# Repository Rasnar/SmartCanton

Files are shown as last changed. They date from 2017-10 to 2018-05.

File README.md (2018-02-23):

# Master Thesis - SmartCanton

This repository contain the Master Thesis relised by **Da Silva Andrade David** in collaboration with the DIRECTION GÉNÉRALE DES SYSTÈMES D'INFORMATION (**DGSI**).

The goal of this project is to devellop a device that can connect to a LoRaWAN and provide sensor data that can be trusted from a specific device.

A securised interface was also devellopped to delivers the APPKEY to the new device created. The principle of creation and storage is based on the Proof of Concept devellopped by the DGSI for the project SmartCanton.

## Hardware

A PCB has been devellopped for this project. 

- Bluetooth LE 4.2 : **MKW41Z512**
- LoRa : **CMWX1ZZABZ-078** (SX1276 + STM32L082)
- GPS : **NEO-M8Q** (only with external antenna)
- On board antennas for the LoRa and Bluetooth. Possibility to connect external antennas in both cases.
- 9 Axis inertial platform : **BNO055**
- Gas, temperature and humidity sensor : **BME680**
- 8 LEDs and 4 Buttons accessible both by the LoRa and Bluetooth microcontrollers
- 2 PMOD connectors (1 for each microcontroller)
- Possibility to connect a Li-Ion battery
- USB or Solar charging for the Li-Ion battery

The Altium layout of the board is avaiblable under the directory `SmartCanton\hardware\SmartCantonDevBox_V1_0`.

A case for the hardware has also been designed. You can find it under`SmartCanton\hardware\SmartCantonDevBoxCase`. It can be easily printed using a 3D printer.

## Software

### LoRaWAN

The software for the CMWX1ZZABZ-078 can be found under the directory `SmartCanton\dev\STM32CubeExpansion_LRWAN_V1.1.2`. It requires to be open with the STM32 Workbench IDE.

### Bluetooth

The software for the NXP KW41Z can be found under the directory `SmartCanton\dev\MKW41z`. It requires to be open with the MCUXpresso IDE.

### Android

An Application developed with Android Studio is available under the directory `SmartCanton\dev\SmartCantonManager`.

### Web Server

A web server developed using Python 3.6 and Pycharm has been developed. It run coupled with a SQLite to store all the information about the users and the DevBox (LoRaWAN et BLE configurations).

The project can be opened with Pycharm under the directory `SmartCanton\dev\SmartCanton_AppKeyServer`.

## Documentation

The final report of the project can be found in the root tree of the project under the name `[Da_Silva_Andrade_TM_2017-2018.pdf](https://github.com/Rasnar/SmartCanton/blob/master/Da_Silva_Andrade_TM_2017-2018.pdf)`. It's written in French, with appendices in English. The REST API documentation, an user guide for the Android application and all the BLE services developed can be found as appendices in the PDF file.

All the documentation can be found under the `SmartCanton\documentation` directory.

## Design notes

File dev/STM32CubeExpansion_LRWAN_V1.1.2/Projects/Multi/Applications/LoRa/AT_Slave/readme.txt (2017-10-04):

/**
  @page AT_Slave Readme file
 
  @verbatim
  ******************** (C) COPYRIGHT 2017 STMicroelectronics *******************
  * @file    AT_Slave/readme.txt 
  * @author  MCD Application Team
  * @version V1.1.2
  * @date    08-September-2017
  * @brief   This application is a simple demo application software of a LoRa
  *          modem controlled though AT command interface over UART by an
  *          external host
  ******************************************************************************
  * @attention
  *
  * <h2><center>&copy; Copyright (c) 2017 STMicroelectronics International N.V. 
  * All rights reserved.</center></h2>
  *
  * Redistribution and use in source and binary forms, with or without 
  * modification, are permitted, provided that the following conditions are met:
  *
  * 1. Redistribution of source code must retain the above copyright notice, 
  *    this list of conditions and the following disclaimer.
  * 2. Redistributions in binary form must reproduce the above copyright notice,
  *    this list of conditions and the following disclaimer in the documentation
  *    and/or other materials provided with the distribution.
  * 3. Neither the name of STMicroelectronics nor the names of other 
  *    contributors to this software may be used to endorse or promote products 
  *    derived from this software without specific written permission.
  * 4. This software, including modifications and/or derivative works of this 
  *    software, must execute solely and exclusively on microcontroller or
  *    microprocessor devices manufactured by or for STMicroelectronics.
  * 5. Redistribution and use of this software other than as permitted under 
  *    this license is void and will automatically terminate your rights under 
  *    this license. 
  *
  * THIS SOFTWARE IS PROVIDED BY STMICROELECTRONICS AND CONTRIBUTORS "AS IS" 
  * AND ANY EXPRESS, IMPLIED OR STATUTORY WARRANTIES, INCLUDING, BUT NOT 
  * LIMITED TO, THE IMPLIED WARRANTIES OF MERCHANTABILITY, FITNESS FOR A 
  * PARTICULAR PURPOSE AND NON-INFRINGEMENT OF THIRD PARTY INTELLECTUAL PROPERTY
  * RIGHTS ARE DISCLAIMED TO THE FULLEST EXTENT PERMITTED BY LAW. IN NO EVENT 
  * SHALL STMICROELECTRONICS OR CONTRIBUTORS BE LIABLE FOR ANY DIRECT, INDIRECT,
  * INCIDENTAL, SPECIAL, EXEMPLARY, OR CONSEQUENTIAL DAMAGES (INCLUDING, BUT NOT
  * LIMITED TO, PROCUREMENT OF SUBSTITUTE GOODS OR SERVICES; LOSS OF USE, DATA, 
  * OR PROFITS; OR BUSINESS INTERRUPTION) HOWEVER CAUSED AND ON ANY THEORY OF 
  * LIABILITY, WHETHER IN CONTRACT, STRICT LIABILITY, OR TORT (INCLUDING 
  * NEGLIGENCE OR OTHERWISE) ARISING IN ANY WAY OUT OF THE USE OF THIS SOFTWARE,
  * EVEN IF ADVISED OF THE POSSIBILITY OF SUCH DAMAGE.
  *
  ******************************************************************************
   @endverbatim

@par Description

This directory contains a set of source files that implements an example of a LoRa
modem that is controlled though AT command interface over UART by an external host,
like a computer executing a terminal.

This application is targeting the B-L072Z-LRWAN1 Discovery board embedding the
CMWX1ZZABZ-091 LoRa module.

This application uses the Cube Low Layer drivers APIs targeting the STM32L0
(embedded in the module) to optimize the code size.
  ******************************************************************************

@par Directory contents 

  - AT_Slave/Inc/at.h                     Header for at.c
  - AT_Slave/Inc/Comissioning.h           End device comissioning parameters
  - AT_Slave/Inc/command.h                Header for command.c
  - AT_Slave/Inc/debug.h                  Interface to debug functionally
  - AT_Slave/Inc/hw.h                     Group all hw interface
  - AT_Slave/Inc/hw_conf.h                File to manage Cube SW family used and debug switch
  - AT_Slave/Inc/hw_gpio.h                Header for hw_gpio.c
  - AT_Slave/Inc/hw_msp.h                 Header for driver hw msp module
  - AT_Slave/Inc/hw_rtc.h                 Header for hw_rtc.c
  - AT_Slave/Inc/hw_spi.h                 Header for hw_spi.c
  - AT_Slave/Inc/lora.h                   Header for lora.c
  - AT_Slave/Inc/mlm32l0xx_hw_conf.h      Definitions for mlm32l0xx HW configuration
  - AT_Slave/Inc/mlm32l0xx_it.h           Header for mlm32l0xx_it.c
  - AT_Slave/Inc/stm32l0xx_hal_conf.h     Library Configuration file
  - AT_Slave/Inc/tiny_sscanf.h            Header for tiny_sscanf.c
  - AT_Slave/Inc/tiny_vsnprintf.h         Header for tiny_vsnprintf.c
  - AT_Slave/Inc/vcom.h                   Interface to vcom.c
  - AT_Slave/Inc/version.h                Version file
  
  - AT_Slave/Src/at.c                     AT commands API
  - AT_Slave/Src/command.c                Definitions of AT commands
  - AT_Slave/Src/debug.c                  Debug driver
  - AT_Slave/Src/hw_gpio.c                Gpio driver
  - AT_Slave/Src/hw_rtc.c                 Rtc driver
  - AT_Slave/Src/hw_spi.c                 Spi driver
  - AT_Slave/Src/lora.c                   LoRa API to drive the LoRa state machine
  - AT_Slave/Src/main.c                   Main program file
  - AT_Slave/Src/mlm32l0xx_hw.c           MLM32l0xx specific hardware driver code
  - AT_Slave/Src/mlm32l0xx_it.c           MLM32l0xx Interrupt handlers
  - AT_Slave/Src/tiny_sscanf.c            Tiny implementation of sscanf() like function
  - AT_Slave/Src/tiny_vsnprintf.c         Tiny implementation of vsnprintf() like function
  - AT_Slave/Src/vcom.c                   Virtual com port interface on Terminal

@par Hardware and Software environment 

  - This example runs on the B-L072Z-LRWAN1 Discovery board embedding the
    CMWX1ZZABZ-091 LoRa module, and has been tested with STMicroelectronics
    B-L072Z-LRWAN1 RevC board.

  - B-L072Z-LRWAN1 Discovery board Set-up    
    - Connect the Nucleo board to your PC with a USB cable type A to micro-B 
      to ST-LINK connector (CN7).
    - Please ensure that the ST-LINK connector CN8 jumpers are fitted.
  -Set Up:

             --------------------------  V    V  --------------------------
             |      LoRa Object       |  |    |  |      LoRa Network      |
             |                        |  |    |  |                        |
   ComPort<--|                        |--|    |--|                        |-->Web Server
             |                        |          |                        |
             --------------------------          --------------------------

@par How to use it ? 
In order to make the program work, you must do the following :
  - Open your preferred toolchain 
  - Rebuild all files and load your image into target memory
  - Run the example
  - Open a Terminal, connected the LoRa Object
  - UART Config = 9600, 8b, 1 stopbit, no parity, no flow control ( in src/vcom.c)
  - Terminal Config: Select 'CR+LF' for Transmit New-Line and switch 'Local echo' on
  - Send your AT commands by typing them in the terminal
   
 * <h3><center>&copy; COPYRIGHT STMicroelectronics</center></h3>
 */

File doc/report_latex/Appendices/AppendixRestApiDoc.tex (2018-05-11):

% Appendix Template

\appendixpagenumbering % Restart numbering for each appendix

\chapter{AppKey Server: REST API Documentation} % Main appendix title
\label{AppendixRestApiDoc} 

This document contain all the routes available on the AppKeyServer. The \cref{figapdx-database_model} illustrate the database model used by the server.

\begin{figure}[ht!]
    \centering
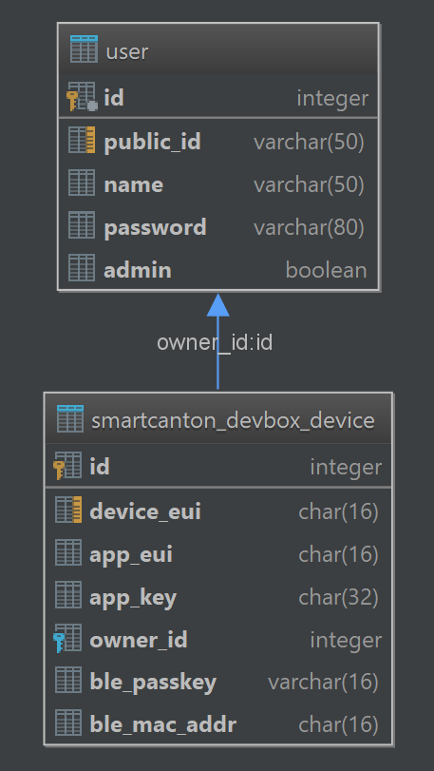
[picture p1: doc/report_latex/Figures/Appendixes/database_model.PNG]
    
    \caption{Database model}
    \label{figapdx-database_model}
\end{figure}

This documentation is also provided on the root path of the server : 

\begin{tcolorbox}[top=-3mm, bottom=-3mm, left=0mm, right=0mm, enhanced, breakable, colback=LightGray, colframe=DarkGray, colbacktitle=DarkGray]
\begin{minted}[bgcolor=LightGray,fontsize=\footnotesize,breaklines]{bash}
$ curl -X GET https://127.0.0.1:5000/
\end{minted}
\end{tcolorbox}

\clearpage
%%%%%%%%%%%%%%%%%%%%%%%%%%%%%%%%%%%%%%%%%%%%%%%%%%%%%%%%%%%
\section{Authentification}
%%%%%%%%%%%%%%%%%%%%%%%%%%%%%%%%%%%%%%%%%%%%%%%%%%%%%%%%%%%

\underline{Command rights} : Anyone can request a JWT token. The only requirement it that the user/password combinaison on the POST body is correct.\\

\textbf{Curl command for a JWT authentification :}

\begin{tcolorbox}[top=-3mm, bottom=-3mm, left=0mm, right=0mm, enhanced, breakable, colback=LightGray, colframe=DarkGray, colbacktitle=DarkGray]
\begin{minted}[bgcolor=LightGray,fontsize=\footnotesize,breaklines]{bash}
$ curl -X POST \
  http://127.0.0.1:5000/auth \
  -H 'cache-control: no-cache' \
  -H 'content-type: application/json' \
  -d '{
    "username": "<YOUR_USERNAME",
    "password": "<YOUR_PASSWORD>"
}'
\end{minted}
\end{tcolorbox}

\textbf{Example of a correct response (HTTP code 200) :}

\begin{tcolorbox}[top=-3mm, bottom=-3mm, left=0mm, right=0mm, enhanced, breakable, colback=LightGray, colframe=DarkGray, colbacktitle=DarkGray]
\begin{minted}[bgcolor=LightGray,fontsize=\footnotesize,breaklines]{bash}
{
    "access_token": "eyJ0eXAiOiJKV1QiLCJhbGciOiJIUzI1NiJ9.eyJleHAiOjE1MTg0ND
    g2MDcsImlhdCI6MTUxNTg1NjYwNywibmJmIjoxNTE1ODU2NjA3LCJqdGkiOiIyYmE5NDE2ZC
    1lOTVmLTQ3ZDktYmM0Ny0xOTY4MmY5NzlhMTMiLCJwdWJsaWNfaWQiOiJkZjQ1ZThlMi02ZT
    EwLTRlYmEtOGJjZC0yMjJjYWNlMjk3NGUiLCJmcmVzaCI6ZmFsc2UsInR5cGUiOiJhY2Nlc3
    MifQ.2XzkxKE-qDDtooZGfW2Gp5tYXISvnUH1QHibyGSAkAI"
}
\end{minted}
\end{tcolorbox}

\textbf{Token decrypted :} 

\begin{tcolorbox}[top=-3mm, bottom=-3mm, left=0mm, right=0mm, enhanced, breakable, colback=LightGray, colframe=DarkGray, colbacktitle=DarkGray]
\begin{minted}[bgcolor=LightGray,fontsize=\footnotesize,breaklines]{bash}
{
  "typ": "JWT",
  "alg": "HS256"
}
{
  "exp": 1518448607,
  "iat": 1515856607,
  "nbf": 1515856607,
  "jti": "2ba9416d-e95f-47d9-bc47-19682f979a13",
  "public_id": "df45e8e2-6e10-4eba-8bcd-222cace2974e",
  "fresh": false,
  "type": "access"
}
\end{minted}
\end{tcolorbox}

\clearpage
\section{User routes}

Those routes are only used to manage the user information. It does not interfer with the existing SmartCanton DevBox devices.

%%%%%%%%%%%%%%%%%%%%%%%%%%%%%%%%%%%%%%%%%%%%%%%%%%%%%%%%%%%
\subsection{Get all users}
%%%%%%%%%%%%%%%%%%%%%%%%%%%%%%%%%%%%%%%%%%%%%%%%%%%%%%%%%%%

\underline{Command rights} : \textbf{Admin only}\\

\textbf{Curl command :}

\begin{tcolorbox}[top=-3mm, bottom=-3mm, left=0mm, right=0mm, enhanced, breakable, colback=LightGray, colframe=DarkGray, colbacktitle=DarkGray]
\begin{minted}[bgcolor=LightGray,fontsize=\footnotesize,breaklines]{bash}
$ curl -X GET \
  https://127.0.0.1:5000/user/df45e8e2-6e10-4eba-8bcd-222cace2974e \
  -H 'authorization: JWT eyJ0eXAiOiJKV1QiLCJhbGciOiJIUzI1NiJ9.eyJl
  eHAiOjE1MTg0NDg2MDcsImlhdCI6MTUxNTg1NjYwNywibmJmIjoxNTE1ODU2NjA3
  LCJqdGkiOiIyYmE5NDE2ZC1lOTVmLTQ3ZDktYmM0Ny0xOTY4MmY5NzlhMTMiLCJw
  dWJsaWNfaWQiOiJkZjQ1ZThlMi02ZTEwLTRlYmEtOGJjZC0yMjJjYWNlMjk3NGUi
  LCJmcmVzaCI6ZmFsc2UsInR5cGUiOiJhY2Nlc3MifQ.2XzkxKE-qDDtooZGfW2Gp
  5tYXISvnUH1QHibyGSAkAI' \
  -H 'cache-control: no-cache'
\end{minted}
\end{tcolorbox}

\textbf{Example of a correct response (HTTP code 200) : }

\begin{tcolorbox}[top=-3mm, bottom=-3mm, left=0mm, right=0mm, enhanced, breakable, colback=LightGray, colframe=DarkGray, colbacktitle=DarkGray]
\begin{minted}[bgcolor=LightGray,fontsize=\footnotesize,breaklines]{bash}
{
    "users": [
        {
            "admin": true,
            "name": "Admin",
            "public_id": "df45e8e2-6e10-4eba-8bcd-222cace2974e"
        },
        {
            "admin": false,
            "name": "david",
            "public_id": "93cb11d2-bbdd-4d2a-8e66-e970e6d6bd25"
        },
        {
            "admin": true,
            "name": "david2",
            "public_id": "0b6a165d-5126-46da-bd0d-9d35bdda4bfd"
        }
    ]
}
\end{minted}
\end{tcolorbox}

%%%%%%%%%%%%%%%%%%%%%%%%%%%%%%%%%%%%%%%%%%%%%%%%%%%%%%%%%%%%%%%%%%%%%%%%%%%%%%%%%%%%%
\subsection{Get a specific user information from a public id}
%%%%%%%%%%%%%%%%%%%%%%%%%%%%%%%%%%%%%%%%%%%%%%%%%%%%%%%%%%%%%%%%%%%%%%%%%%%%%%%%%%%%%

\underline{Command rights} : Non admin users can only see their own profiles. Admin users can access all profiles.\\

\textbf{Curl command :}

\begin{tcolorbox}[top=-3mm, bottom=-3mm, left=0mm, right=0mm, enhanced, breakable, colback=LightGray, colframe=DarkGray, colbacktitle=DarkGray]
\begin{minted}[bgcolor=LightGray,fontsize=\footnotesize,breaklines]{bash}
$ curl -X GET \
  https://127.0.0.1:5000/user/df45e8e2-6e10-4eba-8bcd-222cace2974e \
  -H 'authorization: JWT eyJ0eXAiOiJKV1QiLCJhbGciOiJIUzI1NiJ9.eyJl
  eHAiOjE1MTg0NDg2MDcsImlhdCI6MTUxNTg1NjYwNywibmJmIjoxNTE1ODU2NjA3
  LCJqdGkiOiIyYmE5NDE2ZC1lOTVmLTQ3ZDktYmM0Ny0xOTY4MmY5NzlhMTMiLCJw
  dWJsaWNfaWQiOiJkZjQ1ZThlMi02ZTEwLTRlYmEtOGJjZC0yMjJjYWNlMjk3NGUi
  LCJmcmVzaCI6ZmFsc2UsInR5cGUiOiJhY2Nlc3MifQ.2XzkxKE-qDDtooZGfW2Gp
  5tYXISvnUH1QHibyGSAkAI' \
  -H 'cache-control: no-cache' 
\end{minted}
\end{tcolorbox}

\textbf{Example of a correct response (HTTP code 200) : }

\begin{tcolorbox}[top=-3mm, bottom=-3mm, left=0mm, right=0mm, enhanced, breakable, colback=LightGray, colframe=DarkGray, colbacktitle=DarkGray]
\begin{minted}[bgcolor=LightGray,fontsize=\footnotesize,breaklines]{bash}
{
    "admin": true,
    "public_id": "df45e8e2-6e10-4eba-8bcd-222cace2974e",
    "username": "Admin"
}
\end{minted}
\end{tcolorbox}

%%%%%%%%%%%%%%%%%%%%%%%%%%%%%%%%%%%%%%%%%%%%%%%%%%%%%%%%%%%%%%%%%%%%%%%%%%%%%%%%%%%%%
\subsection{Update information about a specific user}
%%%%%%%%%%%%%%%%%%%%%%%%%%%%%%%%%%%%%%%%%%%%%%%%%%%%%%%%%%%%%%%%%%%%%%%%%%%%%%%%%%%%%

\underline{Command rights} : Non admin users can only change their own profile and can't give themselves the Admin rights. They need to know their current password to be able to change it. Admin users can change all profiles and passwords, even if they don't know the old password.\\

\textbf{Curl command :}

\begin{tcolorbox}[top=-3mm, bottom=-3mm, left=0mm, right=0mm, enhanced, breakable, colback=LightGray, colframe=DarkGray, colbacktitle=DarkGray]
\begin{minted}[bgcolor=LightGray,fontsize=\footnotesize,breaklines]{bash}
$ curl -X PUT \
  https://127.0.0.1:5000/user/df45e8e2-6e10-4eba-8bcd-222cace2974e \
  -H 'authorization: JWT eyJ0eXAiOiJKV1QiLCJhbGciOiJIUzI1NiJ9.eyJl
  eHAiOjE1MTg0NDg2MDcsImlhdCI6MTUxNTg1NjYwNywibmJmIjoxNTE1ODU2NjA3
  LCJqdGkiOiIyYmE5NDE2ZC1lOTVmLTQ3ZDktYmM0Ny0xOTY4MmY5NzlhMTMiLCJw
  dWJsaWNfaWQiOiJkZjQ1ZThlMi02ZTEwLTRlYmEtOGJjZC0yMjJjYWNlMjk3NGUi
  LCJmcmVzaCI6ZmFsc2UsInR5cGUiOiJhY2Nlc3MifQ.2XzkxKE-qDDtooZGfW2Gp
  5tYXISvnUH1QHibyGSAkAI' \
  -H 'cache-control: no-cache' \
  -H 'content-type: application/json' \
  -d '{
	"password" : "test",
	"new_password" : "SmartCanton2017",
	"admin" : true
}'
\end{minted}
\end{tcolorbox}

\textbf{Example of a correct response (HTTP code 200) : }

\begin{tcolorbox}[top=-3mm, bottom=-3mm, left=0mm, right=0mm, enhanced, breakable, colback=LightGray, colframe=DarkGray, colbacktitle=DarkGray]
\begin{minted}[bgcolor=LightGray,fontsize=\footnotesize,breaklines]{bash}
{
    "message": "User information updated!"
}
\end{minted}
\end{tcolorbox}

%%%%%%%%%%%%%%%%%%%%%%%%%%%%%%%%%%%%%%%%%%%%%%%%%%%%%%%%%%%%%%%%%%%%%%%%%%%%%%%%%%%%%
\subsection{Create a new user}
%%%%%%%%%%%%%%%%%%%%%%%%%%%%%%%%%%%%%%%%%%%%%%%%%%%%%%%%%%%%%%%%%%%%%%%%%%%%%%%%%%%%%

\underline{Command rights} : \textbf{Admin only}\\

\textbf{Curl command :}

\begin{tcolorbox}[top=-3mm, bottom=-3mm, left=0mm, right=0mm, enhanced, breakable, colback=LightGray, colframe=DarkGray, colbacktitle=DarkGray]
\begin{minted}[bgcolor=LightGray,fontsize=\footnotesize,breaklines]{bash}
$ curl -X POST \
  http://127.0.0.1:5000/user \
  -H 'authorization: JWT eyJ0eXAiOiJKV1QiLCJhbGciOiJIUzI1NiJ9.eyJl
  eHAiOjE1MTg0NDg2MDcsImlhdCI6MTUxNTg1NjYwNywibmJmIjoxNTE1ODU2NjA3
  LCJqdGkiOiIyYmE5NDE2ZC1lOTVmLTQ3ZDktYmM0Ny0xOTY4MmY5NzlhMTMiLCJw
  dWJsaWNfaWQiOiJkZjQ1ZThlMi02ZTEwLTRlYmEtOGJjZC0yMjJjYWNlMjk3NGUi
  LCJmcmVzaCI6ZmFsc2UsInR5cGUiOiJhY2Nlc3MifQ.2XzkxKE-qDDtooZGfW2Gp
  5tYXISvnUH1QHibyGSAkAI' \
  -H 'cache-control: no-cache' \
  -H 'content-type: application/json' \
  -d '{"username": "david2", "password": "SmartCanton"}'
\end{minted}
\end{tcolorbox}

\newpage
\textbf{Example of a correct response (HTTP code 200) : }

\begin{tcolorbox}[top=-3mm, bottom=-3mm, left=0mm, right=0mm, enhanced, breakable, colback=LightGray, colframe=DarkGray, colbacktitle=DarkGray]
\begin{minted}[bgcolor=LightGray,fontsize=\footnotesize,breaklines]{bash}
{
    "message": "New user created!"
}
\end{minted}
\end{tcolorbox}

%%%%%%%%%%%%%%%%%%%%%%%%%%%%%%%%%%%%%%%%%%%%%%%%%%%%%%%%%%%%%%%%%%%%%%%%%%%%%%%%%%%%%
\subsection{Delete an existing user}
%%%%%%%%%%%%%%%%%%%%%%%%%%%%%%%%%%%%%%%%%%%%%%%%%%%%%%%%%%%%%%%%%%%%%%%%%%%%%%%%%%%%%
\underline{Command rights} : \textbf{Admin only}\\

\textbf{Curl command :}

\begin{tcolorbox}[top=-3mm, bottom=-3mm, left=0mm, right=0mm, enhanced, breakable, colback=LightGray, colframe=DarkGray, colbacktitle=DarkGray]
\begin{minted}[bgcolor=LightGray,fontsize=\footnotesize,breaklines]{bash}
$ curl -X DELETE \
  https://127.0.0.1:5000/user/88320280-42c6-4ad1-b747-cc4844580fa7 \
  -H 'authorization: JWT eyJ0eXAiOiJKV1QiLCJhbGciOiJIUzI1NiJ9.eyJl
  eHAiOjE1MTg0NDg2MDcsImlhdCI6MTUxNTg1NjYwNywibmJmIjoxNTE1ODU2NjA3
  LCJqdGkiOiIyYmE5NDE2ZC1lOTVmLTQ3ZDktYmM0Ny0xOTY4MmY5NzlhMTMiLCJw
  dWJsaWNfaWQiOiJkZjQ1ZThlMi02ZTEwLTRlYmEtOGJjZC0yMjJjYWNlMjk3NGUi
  LCJmcmVzaCI6ZmFsc2UsInR5cGUiOiJhY2Nlc3MifQ.2XzkxKE-qDDtooZGfW2Gp
  5tYXISvnUH1QHibyGSAkAI' \
  -H 'cache-control: no-cache' 
\end{minted}
\end{tcolorbox}

\textbf{Example of a correct response (HTTP code 200) : }

\begin{tcolorbox}[top=-3mm, bottom=-3mm, left=0mm, right=0mm, enhanced, breakable, colback=LightGray, colframe=DarkGray, colbacktitle=DarkGray]
\begin{minted}[bgcolor=LightGray,fontsize=\footnotesize,breaklines]{bash}
{
    "message": "The user has been deleted!"
}
\end{minted}
\end{tcolorbox}

%-----------------------------------------------------------------------------------%
\section{SmartCanton DevBox routes}
%-----------------------------------------------------------------------------------%
Those routes are only used to manage the DevBox devices. You will need to know the user informations to update or understand the \textit{owner\_public\_id} field. 
%%%%%%%%%%%%%%%%%%%%%%%%%%%%%%%%%%%%%%%%%%%%%%%%%%%%%%%%%%%%%%%%%%%%%%%%%%%%%%%%%%%%%
\subsection{Get all devices}
%%%%%%%%%%%%%%%%%%%%%%%%%%%%%%%%%%%%%%%%%%%%%%%%%%%%%%%%%%%%%%%%%%%%%%%%%%%%%%%%%%%%%
\underline{Command rights} : Non admin users can only see their own devices (those where their public id is used as the owner id). Admin users can see all devices.\\

\textbf{Curl command :}

\begin{tcolorbox}[top=-3mm, bottom=-3mm, left=0mm, right=0mm, enhanced, breakable, colback=LightGray, colframe=DarkGray, colbacktitle=DarkGray]
\begin{minted}[bgcolor=LightGray,fontsize=\footnotesize,breaklines]{bash}
$ curl -X GET \
  https://127.0.0.1:5000/device \
  -H 'authorization: JWT eyJ0eXAiOiJKV1QiLCJhbGciOiJIUzI1NiJ9.eyJl
  eHAiOjE1MTg0NDg2MDcsImlhdCI6MTUxNTg1NjYwNywibmJmIjoxNTE1ODU2NjA3
  LCJqdGkiOiIyYmE5NDE2ZC1lOTVmLTQ3ZDktYmM0Ny0xOTY4MmY5NzlhMTMiLCJw
  dWJsaWNfaWQiOiJkZjQ1ZThlMi02ZTEwLTRlYmEtOGJjZC0yMjJjYWNlMjk3NGUi
  LCJmcmVzaCI6ZmFsc2UsInR5cGUiOiJhY2Nlc3MifQ.2XzkxKE-qDDtooZGfW2Gp
  5tYXISvnUH1QHibyGSAkAI' \
  -H 'cache-control: no-cache' 
\end{minted}
\end{tcolorbox}

\newpage
\textbf{Example of a correct response (HTTP code 200) : }

\begin{tcolorbox}[top=-3mm, bottom=-3mm, left=0mm, right=0mm, enhanced, breakable, colback=LightGray, colframe=DarkGray, colbacktitle=DarkGray]
\begin{minted}[bgcolor=LightGray,fontsize=\footnotesize,breaklines]{bash}
{
    "devices": [
        {
            "ble_mac_addr": "006037000000",
            "dev_eui": "323831395C367815"
        },
        {
            "ble_mac_addr": "006037000001",
            "dev_eui": "323831395C367715"
        }
    ]
}
\end{minted}
\end{tcolorbox}

%%%%%%%%%%%%%%%%%%%%%%%%%%%%%%%%%%%%%%%%%%%%%%%%%%%%%%%%%%%%%%%%%%%%%%%%%%%%%%%%%%%%%
\subsection{Get information about a specific device}
%%%%%%%%%%%%%%%%%%%%%%%%%%%%%%%%%%%%%%%%%%%%%%%%%%%%%%%%%%%%%%%%%%%%%%%%%%%%%%%%%%%%%
\underline{Command rights} : Non admin users can only see their own devices (those where their public id is used as the owner id). Admin users can see all devices.\\

\textbf{Curl command :}

\begin{tcolorbox}[top=-3mm, bottom=-3mm, left=0mm, right=0mm, enhanced, breakable, colback=LightGray, colframe=DarkGray, colbacktitle=DarkGray]
\begin{minted}[bgcolor=LightGray,fontsize=\footnotesize,breaklines]{bash}
$ curl -X GET \
  https://127.0.0.1:5000/device/006037000001 \
  -H 'authorization: JWT eyJ0eXAiOiJKV1QiLCJhbGciOiJIUzI1NiJ9.eyJl
  eHAiOjE1MTg0NDg2MDcsImlhdCI6MTUxNTg1NjYwNywibmJmIjoxNTE1ODU2NjA3
  LCJqdGkiOiIyYmE5NDE2ZC1lOTVmLTQ3ZDktYmM0Ny0xOTY4MmY5NzlhMTMiLCJw
  dWJsaWNfaWQiOiJkZjQ1ZThlMi02ZTEwLTRlYmEtOGJjZC0yMjJjYWNlMjk3NGUi
  LCJmcmVzaCI6ZmFsc2UsInR5cGUiOiJhY2Nlc3MifQ.2XzkxKE-qDDtooZGfW2Gp
  5tYXISvnUH1QHibyGSAkAI' \
  -H 'cache-control: no-cache' 
\end{minted}
\end{tcolorbox}

\textbf{Example of a correct response (HTTP code 200) : }

\begin{tcolorbox}[top=-3mm, bottom=-3mm, left=0mm, right=0mm, enhanced, breakable, colback=LightGray, colframe=DarkGray, colbacktitle=DarkGray]
\begin{minted}[bgcolor=LightGray,fontsize=\footnotesize,breaklines]{bash}
{
    "app_eui": "<APP_EUI>",
    "app_key": "<APP_KEY>",
    "ble_mac_addr": "006037000001",
    "ble_passkey": "111100",
    "dev_eui": "323831395C367715",
    "owner_public_id": "df45e8e2-6e10-4eba-8bcd-222cace2974e"
}
\end{minted}
\end{tcolorbox}

%%%%%%%%%%%%%%%%%%%%%%%%%%%%%%%%%%%%%%%%%%%%%%%%%%%%%%%%%%%%%%%%%%%%%%%%%%%%%%%%%%%%%
\subsection{Create a new device}
%%%%%%%%%%%%%%%%%%%%%%%%%%%%%%%%%%%%%%%%%%%%%%%%%%%%%%%%%%%%%%%%%%%%%%%%%%%%%%%%%%%%%
\underline{Command rights} : Devices are automatically assigned to the authentified user for non admin users. An admin can change the \texttt{owner\_public\_id} field to transfer the ownership of a device.\\

\newpage
\textbf{Curl command :}

\begin{tcolorbox}[top=-3mm, bottom=-3mm, left=0mm, right=0mm, enhanced, breakable, colback=LightGray, colframe=DarkGray, colbacktitle=DarkGray]
\begin{minted}[bgcolor=LightGray,fontsize=\footnotesize,breaklines]{bash}
$ curl -X POST \
  http://127.0.0.1:5000/device \
  -H 'authorization: JWT eyJ0eXAiOiJKV1QiLCJhbGciOiJIUzI1NiJ9.eyJl
  eHAiOjE1MTg0NDg2MDcsImlhdCI6MTUxNTg1NjYwNywibmJmIjoxNTE1ODU2NjA3
  LCJqdGkiOiIyYmE5NDE2ZC1lOTVmLTQ3ZDktYmM0Ny0xOTY4MmY5NzlhMTMiLCJw
  dWJsaWNfaWQiOiJkZjQ1ZThlMi02ZTEwLTRlYmEtOGJjZC0yMjJjYWNlMjk3NGUi
  LCJmcmVzaCI6ZmFsc2UsInR5cGUiOiJhY2Nlc3MifQ.2XzkxKE-qDDtooZGfW2Gp
  5tYXISvnUH1QHibyGSAkAI' \
  -H 'cache-control: no-cache' \
  -H 'content-type: application/json' \
  -d '{
    "app_eui": "<APP_EUI>",
    "app_key": "<APP_KEY>",
    "dev_eui": "323831395C367801",
    "ble_mac_addr": "006037000005",
    "ble_passkey": "111111",
    "owner_public_id": "df45e8e2-6e10-4eba-8bcd-222cace2974e"
}'
\end{minted}
\end{tcolorbox}

\textbf{Example of a correct response (HTTP code 200) : }

\begin{tcolorbox}[top=-3mm, bottom=-3mm, left=0mm, right=0mm, enhanced, breakable, colback=LightGray, colframe=DarkGray, colbacktitle=DarkGray]
\begin{minted}[bgcolor=LightGray,fontsize=\footnotesize,breaklines]{bash}
{
    "message": "New device created!"
}
\end{minted}
\end{tcolorbox}

%%%%%%%%%%%%%%%%%%%%%%%%%%%%%%%%%%%%%%%%%%%%%%%%%%%%%%%%%%%%%%%%%%%%%%%%%%%%%%%%%%%%%
\subsection{Update an existing device}
%%%%%%%%%%%%%%%%%%%%%%%%%%%%%%%%%%%%%%%%%%%%%%%%%%%%%%%%%%%%%%%%%%%%%%%%%%%%%%%%%%%%%
\underline{Command rights} : Non admin users can only edit their own devices (those where their public id is used as the owner id). Admin users can edit all devices.\\

\textbf{Curl command to edit a specidic field (ble passkey in this case):}

\begin{tcolorbox}[top=-3mm, bottom=-3mm, left=0mm, right=0mm, enhanced, breakable, colback=LightGray, colframe=DarkGray, colbacktitle=DarkGray]
\begin{minted}[bgcolor=LightGray,fontsize=\footnotesize,breaklines]{bash}
$ curl -X PUT \
  http://127.0.0.1:5000/device \
  -H 'authorization: JWT eyJ0eXAiOiJKV1QiLCJhbGciOiJIUzI1NiJ9.eyJl
  eHAiOjE1MTg0NDg2MDcsImlhdCI6MTUxNTg1NjYwNywibmJmIjoxNTE1ODU2NjA3
  LCJqdGkiOiIyYmE5NDE2ZC1lOTVmLTQ3ZDktYmM0Ny0xOTY4MmY5NzlhMTMiLCJw
  dWJsaWNfaWQiOiJkZjQ1ZThlMi02ZTEwLTRlYmEtOGJjZC0yMjJjYWNlMjk3NGUi
  LCJmcmVzaCI6ZmFsc2UsInR5cGUiOiJhY2Nlc3MifQ.2XzkxKE-qDDtooZGfW2Gp
  5tYXISvnUH1QHibyGSAkAI' \
  -H 'cache-control: no-cache' \
  -H 'content-type: application/json' \
  -d '{
    "ble_passkey": "111122",
}'
\end{minted}
\end{tcolorbox}

\textbf{Example of a correct response (HTTP code 200) : }

\begin{tcolorbox}[top=-3mm, bottom=-3mm, left=0mm, right=0mm, enhanced, breakable, colback=LightGray, colframe=DarkGray, colbacktitle=DarkGray]
\begin{minted}[bgcolor=LightGray,fontsize=\footnotesize,breaklines]{bash}
{
    "message": "Device updated successfully!"
}
\end{minted}
\end{tcolorbox}

%%%%%%%%%%%%%%%%%%%%%%%%%%%%%%%%%%%%%%%%%%%%%%%%%%%%%%%%%%%%%%%%%%%%%%%%%%%%%%%%%%%%%
\subsection{Delete an existing device}
%%%%%%%%%%%%%%%%%%%%%%%%%%%%%%%%%%%%%%%%%%%%%%%%%%%%%%%%%%%%%%%%%%%%%%%%%%%%%%%%%%%%%
\underline{Command rights} : Non admin users can only edit their own devices (those where their public id is used as the owner id). Admin users can edit all devices.\\

\newpage
\textbf{Curl command :}

\begin{tcolorbox}[top=-3mm, bottom=-3mm, left=0mm, right=0mm, enhanced, breakable, colback=LightGray, colframe=DarkGray, colbacktitle=DarkGray]
\begin{minted}[bgcolor=LightGray,fontsize=\footnotesize,breaklines]{bash}
$ curl -X DELETE \
  http://127.0.0.1:5000/device/006037000005 \
  -H 'authorization: JWT eyJ0eXAiOiJKV1QiLCJhbGciOiJIUzI1NiJ9.eyJl
  eHAiOjE1MTg0NDg2MDcsImlhdCI6MTUxNTg1NjYwNywibmJmIjoxNTE1ODU2NjA3
  LCJqdGkiOiIyYmE5NDE2ZC1lOTVmLTQ3ZDktYmM0Ny0xOTY4MmY5NzlhMTMiLCJw
  dWJsaWNfaWQiOiJkZjQ1ZThlMi02ZTEwLTRlYmEtOGJjZC0yMjJjYWNlMjk3NGUi
  LCJmcmVzaCI6ZmFsc2UsInR5cGUiOiJhY2Nlc3MifQ.2XzkxKE-qDDtooZGfW2Gp
  5tYXISvnUH1QHibyGSAkAI' \
  -H 'cache-control: no-cache'
\end{minted}
\end{tcolorbox}

\textbf{Example of a correct response (HTTP code 200) : }

\begin{tcolorbox}[top=-3mm, bottom=-3mm, left=0mm, right=0mm, enhanced, breakable, colback=LightGray, colframe=DarkGray, colbacktitle=DarkGray]
\begin{minted}[bgcolor=LightGray,fontsize=\footnotesize,breaklines]{bash}
{
    "message": "SmartCanton Devbox item deleted!"
}
\end{minted}
\end{tcolorbox}

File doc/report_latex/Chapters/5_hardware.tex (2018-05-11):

\chapter{Conception matérielle}
\label{3_hardware}

Ce chapitre présente toute l'implémentation de la carte électronique qui a été réalisée dans le cadre de ce projet. La description des composants, de même que le choix de ceux-ci y sont évoqués.

\section{Introduction}

Le présent projet avait pour objectif premier la réalisation d'une carte électronique. Les différents composants à placer sur cette carte ont été choisis en fonction des besoins de certains \textit{use cases} exposés à la DGSI. Voici une liste contenant quelques exemples : 
\begin{itemize}
    \item Un traqueur GPS transmettant la position par LoRa;
    \item Un détecteur de vol avec détection de mouvement transmettant ensuite la position par LoRa une fois l'objet en mouvement;
    \item Un scanneur Bluetooth permettant de détecter un certain nombre de \textit{beacons} autour d'une borne;
    \item Une station météorologique avec la possibilité de mesurer la qualité de l'air ambiant.
\end{itemize}

Ces exemples ont ainsi permis la mise en place d'une liste de périphériques indispensables à la carte.\\

Un nouveau concept de partage de clé a également été imaginé, avec la possibilité de changer l’App Key LoRaWAN présente sur le périphérique via l'utilisation d'un simple smartphone. Il fallait dès lors choisir une méthode d'accès au périphérique. La quantité de données transférées étant faible (de l'ordre de quelques centaines de bytes par secondes, au grand maximum) et le dispositif devant être utilisable sur batterie, le Bluetooth Low Energy a été retenu. Le Bluetooth est une technologie qui avait déjà été retenue pour l'implémentation du scanneur de périphériques.\\

Tous les documents liés au circuit électronique (schémas, modèles 3D et footprints) sont disponibles dans l'\cref{AppendixDevBoxHardware}.

\section{Architecture}

Pour une plus grande flexibilité de la carte de développement, il est judicieux d'utiliser deux processeurs sur la carte électronique, ce qui implique deux implémentations possibles. Les \cref{fig-hardware_option1} et \cref{fig-hardware_option2} illustrent ces deux options. La première consiste à utilise un processeur LoRa comme processeur principal du système; soit un processeur sur lequel la communication LoRa est gérée en plus de la gestion des différents périphériques de la carte. Par exemple, un GPS, un accéléromètre, etc. Le processeur gérant le Bluetooth serait ainsi un simple périphérique pour le processeur LoRa. Une API doit être mise en place pour faciliter l'échange d'informations entre les deux. La deuxième possibilité est d'inverser les rôles des processeurs. Le processeur principal serait celui qui gère les protocoles en 2.4 GHz et communique périodiquement avec le processeur LoRa afin d'envoyer et recevoir des données provenant du réseau.

\begin{figure}[ht!]
    \centering
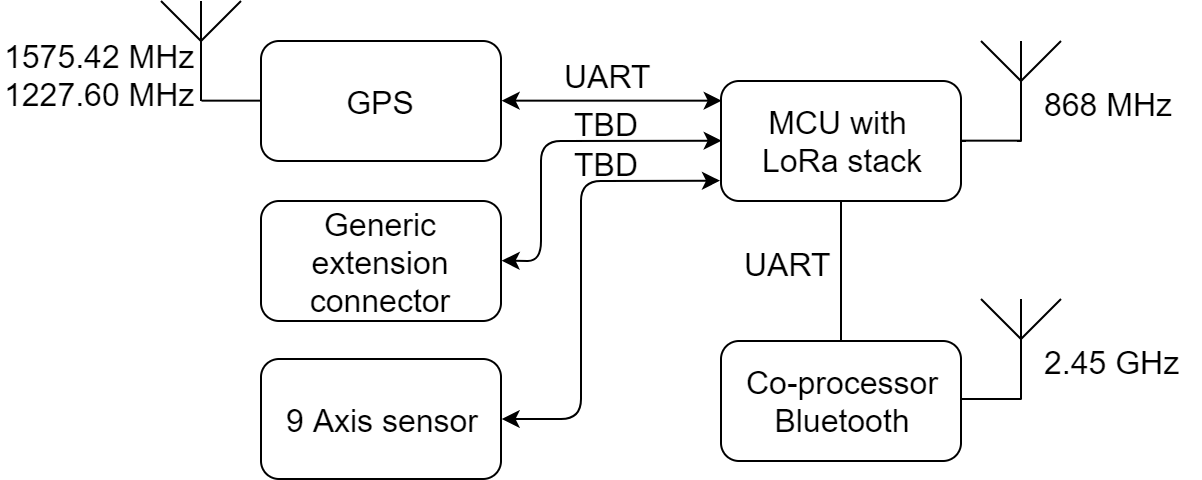
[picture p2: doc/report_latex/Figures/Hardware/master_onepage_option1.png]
    
    \caption{Architecture option numéro 1}
    \label{fig-hardware_option1}
\end{figure}

\begin{figure}[ht!]
    \centering
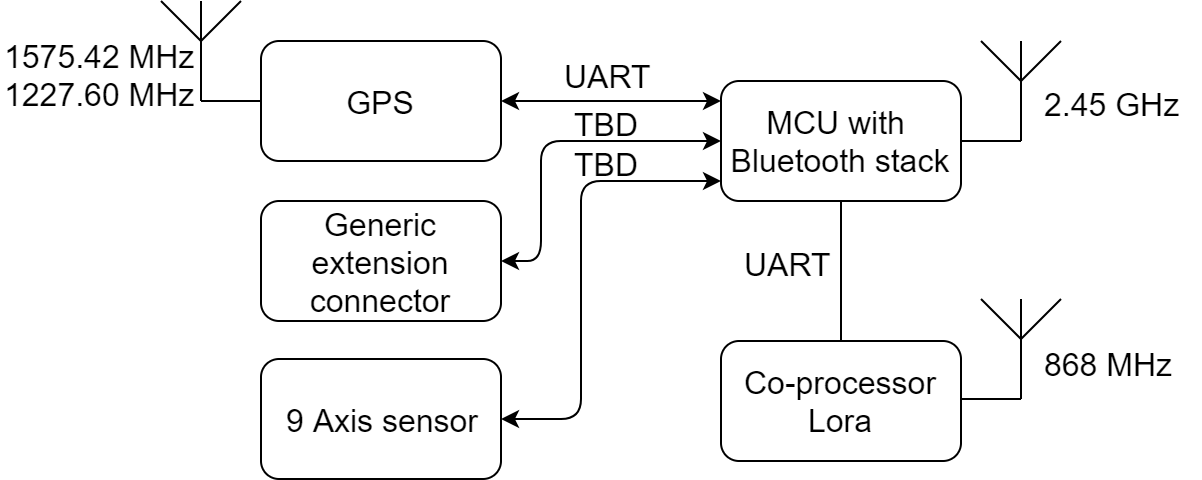
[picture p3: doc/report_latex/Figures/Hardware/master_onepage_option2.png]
    
    \caption{Architecture option numéro 2}
    \label{fig-hardware_option2}
\end{figure}

L'architecture choisie est l'option numéro 2. Nous avons donc tous les périphériques qui sont connectés au processeur s'occupant du Bluetooth. Le processeur avec l'interface LoRa, lui ne s'occupe, quant à lui, que de communiquer les évènements de réception de données et de transférer les messages provenant depuis le processeur Bluetooth. Il est également plus simple de faire une API pour le LoRa, le nombre de données et paramètres configurables étant moins important que dans le cas des communications Bluetooth. Si on souhaite faire une API entre les deux processeurs, il est ainsi nécessaire de tenir compte de la complexité de ceux-ci. Les accès LoRa sont également plus ponctuels. Le nombre de paquets envoyés par heures est très faible, en comparaison avec ce qui est réalisable en Bluetooth. On peut ainsi faire en sorte que le processeur soit en mode très basse consommation en attendant une commande de la part du processeur principal ou la réception d'un paquet LoRa sur son antenne.

\section{Choix des composants et leurs caractéristiques}

Cette section a pour but d'une part d'expliquer les différents choix effectués pour les composants présents sur la DevBox et, d'autre part, de présenter les caractéristiques principales des composants les plus importants.

\subsection{Microcontrôleur}
\label{subsect:microcontroleur}

Le microcontrôleur est le c\oe ur de ce projet; c'est dans celui-ci que la plus grande partie du développement va se produire. Il est dès lors important de sélectionner le composant idéal pour notre application, car une fois la sélection faite et les cartes électroniques réalisées, il est impossible de le changer sans générer des changements conséquents. Pour éviter cela, une étude des divers microcontrôleurs disponibles sur le marché a été réalisée.

\subsubsection{Critères de comparaison}
Le microcontrôleur a dû être choisi judicieusement en fonction du cahier des charges. Un comparatif, visible sur le \cref{tab-mcu_table}, a donc été effectué.  L'un des premiers points retenus est le type de protocoles qui sont supportés par le microcontrôleur. Le Bluetooth Low Energy étant un prérequis, il nous a été possible de procéder à un premier filtre, ce qui explique également que tous les microcontrôleurs affichés disposent de cette fonctionnalité. Néanmoins, le Bluetooth Low Energy s'accompagne de la norme 4.2, annoncée le 2 décembre 2014 \cite{Bluetoot59:online}, et de la norme 5.0, annoncée quant à elle le 16 juin 2016. Cette dernière n'était malheureusement pas encore parfaitement supportée par tous les fabricants de microcontrôleurs. Comme précédemment expliqué en \cref{sec_2_4_GHz}, une simple mise à jour logicielle permet de promouvoir un microcontrôleur en Bluetooth 5.0, du moins, en garantissant les fonctionnalités primordiales du protocole. Les microcontrôleurs affichés dans le tableau disposaient, en date du 1er octobre 2017, uniquement des fonctionnalités listées, ce qui ne signifie toutefois pas qu'elles ne peuvent pas s'agrandir avec le temps. \\

Après le Bluetooth, le deuxième type de protocole est le IEEE 802.15.4 \cite{IEEE802137:online}. Ce standard IEEE n'est pas un protocole en tant que tel, mais un modèle qui est respecté par plusieurs protocoles. Parmi les protocoles qui utilisent ce standard, on retrouve le ZigBee, WirelessHART, MiWi, SNAP, ou encore le Thread. Ce standard est de plus en plus utilisé pour la domotique. En effet, il permet de facilement créer des réseaux maillés permettant ainsi une grande couverture de l'habitation.\\

Enfin, un moyen de communication en dessous d'un gigahertz était également envisageable. Si le processeur supporte cela, ce peut être un avantage pour la réalisation de futurs \textit{use cases}. Néanmoins, la communication dans cette plage de fréquence a quelques désavantages, en commençant par la taille de l'antenne qu'il faut utiliser. La consommation du processeur est également affectée, pouvant atteindre jusqu'à 100 mA (cf. EFR32M datasheet). LoRa entre dans cette catégorie, mais seuls les processeurs fournis par Semtech peuvent implémenter la modulation. Ils ne sont, à l'heure actuelle, pas assez développés pour pouvoir être utilisés comme unique processeur gérant du 2.4 GHz avec en parallèle une interface LoRa (868 ou 433 MHz). \\

On a ensuite l'aspect consommation lors de l'émission qui entre en jeu. Afin d'être le plus proche possible en termes de comparaison entre les différents modèles, la consommation en émission a été retenue pour la fréquence de 2.4 GHz avec une puissance de 0 dBm en sortie. Plus cette consommation est faible, plus notre système aura la possibilité d'être autonome grâce à sa batterie. Finalement, les deux derniers points à retenir sont la taille des mémoires (RAM et Flash), qui selon leur taille nous permettent de faire un programme plus complexe, puis le coût à l'unité du microcontrôleur. Les prix ont été sélectionnés pour une seule unité sur le site d'achat Mouser\footnote{\url{http://www.mouser.ch/}} Suisse. \,

Davantage d'éléments auraient pu être pris en compte pour la comparaison, à l'instar des périphériques disponibles ou la possibilité d'avoir une matrice d'assignation des pins, utile lorsque l'on souhaite avoir des cartes modulables. Ce qui est primordial, c'est d'avoir au minimum une interface de communication série (SPI, I2C ou UART), étant précisé que tous ces microcontrôleurs en ont plusieurs de disponibles. Il convient également de prendre en considération la consommation du microcontrôleur, surtout dans les modes de sommeil. Celle-ci se trouve dans la même plage pour tous les microcontrôleurs listés, soit aux environs des 200\,\si{\micro}A avec une vitesse du microcontrôleur réduite au minimum, tous les périphériques désactivés et la persistance des données en RAM. Pour sortir de ces modes, le réveil émane habituellement d'une interruption matérielle, de sorte à pouvoir continuer à exécuter le code une fois sorti de veille. Vu que la carte de développement finale sera équipée d'un GPS, lequel sera le point principal de la consommation, cette donnée n'a pas été intégrée dans le tableau, bien qu'elle soit observée sur chaque microcontrôleur.\\

\begin{sidewaystable}[!ht]
\centering
\caption{Comparaison des microcontrôleurs envisagés pour le projet}
\begin{tabular}{|l|l|l|c|c|c|c|l|l|c|c|l|}
\hline
\multicolumn{1}{|c|}{\textbf{Manufacturer}} & \multicolumn{1}{c|}{\textbf{Model}} & \multicolumn{1}{c|}{\textbf{CPU}} & \textbf{\begin{tabular}[c]{@{}c@{}}BLE\\ 4.2\end{tabular}} & \textbf{\begin{tabular}[c]{@{}c@{}}BLE\\ 5.0\end{tabular}} & \textbf{\begin{tabular}[c]{@{}c@{}}IEEE\\     802.15.4\end{tabular}} & \textbf{\begin{tabular}[c]{@{}c@{}}Sub\\     1GHz\end{tabular}} & \multicolumn{1}{c|}{\textbf{\begin{tabular}[c]{@{}c@{}}Receive \\     Current\end{tabular}}} & \multicolumn{1}{c|}{\textbf{\begin{tabular}[c]{@{}c@{}}Transmit\\ Current \\ (@ 2.4Ghz, \\ @ 0dBm)\end{tabular}}} & \textbf{\begin{tabular}[c]{@{}c@{}}Flash/\\     SRAM\end{tabular}} & \textbf{\begin{tabular}[c]{@{}c@{}}Disponi-\\     bility\end{tabular}} & \multicolumn{1}{c|}{\textbf{Price}} \\ \hline
NXP & KW41Z & \begin{tabular}[c]{@{}l@{}}Cortex\\ M0+\\@ 48 MHz\end{tabular} & Yes & No & Yes & No & 6.8 mA & 6.1 mA & \begin{tabular}[c]{@{}c@{}}512 kB\\ / 128 kB\end{tabular} & Yes & 6.34 CHF \\ \hline
NXP & QN908x & \begin{tabular}[c]{@{}l@{}}Cortex\\ M4F\\@ 32 MHz\end{tabular} & Yes & Yes & No & No & 3.4 mA & 3.4 mA & \begin{tabular}[c]{@{}c@{}}512 kB\\ / 128 kB\end{tabular} & Yes & 5.87 CHF \\ \hline
\begin{tabular}[c]{@{}l@{}}Texas\\     Instrument\end{tabular} & CC2650 & \begin{tabular}[c]{@{}l@{}}Cortex\\ M3\\@ 48 MHz\\+ M0 for RF\end{tabular} & Yes & No & Yes & No & 6.2 mA & 6.8 mA & \begin{tabular}[c]{@{}c@{}}128 kB\\ / 20 kB\end{tabular} & Yes & 6.34 CHF \\ \hline
\begin{tabular}[c]{@{}l@{}}Texas\\     Instrument\end{tabular} & CC2640R2F & \begin{tabular}[c]{@{}l@{}}Cortex\\ M3\\@ 48 MHz\\+ M0 for RF\end{tabular} & Yes & Yes & No & No & 6.1 mA & 7.0 mA & \begin{tabular}[c]{@{}c@{}}128 kB\\ / 20 kB\end{tabular} & Yes & 6.34 CHF \\ \hline
\begin{tabular}[c]{@{}l@{}}Nordic \\     Semiconductor\end{tabular} & NRF52832 & \begin{tabular}[c]{@{}l@{}}Cortex\\ M4F\\@ 64 MHz\end{tabular} & Yes & Yes & No & No & 5.4 mA & 5.3 mA & \begin{tabular}[c]{@{}c@{}}512 kB\\ / 64 kB\end{tabular} & Yes & 5.51 CHF \\ \hline
\begin{tabular}[c]{@{}l@{}}Nordic \\     Semiconductor\end{tabular} & NRF52840 & \begin{tabular}[c]{@{}l@{}}Cortex\\ M4F\\@ 64 MHz\end{tabular} & Yes & Yes & Yes & No & N/A & N/A & \begin{tabular}[c]{@{}c@{}}1MB /\\     256 kB\end{tabular} & No & N/A \\ \hline
Silicon Labs & \begin{tabular}[c]{@{}l@{}}EFR32M\\ G12P433\\ F1024\end{tabular} & \begin{tabular}[c]{@{}l@{}}Cortex\\ M4F\\@ 38 MHz\end{tabular} & Yes & Yes & Yes & Yes & 9.3 mA & 9.5 mA & \begin{tabular}[c]{@{}c@{}}1MB /\\     256 kB\end{tabular} & Yes & 13.5 CHF \\ \hline
\end{tabular}
\label{tab-mcu_table}
\end{sidewaystable}

\subsubsection{Comparaisons et choix}
\label{sec-hardware_mcu_compare}

Pour une comparaison, il est nécessaire d'analyser les microcontrôleurs listés dans le \cref{tab-mcu_table}. Tout d'abord, le seul qui intègre tous les protocoles de communication est le Silicon Labs EFR32MG12P433F1024\footnote{\url{https://www.silabs.com/products/wireless/mesh-networking/efr32mg-mighty-gecko-zigbee-thread-soc/device.EFR32MG12P433F1024}}. En effet, celui-ci dispose de multiples interfaces et le support pour la dernière technologie Bluetooth. Il a tout pour son avantage excepté deux choses: son prix et sa consommation. Il est presque trois fois plus cher qu'un NRF52832, bien qu'au final ce prix soit compréhensif, puisque celui-ci supporte 2 protocoles supplémentaires. Vient ensuite la problématique de la consommation. Si l'on compare sa consommation à 2.4 GHz, elle est plus élevée que tous les microcontrôleurs présents sur le \cref{tab-mcu_table}. Si le projet nécessitait absolument l'utilisation de tous ces protocoles en parallèle, ce microcontrôleur serait alors le meilleur choix. Cela étant, c'est surtout le Bluetooth qui présente un intérêt pour le projet.\\

Le CC2650\footnote{\url{http://www.ti.com/product/CC2650}} du constructeur Texas Instruments est un microcontrôleur très utilisé dans le commerce, mais qui présente un défaut majeur, la taille de sa mémoire. En effet, ses 128 KB de flash et, surtout ses 20 kB de RAM, sont très limitatifs en termes de performances. Dans les besoins du projet, plusieurs tâches communiqueront en parallèle les unes avec les autres, avec des transferts de données qui engendreront des allocations mémoire diverses et conséquentes. Vient ensuite la création des données et l'utilisation de bibliothèques externes pour certains capteurs. Cela implique beaucoup de codes, en particulier si l'on se trouve dans une approche de prototypage où l'optimisation logicielle n'est pas forcément une priorité dès le départ. Le CC2650 et le CC2640R2F\footnote{\url{http://www.ti.com/product/CC2640R2F}} présentent tous deux cette problématique; ils sont équipés d'un dual processeur, d'un M3 pour l'application et d'un M0 pour la gestion des communications Bluetooth. L'avantage du CC2640R2F est qu'il supporte également le BLE 5.0 au détriment de l'IEEE 802.15.4. TI a d'ores et déjà annoncé qu'il ne prévoit pas de développement pour le BLE 5.0 sur le CC2650 \cite{CC2650Bl25:online}.\\

Il reste donc quatre microcontrôleurs qui semblent intéressants dans cette liste. Deux du fabricant NXP et deux du fabricant Nordic Semiconductor. Parmi ceux-ci, il y a le NRF52840, soit le microcontrôleur parfait pour notre application. Il est dans la même gamme de prix que ses concurrents et possède deux très grandes mémoires (flash et RAM). Il a comme avantage de supporter le Bluetooth et l'IEEE 802.15.4. Il est équipé d'un Cortex M4F à 64 MHz, ce qui fait de lui le processeur le plus performant parmi les sept du \cref{tab-mcu_table} (à égalité avec le NRF52832). Sa consommation n'étant pas encore connue au démarrage du projet, celle-ci n'a pas été spécifiée dans le tableau. Malheureusement, lorsque ce projet a commencé, le NRF52840 n'était disponible à la vente chez aucun fournisseur. La documentation du fabricant ne se résumait, à l'époque, qu'à une simple \textit{datasheet} minimaliste, sans aucun guide utilisateur complet. À l'heure de la rédaction de ce rapport (janvier 2018), une version BGA 125 pins est disponible, malheureusement avec quelques mois de retard pour notre application. Malgré le fait que ce microcontrôleur soit en BGA, il s'agit là certainement de l'un des meilleurs choix pour une application Bluetooth. La version NRF52832 a des caractéristiques identiques au NRF52840, excepté le fait qu'il ne supporte que du Bluetooth Low Energy.\\

NXP offre également plusieurs microcontrôleurs dans la gamme de fréquences 2.4GHz qui sont orientés basse consommation. Les deux plus intéressants sont le QN908x et le KW41Z. Le KW41Z est équipé d'un CPU Cortex-M0+ de ARM alors que le QN908x est quant à lui pourvu d'un M4F. Malgré un M0+, le KW41Z a comme atout le fait de pouvoir supporter la spécification IEEE 802.15.4 et, surtout, le protocole Thread précédemment présenté dans la \cref{sec-thread_protocol}. Ces deux protocoles peuvent être utilisés en parallèle, ouvrant ainsi la possibilité de créer des ponts entre ces deux mondes. \\

En somme, le choix s'articule autour du NRF52832 et du KW41Z. Finalement, le microcontrôleur retenu a été le KW41Z de NXP. Celui-ci a été initialement développé par l'entreprise Freescale, qui depuis le développement de ce produit a été rachetée par NXP. Un argument intéressant est le fait que le KW41Z puisse être connecté à la fois un réseau Bluetooth LE et à un réseau IEEE 802.15.4. Sa connectivité à un réseau Thread est également un avantage si l'on souhaite utiliser la carte dans un milieu plus \textit{SmartHome} que \textit{SmartCities}. Bien qu'il n'utilise qu'un Cortex-M0 de ARM, pour le type d'application que l'on souhaite réaliser, la puissance de calcul n'est pas le prérequis le plus important. C'est donc le KW41Z qui a été retenu pour ce projet. 

\FloatBarrier
\subsubsection{NXP Kinetis KW41Z}
\label{sec-hardware_kw41z}

La \cref{fig-KW41Z_block_diagram} illustre le contenu du KW41Z avec tous ses composants internes. On remarque des éléments intéressants dans la section \textit{security}, soit un support de chiffrement AES-128 et la possibilité de générer des nombres aléatoires avec un \textit{True Random Number Generator} (TRNG). Ces deux éléments ne visent pas un but précis dans le cadre des applications présentées dans ce projet, mais si l'utilisateur souhaite un grand niveau de sécurité, il a la possibilité d'accéder à ces deux éléments.\\

\begin{figure}[ht!]
    \centering
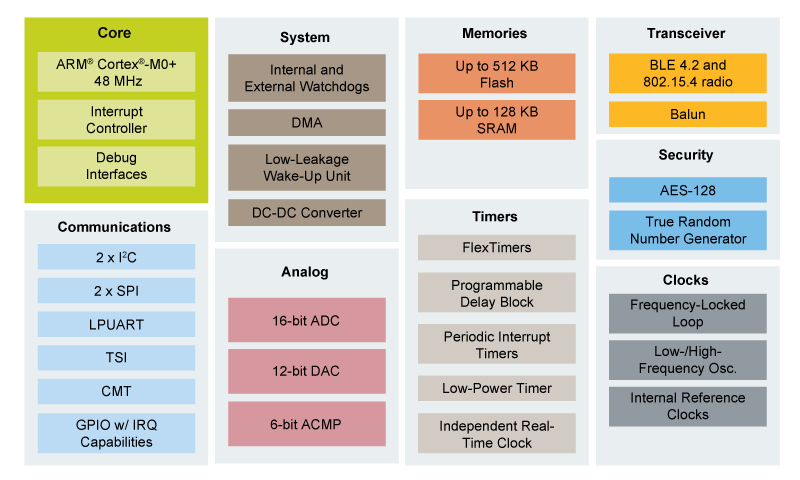
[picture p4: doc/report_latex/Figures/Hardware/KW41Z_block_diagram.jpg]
    
    \caption{Diagramme bloc interne du KW41Z}
    \label{fig-KW41Z_block_diagram}
\end{figure}

Une fois le microcontrôleur choisi, il était nécessaire de déterminer, les types d'interfaces allant être utilisées pour les différentes communications sur la DevBox. On peut voir sur \cref{fig-KW41Z_block_diagram} la présence de deux interfaces I2C, de deux SPI et d'une LPUART. Celle en UART a été réservée pour la communication entre le microcontrôleur Bluetooth et le coprocesseur LoRa. L'UART offre l'implémentation la plus versatile dans ce type de communication. Il peut y avoir des messages asynchrones provenant du coprocesseur selon le type de protocole de communication que l'utilisateur souhaite utiliser entre les deux éléments. Des interfaces SPI et I2C sont utilisées par les composants inclus sur la carte électronique. Cette même interface SPI est partagée avec un connecteur PMOD installé sur la DevBox. Une deuxième interface I2C est quant à elle réservée au port PMOD. Pour une vue d'ensemble des interfaces de communication et leurs connexions sur la carte DevBox, il est conseillé de visualiser le schéma Altium en \cref{AppendixDevBoxHardware}, sur le schéma nommé \texttt{Top View}.\\

\begin{figure}[ht!]
    \centering
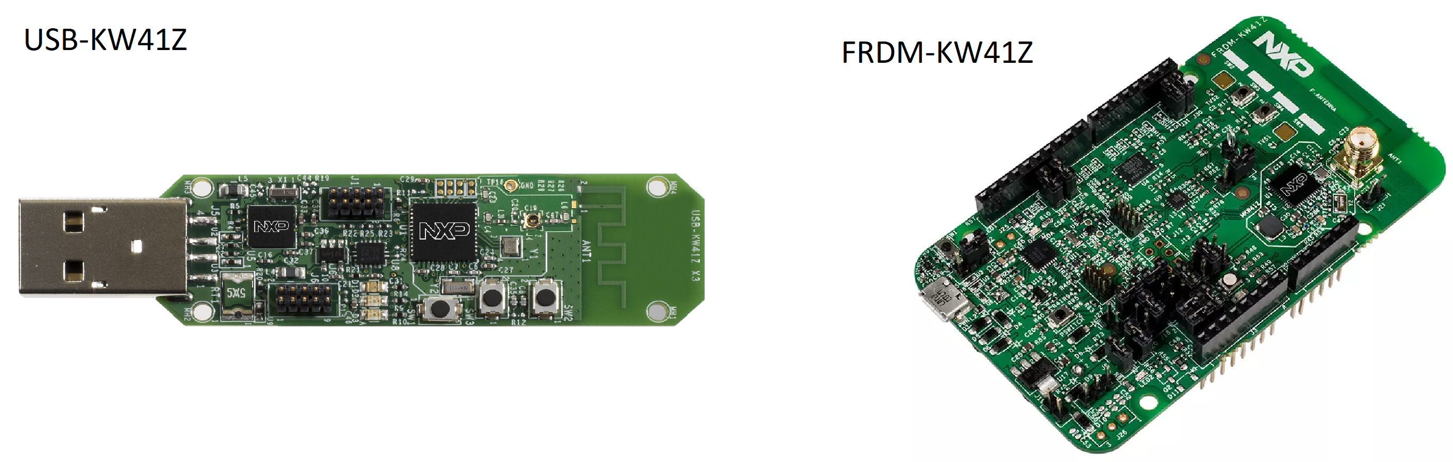
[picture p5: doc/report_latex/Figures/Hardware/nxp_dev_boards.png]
    
    \caption{Cartes de développement pour KW41Z}
    \label{fig-nxp_dev_boards}
\end{figure}

NXP propose deux cartes de développement avec le KW41Z visibles sur la \cref{fig-nxp_dev_boards}. La première est un simple dongle USB avec quelques boutons et une LED qui peut s'avérer utile pour faire des tests, par exemple, si on a besoin de scanner des paquets Bluetooth Low Energy. La FRDM-KW41Z est beaucoup plus complète. Elle propose en premier lieu des connecteurs compatibles avec les cartes d'extension Arduino. Elle contient en outre une meilleure antenne sur le PCB avec la possibilité de faciliter la connexion d'une antenne externe sur le connecteur prévu à cet effet. La carte est également équipée d'une vingtaine de \textit{jumpers} qui offrent la possibilité de tester les différents modes de consommation du circuit, ainsi que plusieurs confirmations des sorties. Elle possède également une mémoire flash externe qui peut être utilisée pour les mises à jour OTAA, ainsi qu'un accéléromètre/gyroscope via l'intégration d'un FXOS8700CQ. Cette deuxième carte a été utilisée dans le cadre de ce projet pour avoir une première approche avec les outils de programmation et ainsi pouvoir commencer à programmer parallèlement à la réalisation du PCB.

\FloatBarrier
\subsection{Gestion de la batterie}

Le système doit pouvoir être autonome. Afin de garantir cela, une batterie peut être connectée. La capacité de cette batterie reste au choix de l'utilisateur. 
L'utilisateur peut recharger celle-ci à l'aide d'un connecteur micro-USB présent sur la carte. L'aspect autonomie peut être encore plus poussé en connectant un panneau solaire directement sur la carte. Celui-ci a son propre connecteur dédié en entrée. Ce panneau permet ainsi de directement charger la batterie qui fournira à son tour la tension pour le système. 

Pour optimiser le rendement lors de l'utilisation d'un panneau solaire, un circuit intégré nommé BQ24210 \footnote{\url{http://www.ti.com/product/BQ24210}} a été utilisé. Ce dernier s'occupe directement de la recharge de la batterie supportant en entrée jusqu'à 20V de tension. Il est capable de fournir jusqu'à 800\,mA à la batterie, tout en protégeant celle-ci en cas de surtension. Il accepte également la possibilité de recharger avec une tension de 5V, permettant ainsi la recharge directement depuis une prise USB. \\

Une batterie est couplée au système. Celle-ci n'a pas de restriction de taille, elle doit simplement être de type Li-Ion en raison de la tension et de la courbe de charge fournie par le BQ24210. La batterie n'a pas besoin d'offrir un circuit de protection contre les surcharges ni les décharges profondes. Comme expliqué précédemment, le circuit BQ24210 interrompt la charge lorsque la batterie est pleine et protège la batterie des décharges profondes.  \\

L'ensemble de la carte est alimentée en 3.3V à l'aide d'un régulateur TPS62291. Celui-ci peut fournir un courant maximum de 1A. Ce haut courant est une précaution selon le type de cartes d'extensions que l'utilisateur souhaite ajouter à la DevBox. Il dispose d'un courant typique de fonctionnement très faible de 15 µA, pouvant ainsi consommer un minimum si l'on souhaite mettre toute la carte en basse consommation.

\FloatBarrier
\subsection{Coprocesseur LoRa}

La communication via LoRa est uniquement possible en utilisant les circuits proposés par l'entreprise Semtech, laquelle propose une gamme de circuits qui est visible à l'adresse suivante : 
\begin{center}
    \url{{http://www.semtech.com/wireless-rf/lora.html}}
\end{center}

Tous les circuits intégrés proposés sur le site de Semtech sont des périphériques qu'il faut ensuite relier avec un microcontrôleur via une communication SPI. Afin de pallier à cela, plusieurs fabricants ont développé des circuits intégrés composés d'un processeur couplé à un module de Semtech. Cela permet ainsi d'économiser du temps de conception. En effet, le plus difficile dans l'intégration de ces modules est la gestion de la partie radiofréquence. Celle-ci nécessite souvent des composants spécifiques qui supportent des fréquences plus élevées que des composants traditionnels. C'est le cas des condensateurs et inductances utilisées, ceux-ci devant être indiqués par le fabricant comme étant utilisables pour des fréquences supérieures à plusieurs gigahertz. Le plus souvent, les fabricants proposent des gammes complètes de ces composants pour ces cas d'utilisations, à l'instar des fabricants Murata\footnote{\url{https://www.murata.com/tool/netlist/mlcc}} ou Vishay\footnote{\url{https://www.vishay.com/capacitors/high-frequency/}}. \\

\begin{figure}[ht!]
    \centering
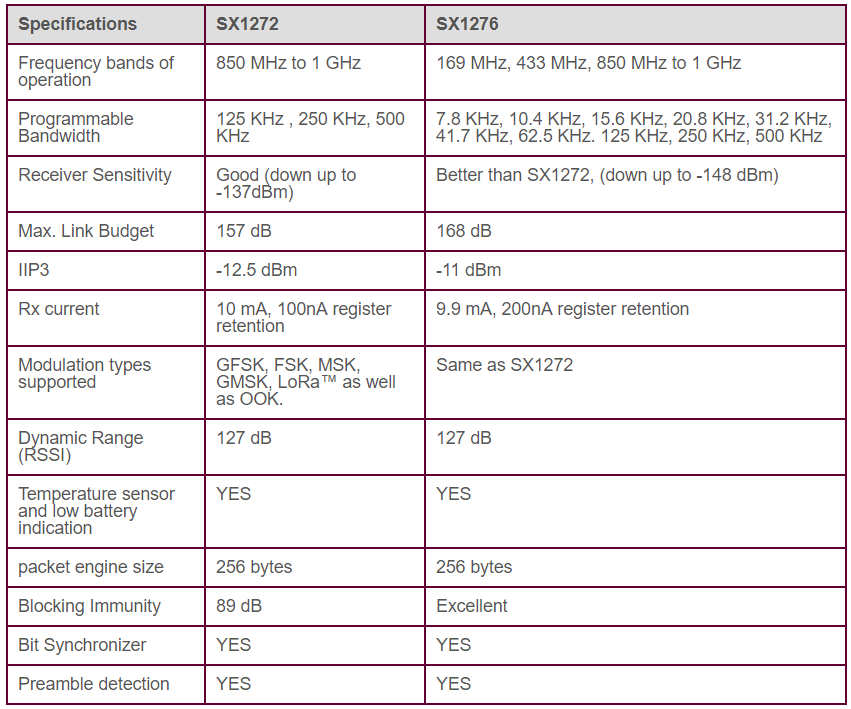
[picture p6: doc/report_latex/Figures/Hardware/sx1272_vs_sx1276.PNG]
    
    \caption{Comparatif SX1272 et SX1276}
    \label{fig-sx1272_vs_sx1276}
\end{figure}

Tous les modules sont équipés d'un processeur connecté via SPI avec un circuit de Semtech. Parmi ces circuits se trouvent le SX1272 et le SX1276. Un comparatif sur le site \texttt{rfwireless-world}\footnote{\url{http://www.rfwireless-world.com/Terminology/SX1272-vs-SX1276-Semtech-LoRa-RF-Transceivers.html}} offre une vue d'ensemble des différences entre ces deux circuits. La \cref{fig-sx1272_vs_sx1276} illustre cette comparaison. Ils sont similaires, mais le SX1276 offre de meilleures performances. En effet, on constate que le SX1276 propose davantage de bandes fréquence ainsi qu'un meilleur \textit{link budget} (correspondant à la puissance de réception\footnote{\url{https://en.wikipedia.org/wiki/Link_budget}}). Le SX1272 ne propose que la fréquence 868 et 915 MHz de la bande de fréquence LoRa, soit celle respectivement pour l'Europe et l'Amérique du Nord respectivement. L'Asie avec ses 433 MHz n'est donc pas supportée. Le SX1276 est actuellement l'une des meilleures options disponibles par Semtech pour connecter un n\oe ud à un réseau LoRaWAN. Néanmoins, pour notre application, le SX1272 est parfaitement suffisant.\\

En termes de consommation, les deux circuits sont similaires. Preuve en est la comparaison des données présentes dans leurs \textit{datasheets} respectives (cf. \cref{fig-sx1272_78_current_consumption}). Dans le cadre d'applications low power, les consommations en veille et au repos sont les plus importantes. Celles-ci sont de 0.1 ou 0.2\,\si{\micro}A pour le mode \textit{sleep} et de 1.5\,\si{\micro}A pour le mode \textit{idle}. Ils constituent des circuits parfaits pour des applications basse consommation. Qui plus est, si on émet à la puissance maximale de 20 dBm, la consommation peut monter à 128 mA dans le cas du SX1272, constat qui doit être pris en compte lors du dimensionnement de l'alimentation du système.

\begin{figure}[ht!]
    \centering
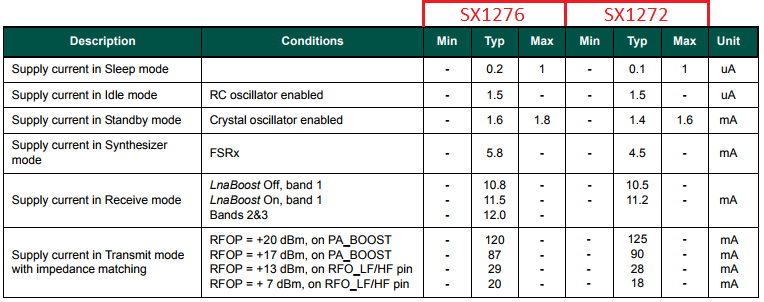
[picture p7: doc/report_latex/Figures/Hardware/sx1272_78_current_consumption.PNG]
    
    \caption{Comparaison de la consommation de courant entre le sx1272 et sx1278}
    \label{fig-sx1272_78_current_consumption}
\end{figure}

\FloatBarrier
\subsubsection{Murata CMWX1ZZABZ-078}
\label{sec-hardware_lora_module}
\begin{figure}[ht!]
    \centering
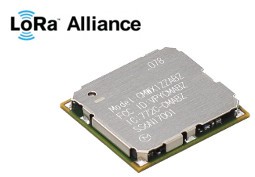
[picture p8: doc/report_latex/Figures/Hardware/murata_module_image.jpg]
    
    \caption{Module LoRa CMWX1ZZABZ-078}
    \label{fig-murata_module_image}
\end{figure}

Le célèbre fabricant de semiconducteurs Murata\footnote{\url{https://www.murata.com/}} a commercialisé, en juillet 2016,  un module LoRa intégrant un SX1276, ainsi qu'un processeur de STMicroelectronics \cite{Muratala5:online}. Le module est visible sur la \cref{fig-murata_module_image}. Murata est renommé pour ses composants passifs de très haute précision, comme ses résistances, condensateurs ou inductances. Comme expliqué dans la section précédente, c'est toujours un challenge d'optimiser des circuits lorsque l'on utilise de hautes fréquences. Murata a développé ce circuit en y ajoutant ses composants afin d'offrir les meilleures performances en radio fréquence tout en minimisant l'espace occupé sur un PCB par le module.\\

\begin{figure}[ht!]
    \centering
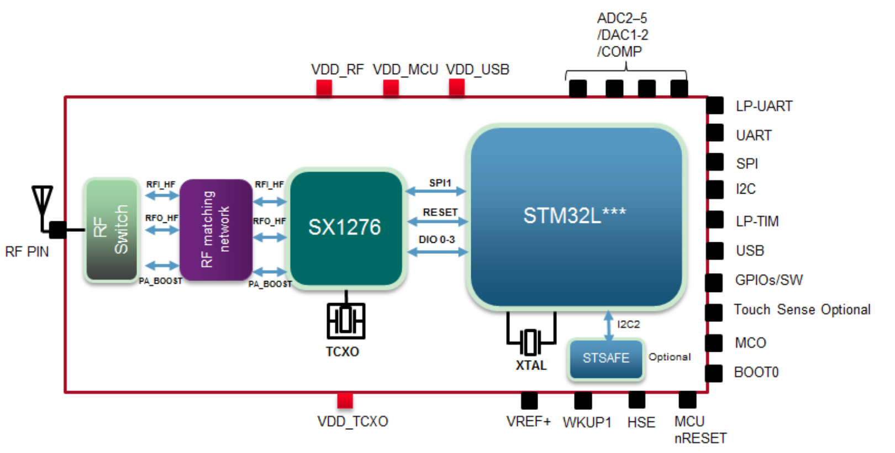
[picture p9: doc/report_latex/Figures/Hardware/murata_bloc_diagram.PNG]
    
    \caption{Contenu du module LoRa CMWX1ZZABZ-078}
    \label{fig-murata_bloc_diagram}
\end{figure}

La \cref{fig-murata_bloc_diagram} illustre le contenu interne du module. On peut y voir un processeur ainsi que le SX1276. Le point fort de ce module est toutefois l'électronique placée entre le SX1276 et l'antenne. En effet, c'est la partie la plus difficile à réaliser lorsque l'on fait du routage haute fréquence, puisqu'il faut adapter les impédances et le dimensionnement des composants. Il existe en réalité deux modèles du CMWX1ZZABZ, la version 078 et la 091. La différence entre les deux est le processeur ST qui est placé en interne. Le 078 contient un STM32L082 alors que le 091 est équipé du STM32L072. C'est de là d'où proviennent les astérisques sur la \cref{fig-murata_bloc_diagram} avec le bloc bleu représentant le processeur. Cependant, à l'heure actuelle, le CMWX1ZZABZ-078 est le seul disponible sur le marché, aucun revendeur ne propose l'autre alternative. La \cref{fig-murata_bloc_diagram} nous indique également la présence d'un composant nommé \cref{sec-mcu_stsafe}. Son nom complet est \textit{State-of-the-art security for peripherals and IoT devices}. Celui-ci est développé par STMicroelectronics et propose plusieurs mécaniques d'authentification, afin de garantir que le périphérique fournissant des données à un client n'a pas été usurpé par une entité tierce. Ce périphérique est exploré plus en détail dans la \cref{sec-mcu_stsafe}.\\

Ses dimensions sont de 12.5\,mm x 11.6\,mm x 1.76\,mm; il est le plus petit des modules présentés ici. Ceci vient surtout du fait que Murata a utilisé sur son circuit des composants passifs avec des boitiers 0201 et 01005, ce qui lui a permis de créer le module le plus compact possible. C'est le seul des modules listé dans ce document qui propose un SX1276, contrairement à ses concurrents qui utilisent un SX1272. \\

La \textit{datasheet} du module ne spécifie pas toutes les consommations en courant. La \cref{fig-murata_current_consumption} contient le peux d'informations qui sont disponibles sur ses consommations. On y retrouve la consommation maximale du composant lors de l'émission à 20dBm. La \textit{datasheet} indique l'ajout de 3 mA en comparaison avec à la consommation seule du SX1276 (cf. \cref{fig-sx1272_78_current_consumption} pour les diverses consommations). Concernant la consommation en \textit{sleep}, on peut observer celle du STM32L082 pour avoir une idée, puisqu'aucune estimation n'est fournie par Murata. La \cref{fig-stm32L0_current_consumption} montre la consommation d'un STM32L082 en mode \textit{low power} avec tous les périphériques éteints. Ce mode serait envisageable avec la DevBox, car le microcontrôleur Bluetooth est capable d'activer ce mode à l'aide, par exemple, d'un GPIO. On observe des consommations très faibles en fonction des horloges choisies. Dans l'ensemble, la consommation du processeur varie de 4.7\,\si{\micro}A à 73\,\si{\micro}A selon la fréquence désirée et de la température d'opération. Il faut ensuite ajouter les consommations du SX1276 dans un mode similaire. Les consommations du SX1276 ont été précédemment présentées dans la \cref{fig-sx1272_78_current_consumption}, laquelle indiquait une consommation en mode \textit{sleep} de 0.2\,\si{\micro}A. Ce sont des courants tout à fait adaptés à des applications basse consommation. \\

\begin{figure}[ht!]
    \centering
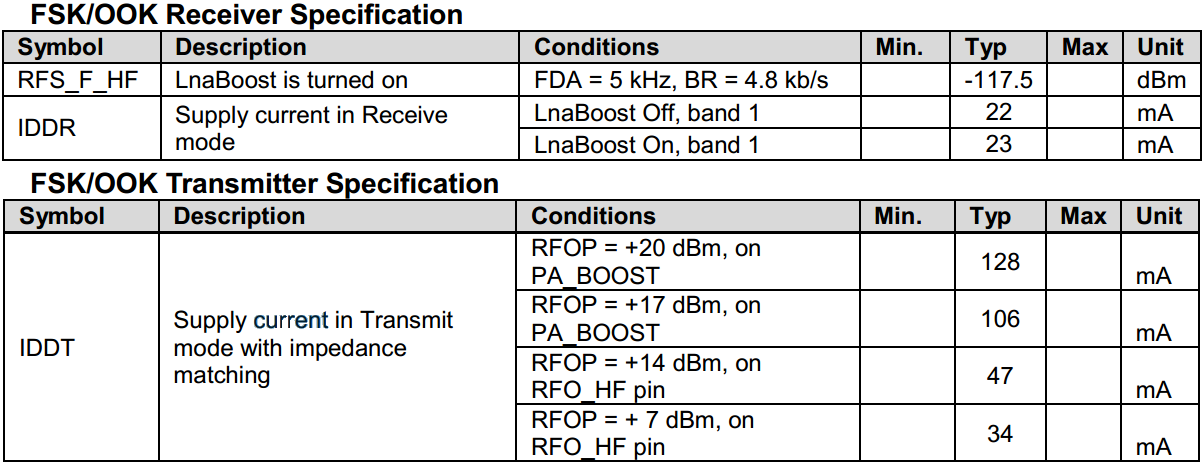
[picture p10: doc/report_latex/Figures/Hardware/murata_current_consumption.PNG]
    
    \caption{Consommation en courant du module CMWX1ZZABZ-078}
    \label{fig-murata_current_consumption}
\end{figure}

\begin{figure}[ht!]
    \centering
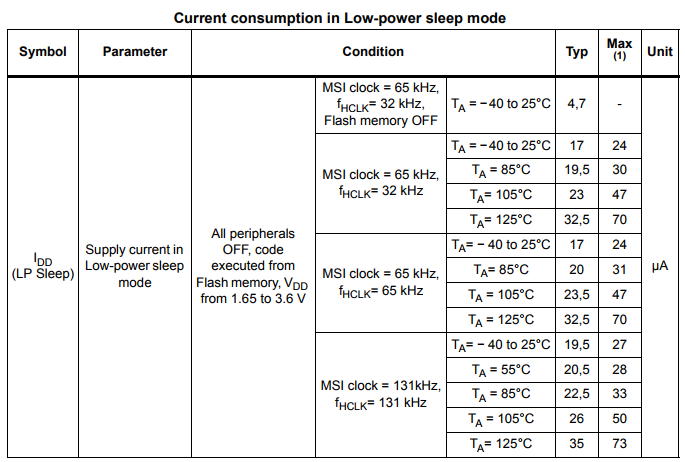
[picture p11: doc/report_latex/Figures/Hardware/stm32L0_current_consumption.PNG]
    
    \caption{Consommation en courant du microcontrôleur STM32L082}
    \label{fig-stm32L0_current_consumption}
\end{figure}

\FloatBarrier
\subsubsection{IMST iM880B}

\begin{figure}[ht!]
    \centering
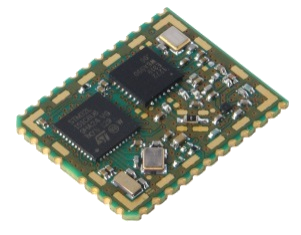
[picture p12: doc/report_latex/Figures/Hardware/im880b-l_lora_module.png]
    
    \caption{Module LoRa iM880B du fabricant IMST}
    \label{fig-im880b-l_lora_module}
\end{figure}

Le module iM880B, visible sur la \cref{fig-im880b-l_lora_module}, est un produit de l'entreprise IMST. Celle-ci est renommée pour ses concentrateurs LoRa nommés iC880A\footnote{\url{https://wireless-solutions.de/products/radiomodules/ic880a.html}} qui, dotés d'un prix très accessible, facilitant la mise en place d'une gateway LoRaWAN. \\

Sa dimension étant de 25 x 20\,mm, il presque quatre fois plus grand que le module de Murata. Il dispose toutefois d'un processeur plus puissant que le Murata. En effet, il s'agit là de la gamme STM32L1, contrairement au STM32L0 du CMWX1ZZABZ. Le STM32L1 est basé sur un Cortex M3 cadencé à 16 MHz. Un processeur puissant n'a pas vraiment de sens dans ce projet, car le processeur LoRa restera le plus clair de son temps en veille en attendant des commandes du processeur principal.\\

\begin{figure}[ht!]
    \centering
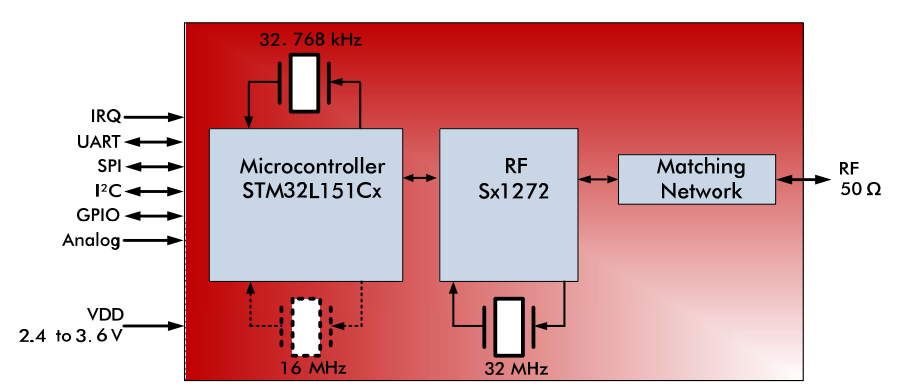
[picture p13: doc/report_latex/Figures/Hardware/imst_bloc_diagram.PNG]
    
    \caption{Contenu du module LoRa iM880B}
    \label{fig-imst_bloc_diagram}
\end{figure}

La \textit{datasheet} de ce module nous fournit plus d'informations sur sa consommation. Les consommations sur les multiples modes sont visibles sur la \cref{fig-imst_current_consumption}. On a la même consommation en émission maximale que le Murata à 128 mA à +20 dBm. Cette \textit{datasheet}, présente cette fois la consommation lorsque le périphérique est en mode \textit{low power}. Celle-ci s'élève à 1.85\,\si{\micro}A avec un RTC activé, ou 800 nA sans celui-ci. La consommation du STM32L082 est donc similaire à celle du Murata. Malgré l'utilisation d'un processeur plus puissant (STM32L1), la consommation est donc inférieure à celle du CMWX1ZZABZ (4.9\,\si{\micro}A). Il faudrait examiner quel mode du microcontrôleur est activé dans cette configuration pour pouvoir faire une comparaison exacte entre les deux configurations. Dans le cas du Murata, il s'agissait du mode \textit{sleep} du processeur, mais cette information n'est pas disponible pour le module IMST.\\

\begin{figure}[ht!]
    \centering
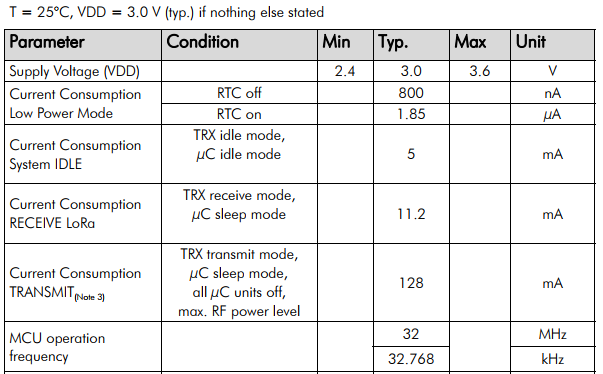
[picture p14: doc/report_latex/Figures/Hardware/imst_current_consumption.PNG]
    
    \caption{Consommation en courant du module iM880B}
    \label{fig-imst_current_consumption}
\end{figure}

\FloatBarrier
\subsubsection{USI WM-SG-SM-42}

Le fabricant chinois USI a annoncé la production, en décembre 2016, d'un module similaire à celui de Murata. Celui-ci est nommé WM-SG-SM-42 et est visible sur la \cref{fig-usi_en.i-nucleo-lrwan1}. Celui-ci a été adopté par STMicroelectronics pour la création d'un \textit{shield} pouvant être placé sur des plateformes Arduino ou, directement, sur certaines de leur cartes de développement. Le contenu du module est illustré sur la \cref{fig-usi_bloc_diagram}.\\

\begin{figure}[ht!]
    \centering
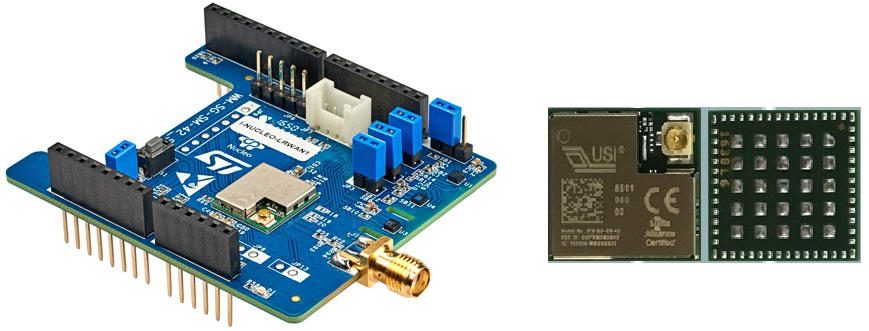
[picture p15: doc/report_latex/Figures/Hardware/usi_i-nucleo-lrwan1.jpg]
    
    \caption{\textit{Shield} I-NUCLEO-LRWAN1 de ST et module USI WM-SG-SM-42}
    \label{fig-usi_en.i-nucleo-lrwan1}
\end{figure}

\begin{figure}[ht!]
    \centering
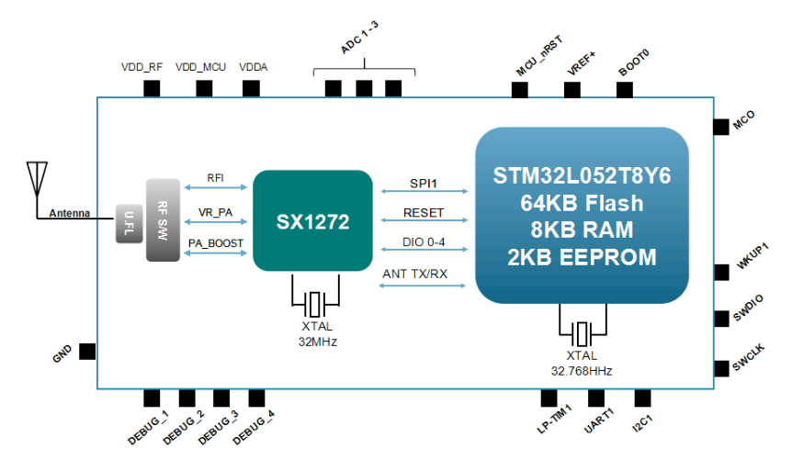
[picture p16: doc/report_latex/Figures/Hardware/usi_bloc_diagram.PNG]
    
    \caption{Contenu du module WM-SG-SM-42}
    \label{fig-usi_bloc_diagram}
\end{figure}

Néanmoins, lorsque ce projet a commencé (septembre 2017), très peu d'informations étaient disponibles sur ce module, la seule référence postée sur le site du fabricant étant le communiqué de presse suivant : 
\begin{center}
    \url{http://www.usish.com/english/pressroom_more.php?n_sn=23}
\end{center}
Il n'y avait pas de description du produit ni de \textit{datasheet}, et le site n'était pas encore entièrement traduit en anglais. Il semble que tout cela se soit amélioré à la date de la rédaction de ce rapport (janvier 2018). Une page du produit est maintenant disponible\footnote{\url{http://www.usish.com/english/products_WM_SG_SM_42.php}}, de même qu’un PDF contenant une \textit{datasheet} du module\footnote{\url{http://www.usish.com/pdf/WM-SG-SM-42_Product\,\%20SPEC.pdf}}. Cependant, un problème majeur est toujours présent: ce module ne semble être disponible chez aucun revendeur; même sur des sites de vente en ligne comme Alibaba ou Aliexpress. Contrairement au module de Murata, qui est très facilement accessible. En revanche, le \textit{shield} produit par STMicroelectronics, équipé du module USI, est bien commercialisé en Europe et disponible chez plusieurs fournisseurs\footnote{\url{https://www.findchips.com/search/I-NUCLEO-LRWAN1}}.\\

Le module a une dimension de 12\,mm x 13\,mm, similaire au module de Murata. Il possède en outre un connecteur U.FL placé sur le module. Ceci est un avantage, puisqu'il permet d'économiser de la place sur le circuit si le but final est d'utiliser une antenne externe au PCB. Dans le cadre de ce projet, les deux options ont été retenues. L'utilisation de ce module aurait présenté un avantage en termes de gain de place. \\

\begin{figure}[ht!]
    \centering
    
    \caption{Consommation en courant du module WM-SG-SM-42}
    \label{fig-usi_current_consumption}
\end{figure}

En ce qui concerne la consommation, la \textit{datasheet} reste très vague sur les informations. On peut voir uniquement les deux valeurs affichées sur la \cref{fig-usi_current_consumption} sur une configuration LoRa à 3.3V, 25°C et BW 125kHz. La consommation en mode \textit{standby} est trop élevée pour qu'elle soit celle de la consommation définitive du circuit. Il est possible de le mettre en mode \textit{low power}, mais la consommation de ce mode n'est pas documentée dans la \textit{datasheet}. Les consommations en émissions sont listées dans la \textit{datasheet} en fonction de la puissance d'émission. Elles varient de 47 mA à 126 mA à 868 MHz, avec des puissances d'émission allant de 5.6 à 19 dBm. Il faut être conscient que ces consommations ne sont présentes que lorsque l'utilisateur émet des paquets sur le réseau, sont durant quelques centaines de millisecondes au maximum. Pour la consommation en veille, on peut estimer que celle-ci est identique au Murata, puisque toute la gamme STM32L0 a des consommations similaires.\\

Comme pour les deux autres modules, la partie RF est intégrée dans le module, ce qui simplifie le développement matériel final. Il suffit de raccorder une antenne avec une impédance correcte de 50\,Ohms.

\subsubsection{Module choisi}

Le module de Murata est celui qui a été retenu pour ce projet. Il a l'avantage d'être extrêmement compact et simple à intégrer. Il est également disponible chez tous les revendeurs en Europe, contrairement à son rival, celui du fabricant USI. Au niveau logiciel, plusieurs codes exemples sont directement fournis par ST sur leur site Internet, ce qui offre un support en cas de problèmes au fil du développement.\\

\begin{figure}[ht!]
    \centering
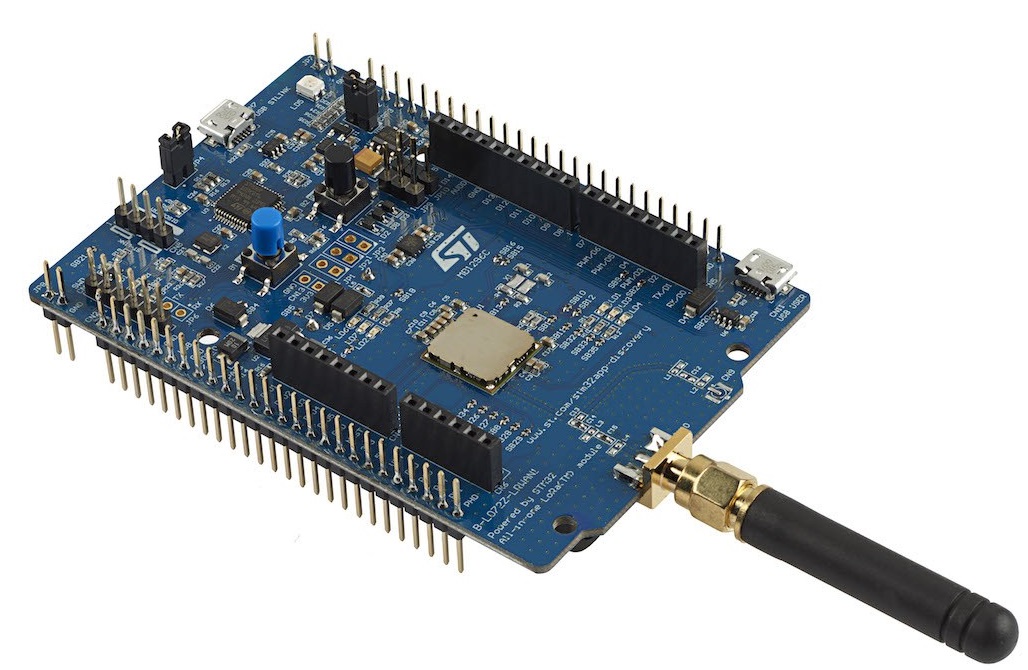
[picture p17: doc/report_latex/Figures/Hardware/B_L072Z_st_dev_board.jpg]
    
    \caption{Carte de développement ST B-L072Z-LRWAN1}
    \label{fig-B_L072Z_st_dev_board}
\end{figure}

La carte de développement B-L072Z-LRWAN1 de ST Microelectronics, visible sur la \cref{fig-B_L072Z_st_dev_board}, offre la possibilité directement commencer à travailler sur le matériel sans que la carte électronique ne soit finalisée. Une partie du code de cette carte peut ensuite être facilement adapté sur la DevBox.

\subsection{Périphériques}

La carte DevBox est équipée de certains périphériques capteurs de données. Cette sous-section a pour but de les énumérer et de présenter leurs principales caractéristiques. Le schéma contenant ces périphériques est disponible dans l'\cref{AppendixDevBoxHardware} de ce document. Ils sont principalement présentés dans les schémas nommés \texttt{Embedded Sensors}, \texttt{GPS} et \texttt{PMOD}.

\subsubsection{LED}

Chaque microcontrôleur a à sa disposition quatre LED. Une bleu, une verte, une rouge ainsi qu'une jaune. Ces LED sont contrôlables via des GPIOs avec un état bas pour les allumer. Elles sont programmables selon la volonté de l'utilisateur.

\subsubsection{Buttons}

Chaque microcontrôleur a à sa disposition 2 boutons poussoirs. Ceux-ci produisent un état bas sur les GPIOs lorsque le bouton est pressé. Ces boutons sont programmables selon la volonté de l'utilisateur.

\subsubsection{Plateforme inertielle 9 axes}

\begin{figure}[ht!]
    \centering
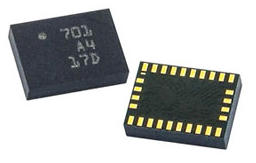
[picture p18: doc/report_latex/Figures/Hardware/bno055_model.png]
    
    \caption{Plateforme 9 axes BNO055}
    \label{fig-bno055_model}
\end{figure}

La DevBox dispose d'une plateforme inertielle 9 axes (14-bit accéléromètre, 16-bit gyroscope et 16-bit magnétomètre) intégrés dans un même circuit électronique. Il s'agit du BNO055 fabriqué par Bosch Sensortec, visible sur la \cref{fig-bno055_model}, dont la communication s'effectue via un bus I2C relié au processeur principal (KW41Z). L'adresse I2C est configurable en fonction de l'état de la pin COM3 du module. Deux résistances (R11 et R13, une seule doit être placée) permettent de choisir le dernier bit de l'adresse. Si la résistance R11 est placée, le périphérique comporte alors l'adresse 0x29. Si c'est la résistance R13, cette adresse est 0x28. \\

À l'intérieur de ce composant, on trouve un ARM Cortex-M0+ avec un \textit{firmware} développé par Bosch, afin de pouvoir délocaliser le calcul de certaines données capturées. Cela permet, par exemple, de demander au composant de retourner la valeur de la gravité en $m/s^2$ ou de calculer de quaternions, réduisant ainsi le nombre d'opérations de lecture et surtout, économisant le temps de calcul du processeur principal sur un circuit embarqué. Le BNO055 a été créé avec la problématique de la consommation en tête. Dans son mode le plus bas, nommé \textit{Suspend Mode}, il ne consomme que 40 uA. \\

Bosch Sensortec propose un pilote pour la plupart de ses composants et celui-ci ne fait pas exception. Cela permet d'accélérer le développement, ce qui est parfait dans le cadre de ce projet, puisque l'utilisation de l'accéléromètre n'est pas l'objectif principal. \\

\subsubsection{Capteur environnemental et qualité de l'air ambiant}
\label{sec-hardware_bme680}

\begin{figure}[ht!]
    \centering
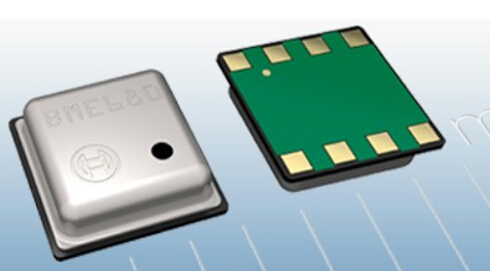
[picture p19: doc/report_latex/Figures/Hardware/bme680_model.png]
    
    \caption{Capteur environnemental et qualité de l'air BME680}
    \label{fig-bme680_model}
\end{figure}

Un capteur de qualité de l'air a également été intégré sur la DevBox. Il s'agit du BME680 de Bosch Sensortec visible sur la \cref{fig-bme680_model}. Celui-ci ne mesure pas seulement la qualité de l'air, il mesure également la pression ambiante, la température, l'humidité et le gaz. Pour la mesure du gaz, il s'agit des \textit{Volatile Organic Compounds}\footnote{\url{https://en.wikipedia.org/wiki/Volatile_organic_compound}} (VOC), avec lesquels ont évalue la qualité globale de l'air ambiant. La liste des VOC utilisés pour l'index de la qualité de l'air ainsi que leur taux de précision est disponible sur la \cref{fig-bme680_voc_compounds}. Le capteur contient en interne une zone chauffante, laquelle s'active un bref instant pour pouvoir ensuite extraire la résistance de l'air. Cette résistance est la seule valeur fournie par ce capteur. Il faut ensuite faire des corrélations afin d'extraire les informations. La température, l'humidité et la pression sont elles directement retournées dans leurs unités respectives (°C, \,\% et Pa). 

\begin{figure}[ht!]
    \centering
    
    \caption{VOC mesurés par le BME680}
    \label{fig-bme680_voc_compounds}
\end{figure}

Comme pour le BNO055, Bosch Sensortec met a disposition un driver en C\footnote{\url{https://github.com/BoschSensortec/BME680_driver}}. Le driver est beaucoup plus sommaire que celui du BNO055, car Bosch propose également une bibliothèque nommée BSEC pour \textit{Bosch Sensortec Environmental Cluster}\footnote{\url{https://www.bosch-sensortec.com/bst/products/all_products/bsec}}. Cette dernière n'est pas open source, il faut se contenter d'un binaire précompilé pour l'architecture utilisée. 

\subsubsection{GPS}
\label{sec-hardware_gps}

La DevBox peut également être équipée d'un GPS au besoin. Celui-ci étant assez couteux, il ne sera pas forcément monté sur toutes les cartes. Le GPS peut être utilisé si l'on souhaite traquer un objet en déplacement avec une très grande précision ($\pm$ 8m, 95\,\% du temps \cite{GPSgovGP89:online}). Il peut également être utilisé pour corréler la localisation obtenue via LoRa avec une position réelle. Cette géolocalisation par LoRa est expliquée dans l'introduction au LoRa de sous la \cref{sec_stateOfTheArtLoRa}.

\begin{figure}[ht!]
    \centering
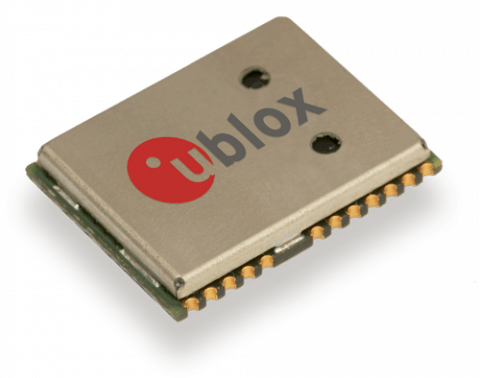
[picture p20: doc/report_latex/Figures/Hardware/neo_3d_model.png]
    
    \caption{GPS U-blox NEO-M8}
    \label{fig-neo_3d_model}
\end{figure}

Le choix du GPS, a été opéré parmi ceux du fabricant suisse U-blox, spécialisé dans les semiconducteurs avec communication sans fil. Ils ont un large choix en termes de périphériques GPS. Ils proposent des GPS assortis d'antennes externes ou d'antennes céramiques placées directement sur un module. Ces GPS ont également la possibilité d'incorporer un \textit{low-noise amplifier} (LNA\footnote{\url{https://en.wikipedia.org/wiki/Low-noise_amplifier}}) pour l'amplification du signal. On peut également y trouver un filtre de type \textit{surface acoustic wave} (SAW\footnote{\url{https://www.vectron.com/products/saw/gps.htm}}) pour améliorer le signal et ainsi améliorer la réception. Lorsque ces deux éléments sont directement intégrés dans le module, cela facilite considérablement la complexité de routage d'un circuit équipé d'un GPS. En effet, s'il est nécessaire de créer ces deux éléments à l'extérieur du GPS, il faut faire particulièrement attention au type de composants utilisés, car le GPS communique à l'aide de deux hautes fréquences de 1575.42\,MHz et 1227.60\,MHz \cite{GPSsigna51:online}. Il y a également l'adaptation d'impédance sur la connexion avec l'antenne qui doit être correctement calculée en considérant l'épaisseur du circuit imprimé. \\

Le GPS recherché devait également être capable d'accepter la lecture par une interface de type I2C ou SPI, puisque ce sont les seules interfaces encore disponibles sur le KW41Z, puisque l'UART a été utilisé pour la communication entre le KW41Z et le module LoRa. Malheureusement, l'UART est l'interface la plus utilisée en GPS, donc certains GPS ne proposent que ce type de protocole de communication.

\begin{figure}[ht!]
    \centering
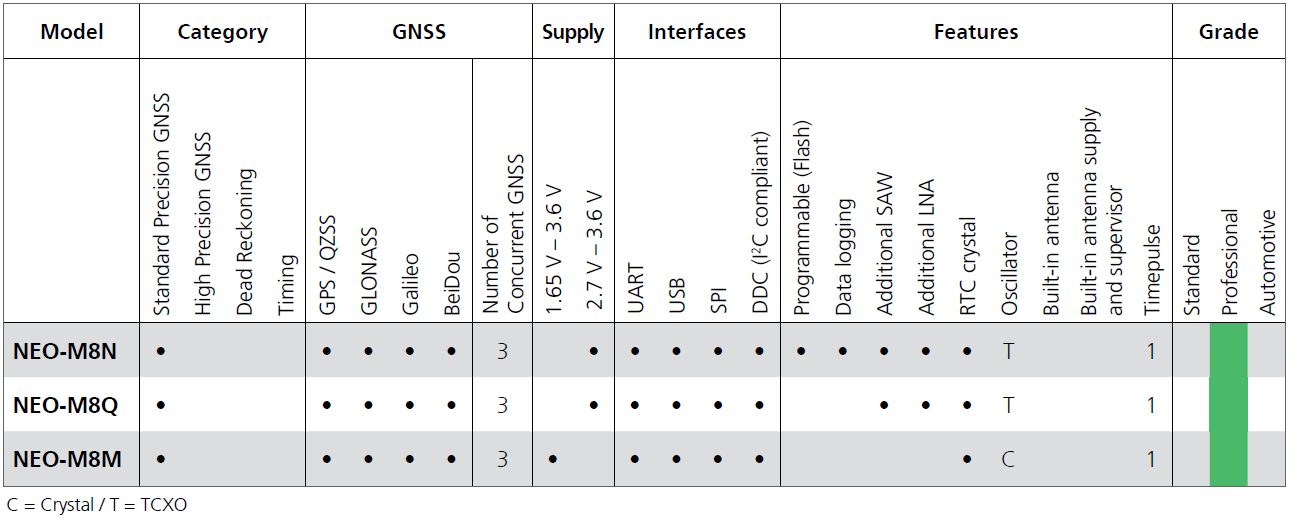
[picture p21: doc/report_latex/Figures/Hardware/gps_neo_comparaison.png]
    
    \caption{Comparaison de la gamme de GPS U-blox NEO-M8}
    \label{fig-gps_neo_comparaison}
\end{figure}

Le GPS retenu a été le NEO-M8 dont la gamme complète est visible sur la \cref{fig-gps_neo_comparaison}. Celui-ci offre tout ce dont on a besoin, à savoir la possibilité d'une connexion avec une interface I2C ou SPI, ainsi que l'intégration d'un filtre SAW et d'un LNA. L'interface retenue pour le GPS a été le SPI, laquelle doit être partagée avec les composants qui sont connectés sur le connecteur PMOD (cf. \cref{sec-pmod_connector}). Sa taille est importante par rapport à celle des deux processeurs utilisés sur la carte (12.2 x 16 x 2.4\,mm pour le NEO-M8 contre 12 x 13\,mm pour le module LoRa). Il est entouré d'un boitier métallique, visible sur la \cref{fig-neo_3d_model}, afin d'atténuer les perturbations externes. Cependant, il ne nécessite aucun périphérique externe, à l'exception d'un connecteur U.FL pour la connexion d'une antenne externe.

\begin{figure}[ht!]
    \centering
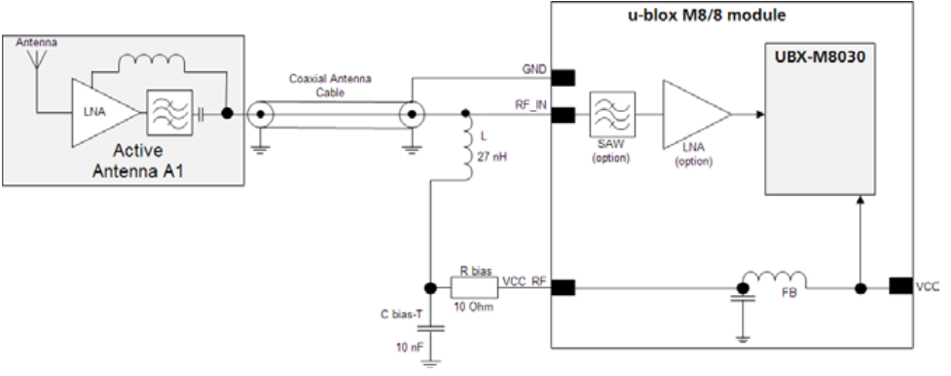
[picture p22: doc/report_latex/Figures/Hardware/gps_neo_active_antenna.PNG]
    
    \caption{Schéma de connexion d'un NEO-M8 avec une antenne active}
    \label{fig-gps_neo_active_antenna}
\end{figure}

Le GPS a été routé sur la DevBox pour pouvoir utiliser des antennes non actives. Si l'utilisateur souhaite utiliser des antennes actives, il est possible de connecter l'alimentation directement le signal RF en entrée de l'antenne. Ceci n'est pas la connexion recommandée, mais elle est fonctionnelle. Selon la \textit{datasheet} du constructeur, si l'on souhaite convertir le signal RF actif, il faut normalement filtrer le signal d'alimentation afin d'éviter l'injection de bruit dans la radio. La \cref{fig-gps_neo_active_antenna} illustre la connexion recommandée par U-blox. Le NEO-M8 propose également une sortie nommée \textit{Timepulse} qui génère une pulse à chaque seconde (l'intervalle est configurable). Cette pulsation peut être utilisée pour synchroniser une horloge sur le microcontrôleur, de même que pour savoir si le GPS est prêt à fournir un nouveau paquet.\\

Ce module GPS entre directement dans la gamme professionnelle. La gamme supérieure est l'\textit{automotive} pour l'industrie des véhicules, mais il n'a pas été jugé nécessaire de prendre des composants de ce type pour le projet réalisé.
Le prix du GPS s'élève à 9.24 euros à partir de 250 pièces achetées (prix visible en janvier 2018).

\begin{figure}[ht!]
    \centering
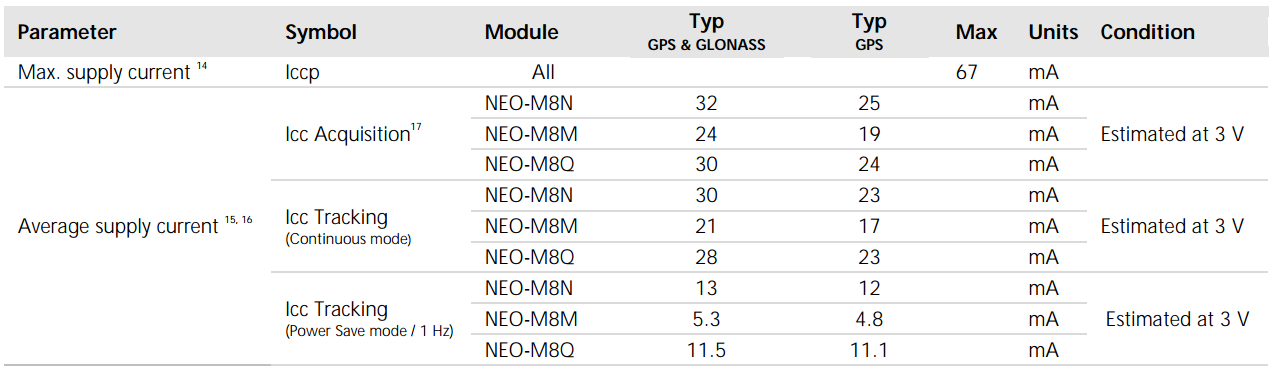
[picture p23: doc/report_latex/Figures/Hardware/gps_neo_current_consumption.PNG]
    
    \caption{Consommation du GPS NEO-M8}
    \label{fig-gps_neo_current_consumption}
\end{figure}

En termes de consommation, tous les GPS sont de gourmands en énergie, car ils doivent continuer à écouter les signaux GPS. La \cref{fig-gps_neo_current_consumption} illustre combien le circuit consomme en acquisition. Cela dépend du mode choisi, le mode normal étant nommé \textit{ICC Acquisition}. Pour le NEO-M8Q, la consommation est en moyenne de 30mA avec GLONASS et GPS utilisés. À cette consommation, il faut encore ajouter celle d'une antenne active, dans la mesure où ce type d'antenne est raccordée. Les antennes actives consomment entre 3mA et 25mA selon les modèles utilisés. La consommation finale oscille ainsi autour de 50 mA, ce qui est problématique pour beaucoup de systèmes embarqués autonomes. Heureusement, le NEO-M8 peut être placé en mode \textit{low-power} via l'utilisation de commandes UBX; il est toutefois impossible de trouver la valeur exacte de la consommation de ce mode parmi les documents de U-blox. La seule référence à la consommation indique ce qui suit : 

\begin{quote}
\begin{center}
    \textit{During operation, the current drawn by the module can vary by some orders of magnitude, especially if enabling low-power operation modes.}
\end{center}
\end{quote}

Aucune valeur n'est fournie pour la consommation dans ce mode. Il est également possible de placer le GPS en mode \textit{backup}. C'est un mode où le GPS est désactivé, mais l'éphéméride des satellites est sauvegardée dans une mémoire volatile pour accélérer la synchronisation lorsque le mode normal est resélectionné. Pour sauver l'état de cette mémoire, une tension doit être appliquée au circuit sur une pin spécifique. Cette sauvegarde consomme 15\si{\micro{}}A si la tension de l'alimentation est de 1.8V. Ce type de mémoires peuvent être alimentées par des piles boutons, puisque le seuil minimum de tension est de 1.4V. Dans le cadre de ce projet, cette pin a été directement connectée à la tension VCC du circuit, celui-ci étant régulé par une batterie.

\subsubsection{Connecteur PMOD}
\label{sec-pmod_connector}

La carte DevBox est également compatible avec les connecteurs PMOD. Ces connecteurs sont basés sur un standard d'interface\footnote{\url{https://en.wikipedia.org/wiki/Pmod_Interface}} du même nom développé par l'entreprise Digilent\footnote{\url{http://store.digilentinc.com/}}. Le pinout des différents types d'interfaces est disponible sur la \cref{fig-pmod_type_pinout}. Dans le cas de la DevBox, les standards n'ont malheureusement pas pu être intégralement respectés, en raison de l'absence de GPIO disponibles sur le module Bluetooth. Les connecteurs sont compatibles avec les PMOD de type I2C, à l'exception des deux IO et des signaux. L'interface SPI est supportée à l'exception de INT et RST. Le pinout final de la DevBox est visible sur le schéma \texttt{PMOD} de l'\cref{AppendixDevBoxHardware}.\\

\begin{figure}[ht!]
    \centering
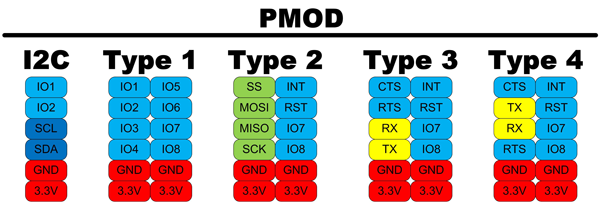
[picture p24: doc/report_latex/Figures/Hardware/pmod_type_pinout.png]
    
    \caption{Pinout du standard PMOD en fonction des types choisis}
    \label{fig-pmod_type_pinout}
\end{figure}

Digilent commercialise des modules compatibles avec ces interfaces, ce qui facilite l'ajout d'un type de capteur qui n'aurait pas , par défaut, été rajouté sur la carte de développement. Le problème lié aux processeurs utilisés est le nombre de connexions disponibles vers l'extérieur. Nos deux microcontrôleurs ne sont équipés que de 48 pins au total, dont la moitié sont utilisés pour les alimentations et divers contrôles internes.

\FloatBarrier

\section{Schéma bloc général final}

La \cref{fig-hardware_bloc_diagram} illustre le schéma bloc final sur Altium de la carte DevBox. Il représente toutes les interfaces de communications entre les différents blocs. Cette image est également disponible sur l'\cref{AppendixDevBoxHardware}, tout comme les autres schémas électroniques du projet.\\

\begin{figure}[ht!]
    \centering
    
    \caption{Schéma bloc général de la DevBox}
    \label{fig-hardware_bloc_diagram}
\end{figure}

\FloatBarrier
\section{Réalisation et production du circuit électronique}

Le PCB réalisé a été routé selon les contraintes du fabricant de PCB\footnote{\url{https://www.pcbway.com/}} choisi, soit PcbWay. L'épaisseur choisie est de 1.6mm et les largeurs de piste minimales de 4mil. Les plus petits trous autorisés sont de 0.2mm. Afin de facilité la soudure, une finition à l'or a été demandée. Le temps de production est d'environ une semaine et demie à partir du moment où la transaction est validée. \\

Les composants électroniques ont principalement été commandés auprès de trois fournisseurs: Mouser, Farnell et Digikey. Mouser a été privilégié pour les composants, les deux autres n'ayant été utilisés qu'en cas de rupture de stock chez Mouser. La liste complète des composants avec leurs numéros de commande sont indiqués dans le projet Altium présent sur GitHub.\\

Un masque de dépose de pâte a dû être commandé à l'entreprise DB Products\footnote{\url{https://www.dbproducts.fr/}}. Une fois celui-ci reçu la production a pu être effectuée avec une machine de dépose de composants manuelle.

\section{Erreurs de conception et corrections possibles}
\label{sec_hardware_errors}

Une fois le PCB réalisé, plusieurs tests ont été effectués pour vérifier son fonctionnement. Quelques erreurs critiques ont du être corrigées : 

\begin{itemize}
    \item \textbf{Module LoRa} : VDD\_USB doit être connecté au 3.3V et non au 5V;
    \item \textbf{Module LoRa/Bluetooth} : RX et TX sont inversés sur la ligne UART;
    \item \textbf{Module LoRa} : VDD\_TCXO doit être connecté à la pin PA12 afin de pouvoir placer le SX1276 en mode \textit{sleep}.\\
\end{itemize}

Quelques améliorations peuvent également être envisagées pour la prochaine version, celles-ci n'étant toutefois pas un obstacle au fonctionnement de la version actuelle de la DevBox : 

\begin{itemize}
    \item \textbf{Module LoRa} : Connecter la mesure de la batterie (diviseur de tension) sur une pin ADC du module LoRa. Pour ce faire, il faut également relier la pin VREF à une référence externe ou au VCC. A l'heure actuelle, uniquement le KW41Z a accès à cette mesure.
    \item \textbf{GPS} : Ajouter le support d'une antenne active sur le PCB avec l'ajout de la tension d'alimentation filtrée sur le signal RF. Il est également possible d'ajouter un autre LNA à la sortie du signal RF (cf. \texttt{Hardware Integration} PDF aux pages 15 et 16). 
    \item \textbf{GPS} : Si l'on souhaite mettre en veille le GPS, il est possible de configurer une pin afin que celle-ci le place en mode \textit{sleep} lorsqu'elle est placée à un état 0. Il s'agit là de la pin EXTINT, mais celle-ci doit préalablement être programmée au moyen du protocole UBX.
    \item \textbf{GPS} : Connecter la pin GPS\_nCS sur une pin contrôlable par le DSPI en tant que \textit{chip select}. Actuellement, cette pin est contrôlée par un GPIO.
    \item \textbf{PCB layout} : Déplacer le bouton reset du KW41Z afin d'éviter les \textit{resets} non souhaités lors de la connexion sur câble JTAG. 
    \item \textbf{PCB layout} : Placer les boutons du KW41Z en face des LED du même microcontrôleur.
    \item \textbf{PCB layout} : Les LED de la charge de la batterie peuvent être placées sur le haut de la carte.
    \item \textbf{BME680} : Le BME680 pourrait être placé dans un coin plus proche du bord de la carte. On peut également découper un sillage autour du capteur afin de limiter la chauffe du PCB.
\end{itemize}

\section{Boitier en plastique}

\begin{figure}[ht!]
    \centering
    
    \caption{Boitier imprimé en 3D pour y loger le circuit électronique}
    \label{fig-3d_case_devbox}
\end{figure}

Un petit boitier en plastique, visible sur la \cref{fig-3d_case_devbox}, a été créé afin d'y loger la carte. Ce boitier a été réalisé à l'aide du logiciel freecad\footnote{\url{https://www.freecadweb.org/}} et est cité dans les sources du projet sur GitHub. Son impression a été réalisée à l'aide d'une imprimante 3D.

\FloatBarrier

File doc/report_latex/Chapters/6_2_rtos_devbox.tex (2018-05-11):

\FloatBarrier
\newpage
\section{DevBox : module LoRaWAN}
\label{sec-soft_devbox}

Le module LoRaWAN est interconnecté avec le microcontrôleur Bluetooth via une interface UART. Le débit final de cette interface a été fixé à 115200 bits 
par seconde.

\subsection{Architecture logicielle}

STMicroelectronics propose une suite de bibliothèques pour ses divers microcontrôleurs afin de pouvoir communiquer avec des modules LoRa. Cette suite de bibliothèques est basée sur la très connue suite de développement STM32Cube\footnote{\url{http://www.st.com/en/embedded-software/stm32cube-mcu-packages.html}} et nommé \texttt{STM32 LoRa software expansion} \cite{STM32LoR36:online}. La \cref{fig-murata_lorawan_architecture} illustre l'architecture logicielle de cette suite de bibliothèques. Elle est composée d'un Hardware Abstraction Layer avec tous \textit{drivers} des périphériques du microcontrôleur STM32. Pour le \textit{middleware}, les blocs en vert sont repris de Semtech avec leur projet LoRaMac-node\footnote{\url{https://github.com/Lora-net/LoRaMac-node}}, alors que les blocs en bleu sont les \textit{drivers} fournis par ST. Il s'agit là de \textit{drivers} qui sont uniquement utilisés sur les différents capteurs présents sur les cartes de développement, telles que la B-L072Z-LRWAN1 et donc non utilisée dans ce projet. Il a un bloc nommé \textit{utilities}, créé par Semtech, mais modifié par ST. Cette modification permet d'utiliser au mieux les ressources matérielles du STM32L0, telles que les \textit{timers}, le mode \textit{Low-Power}, ainsi que le \textit{True Random Number Generator} (TRNG). L'architecture complète de cette suite de bibliothèques, ainsi que la description des diverses fonctions sont décrites dans le manuel d'utilisateur numéro \textbf{UM2073} de ST \cite{STM32LoR36:online}. 

\begin{figure}[ht!]
    \centering
    
    \caption{Architecture logicielle du CMWX1ZZABZ}
    \label{fig-murata_lorawan_architecture}
\end{figure}

\subsection{Exemples et modifications}
STMicroelectronics propose trois exemples de codes pour le CMWX1ZZABZ adaptés pour la carte de développement B-L072Z-LRWAN. Voici la description de ces projets : 
\begin{enumerate}
    \item \texttt{End Node} : projet ayant pour but de créer un n\oe ud LoRaWAN autonome avec la possibilité d'envoyer des données à des intervalles réguliers ou lors de la pression d'un bouton. 
    
    \item \texttt{AT Master} : offre la possibilité de communiquer avec un nouveau coprocesseur LoRa, implémentant un AT Slave interface. Cet exemple est très complet et est très utile pour comprendre comment la communication avec un AT Slave fonctionne. La \cref{fig-at_slave_master_connection} illustre la connexion entre un microcontrôleur utilisant l'interface \textit{Master} et un \textit{Slave}. Néanmoins, ce projet repose sur beaucoup de bibliothèques de ST, il est donc difficile de l'utiliser directement sur un microcontrôleur d'un autre fabricant.
    
    \item \texttt{AT Slave} : est utilisé pour offrir une interface de programmation du module à un utilisateur. Cet utilisateur peut utiliser un simple terminal série afin d'envoyer des commandes AT ou directement connecter un microcontrôleur (cf. \cref{fig-at_slave_master_connection}). La liste de toutes les commandes AT est disponible dans la note d'application nommée AN4967\footnote{\url{www.st.com/resource/en/application_note/dm00346311.pdf}}, avec les paramètres, ainsi que les réponses.
\end{enumerate}

\begin{figure}[ht!]
    \centering
    
    \caption{Connexion entre un AT \textit{Slave} et un AT \textit{Master} utilisant la suite de bibliothèque STM32Cube LoRa}
    \label{fig-at_slave_master_connection}
\end{figure}

Une interface entre le KW41Z et le CMWX1ZZABZ doit être implémentée, il a donc été décidé de reprendre le projet AT Slave pour le CMWX1ZZABZ et de l'adapter au besoin de la carte. Cet exemple implémente déjà toutes les opérations nécessaires pour rejoindre un réseau LoRa et envoyer des données. Le seul inconvénient de cette interface est l'utilisation d'un protocole basé sur des strings qui demande plus de stockage en mémoire et de temps pour transformer les requêtes. Mais le KW41Z a 128 kB de RAM, qui sont amplement suffisants pour cela. Toutefois, le code a dû être modifié avant d'enlever quelques périphériques qui ne sont pas présents sur la DevBox. Il faut également changer l'interface de communication afin d'utiliser l'UART0 de la carte qui n'est pas sur les mêmes pins que le LPUART initialement connecté.

\section{DevBox : NXP Kinetis KW41Z}

Le développement logiciel du microcontrôleur NXP Kinetis KW41Z est l'élément central de ce projet. Il implique l'interfaçage de divers périphériques avec plusieurs interfaces distinctes et tout cela sur un système temps réel.  

% ---------------------------------------------------------------------------------------------%
\subsection{\textit{OS Abstraction Layer} et \textit{Connectivity Framework}}
% ---------------------------------------------------------------------------------------------%

Les exemples de codes fournis par NXP pour ses microcontrôleurs implémentent tous FreeRTOS. Comme présenté en \cref{sec-RTOS_freertos}, il s'agit actuellement du RTOS le plus populaire et le plus actif en termes de communauté, ce qui apporte beaucoup d'avantages lors du développement. Lors de la présentation des différents RTOS, il a été fait référence aux couches d'abstraction de RTOS, en prenant l'exemple de l’OS Abstraction Layer (cf. \cref{sec-rtos_abstract_layer}). Celui-ci est visible sur la \cref{fig-freescale_osa_framework}. Il offre ainsi la possibilité de changer facilement de RTOS en fonction des besoins du projet pour les utilisateurs. NXP propose un framework nommé \textit{Connectivity Framework} qui s'occupe principalement des connexions avec le monde extérieur (Bluetooth, Wifi, etc.), mais également qui incluent différents autres blocs qui sont tous affichés sur la \cref{fig-freescale_osa_framework}. 

\begin{figure}[ht!]
    \centering
    
    \caption{\textit{Connectivity Framework} de Freescale (NXP)}
    \label{fig-freescale_osa_framework}
\end{figure}

Tout d'abord, en commençant par les différents blocs en bas de la \cref{fig-freescale_osa_framework} , la présence de plusieurs \textit{drivers} pour les périphériques peut être constatée. Ceux-ci couvrent toutes les interfaces de communications présentes sur les microcontrôleurs et sont tous très complets. On a ensuite la présence d'un RTOS qui est composé des différents composants standards d'un RTOS tel que des \textit{queues}, sémaphores et mutexes. Cette couche de RTOS repose directement sur l'interface matérielle, car il est parfois nécessaire d'adapter les drivers pour qu'ils soient \textit{thread safe} en fonction des différents ordonnancements utilisés par les RTOS et ainsi garantir l'intégrité des données. Vient ensuite l'interface OS Abstraction Layer pour uniformiser les différents RTOS. Un certain nombre de services sont disponibles, comme par exemple, le \textit{Serial Manager} qui a été utilisé dans ce projet pour gérer les connexions UART avec le coprocesseur LoRa. Celui-ci peut gérer des flux asynchrones provenant de plusieurs types d'interfaces (UART, USB, I2C et SPI). Pour les interfaces I2C ou SPI, celles-ci doivent être configurées avec une interruption sur un GPIO pour informer le \textit{Serial Manager }qu'une nouvelle donnée est disponible. La plupart de ces frameworks sont des tâches RTOS propre et utilisent des interfaces de communications \textit{thread-safe} afin d'être programmés.  \\

Ensuite, on peut voir l'élément qui simplifie l'intégration des communications externes (Bluetooth, WiFi, etc.) qui se nomme \textit{Components API}. Ce bloc a pour but de faciliter la programmation des diverses \textit{stacks} présentes sur les microcontrôleurs en fonctions des différentes gammes. On retrouve ainsi le Bluetooth, mais également des stacks pour le TCP/IP ou Thread. C'est souvent ce dernier bloc qui n'est pas open source. \\

\textit{Freescale Serial Communication Interface} (FSCI) est à la fois un module, mais également un protocole de communication utilisé entre les interfaces de communications externes (\textit{Components API}) et les services. On peut voir sur la \cref{fig-freescale_osa_framework} qu'il n'est pas forcément nécessaire de passer par le FSCI pour accéder aux composants depuis les composants applicatifs. Le FSCI ainsi que les \textit{frameworks} Services sont documentés dans un manuel de référence de NXP nommé \texttt{CONNFWKRM}. Toutefois, la documentation est légère, il est souvent plus facile de regarder le code source ou simplement les fichiers d'entêtes de fonctions pour les parties non open sources.

Le bloc, le plus haut niveau du framework, nommé \textit{upper layers}, est là où l'utilisateur doit normalement implémenter la plus grande partie de son code. Il a ensuite accès à ses trois interfaces pour utiliser toutes les ressources à sa disposition sur le microcontrôleur.

% ---------------------------------------------------------------------------------------------%
\FloatBarrier
\subsection{Interfaces de programmation}
% ---------------------------------------------------------------------------------------------%

\begin{figure}[ht!]
    \centering
    
    \caption{Bibliothèques et \textit{drivers} utilisés sur la DevBox}
    \label{fig-board_paths}
\end{figure}

Lors du développement de ce projet, plusieurs éléments ont été utilisés afin de simplifier la programmation de la DevBox. Un répertoire nommé \path{smartcanton_devbox_board} présent dans le dépôt GitHub au chemin d'accès, \path{dev/MKW41Z} contient des interfaces qui ont pour but d'être utilisées sur tous les projets qui utiliseront la DevBox à l'avenir. Ce répertoire est ensuite ajouté à l'aide d'un lien symbolique dans le projet MCUXpresso, comme illustré à l'aide de la \cref{fig-board_paths}. Certains de ces éléments sont des bibliothèques ou \textit{drivers} qui ont été développés par la communauté ou directement par les fabricants des composants électroniques utilisés.

\subsubsection{Bibliothèques et \textit{drivers} repris}

En plus du SDK fourni par NXP avec les différents \textit{drivers} pour le KW41Z, un certain nombre de bibliothèques ont été reprises et utilisées afin d'accélérer le développement du projet.

\subsubsubsection{AT Commander}
\label{sec-software_libs_atcommander}
La communication avec le module LoRaWAN s'effectue avec des commandes AT. Pour cela, une bibliothèque nommée AT Commander a été utilisée : 
\begin{center}
    \url{https://github.com/openxc/AT-commander}
\end{center}

Elle a toutefois du être modifiée à cause du format des requêtes qui sont transmissent par le module LoRaWAN. Cette bibliothèque est par défaut utilisable avec des modules AT de type RN42 ou XBEE, dont le format de trames diffère de celles du projet STM32 LoRa. Pour utiliser cette bibliothèque, l'utilisateur doit simplement spécifier deux fonctions pour lire et écrire sur un port UART souhaité. 

\subsubsubsection{minmea}
\label{sec-software_libs_minmea}

Le \textit{parsing} des trames GPS est fastidieux et peut être complexe en fonction des différents GPS et du type de données contenues dans une trame GPS. Il existe beaucoup de bibliothèques pour les GPS, mais souvent celles-ci ne sont pas adaptées aux systèmes embarqués. Cela s'explique par les fonctions de traitement de \textit{strings} qui demandent trop de ressources au processeur. Heureusement, il existe une bibliothèque nommée \texttt{minmea} qui implémente un parseur pour la spécification NMEA 0183 \cite{NMEA018318:online}. Celle-ci est pensée pour les environnements avec des capacités restreintes, comme les microcontrôleurs. Elle est disponible à l'adresse suivante :

\begin{center}
    \url{https://github.com/kosma/minmea}
\end{center}

\texttt{Minmea} est composée de deux fichiers et très simple d'utilisation. La trame récupérée depuis le GPS lui est directement fournie et celle-ci s'occupe d'extraire toutes les informations souhaitées. Elle supporte les données de type RMC, GGA, GSA, GLL, GST, GSV, VTG et ZDA \cite{NMEAdata3:online}. Toutes les données sont ensuite accessibles via des structures selon le type de données.

\subsubsubsection{BNO055 \textit{driver}}
\label{sec-softwaire_driver_bno}

Bosch Sensortec fournit différents drivers pour la plupart de ses composants. Un \textit{driver} est disponible pour le BNO055, avec lesquels, il est possible de communiquer en I2C ou SPI. Selon le mode choisi, des fonctions pour la lecture et écriture doivent être fournies à la bibliothèque. L'utilisateur peut ensuite accéder aux différents registres du capteur.
Le code source de la bibliothèque contient plus de 17000 lignes de codes, car le BNO055 est un capteur à la fois complet, mais également complexe à programmer. Ce \textit{driver} est disponible à l'adresse suivante : 
\begin{center}
    \url{https://github.com/BoschSensortec/BNO055_driver}
\end{center}

\subsubsubsection{BME680 \textit{driver}}
\label{sec-softwaire_driver_bme680}

Le BME680 dispose également d'un driver pour récupérer les différentes informations du capteur comme pour le BNO055. Cependant, une grande partie de la correction des mesures s'effectue en logiciel, ce qui a pour conséquence de créer un \textit{driver} minimal. Il est capable de fournir uniquement la valeur brute de la température, de l'humidité et de la pression. Pour la mesure de la qualité de l'air, celle-ci est uniquement possible à l'aide d'un traitement logiciel. La seule information sur le gaz est la valeur ohmique, mais cela n'indique en rien la qualité de l'air. La bibliothèque est disponible sur le dépôt GitHub suivant : 
\begin{center}
    \url{https://github.com/BoschSensortec/BME680_driver}
\end{center}

\subsubsubsection{Bosch Sensortec Environmental Cluster}
\label{sec-software_bme680_bsec}

Comme expliqué dans la section précédente, ainsi qu'en \cref{sec-hardware_bme680}, la grande partie du traitement des données s'effectue en software. Le fabricant propose une bibliothèque nommée Bosch Sensortec Environmental Cluster (BSEC). BSEC n'est pas open source, elle est fournie précompilée pour diverses architectures, limitant le débogage du système, mais permettant ainsi de garder secret l'algorithme utilisé. La bibliothèque à l'adresse suivante :

\begin{center}
    \url{https://www.bosch-sensortec.com/bst/products/all_products/bsec}
\end{center}

\begin{figure}[ht!]
    \centering
    
    \caption{Niveaux de l'indice IAQ}
    \label{fig-bme680_iaq_indexes}
\end{figure}

\begin{figure}[ht!]
    \centering
    
    \caption{Niveaux de l'indice IAQ Accuracy}
    \label{fig-iaq_accuracy}
\end{figure}

Pour utiliser cette bibliothèque, le \textit{driver} BME680 doit être également utilisé et lié au projet. La qualité de l'air est mise à disposition à l'aide de l'indicateur \textit{Indoor Air Quality} (IAQ). Celle-ci est accompagnée d'un niveau de fiabilité nommé IAQ \textit{Accuracy}. L'IAQ est calculé à l'aide d'un algorithme propriétaire dont la valeur finale se situe entre 0 et 500. Les différents paliers de cet indice sont visibles sur la \cref{fig-bme680_iaq_indexes}. Selon le guide d'intégration de la bibliothèque BSEC \cite{BSEClib:online}, le périphérique nécessite 4 à 28 jours de calibration. Sur cette période, le composant doit être exposé 30min au milieu le moins pollué possible et 30min dans un milieu très pollué, afin de permettre une calibration plus correcte. La température et l'humidité sont également corrigées en fonction de l'environnement et la bibliothèque offre même la possibilité de placer un offset sur les valeurs pour prendre en compte l'échauffement des composants électroniques à proximité.

\subsubsection{Bibliothèques et \textit{drivers} développés}

Tous les fichiers présents sur la \cref{fig-board_paths} illustrant le répertoire \texttt{board} qui ne sont pas dans un sous répertoire ont été développés pour ce projet. Les sous-sections qui suivent ont pour but d'expliquer l'utilité des fichiers les plus importants. 

\subsubsubsection{\texttt{pin\_mux}}

\begin{figure}[ht!]
    \centering
    
    \caption{Utilitaire de configuration du multiplexeur de pins des microcontrôleurs NXP}
    \label{fig-mcuxpresso_pin_tools}
\end{figure}

Le KW41Z est équipé d'un multiplexeur de pins, cela signifie que chaque pin peut avoir plusieurs rôles qui peuvent se modifier en cours d'exécutions. Pour aider les programmeurs, NXP propose dans le cadre de son SDK, un utilitaire nommé MCUXpresso Config Tools \footnote{\url{https://mcuxpresso.nxp.com/en/pins}}. Cet utilitaire est visible sur la \cref{fig-mcuxpresso_pin_tools}. Une fois les pins connectés sur l'utilitaire, il est possible d'exporter la configuration sous forme de fichier source afin d'être intégré au projet.

\subsubsubsection{\texttt{board}}

Une partie de ces deux fichiers est une reprise des divers exemples prodigués par NXP. Leur rôle est de fournir des accès génériques sans tenir compte du pinout appliqué au microcontrôleur. Par exemple, on peut y trouver une fonction nommée \path{BOARD_EnterLowPowerCb} offrant ainsi la possibilité de mettre le processeur en mode basse consommation. 

\subsubsubsection{\texttt{bme680 et bno055 support}}

Les drivers et bibliothèques du BME680 et BNO055 sont très bien fournis (cf. \cref{sec-softwaire_driver_bno} et \cref{sec-softwaire_driver_bme680}), mais il faut leur spécifier les interfaces matérielles qui communiquent avec le périphérique. Dans les deux cas, il s'agit d'un BUS I2C. Pour éviter tout problème de concurrence entre les tâches qui utilisent la même interface, le driver \path{fsl_i2c_freertos} a été utilisé dans ces deux bibliothèques. \\
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

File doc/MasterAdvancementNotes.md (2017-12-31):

# Master Thesis : Note taking

Da Silva Andrade

# 13.07.2017

Les gens rencontrés : 

Hopkins Gavin (DSE) <gavin.hopkins@etat.ge.ch> (Ingénieur réseau)

- Si besoin d'accès spécifiques au réseau

Benammour Abdenbi (DSE) <abdenbi.benammour@etat.ge.ch>

- Questions liées à l'application finale

Feroul Maxime (DSE) <maxime.feroul@etat.ge.ch> (Dévelloppeur Kyos et état)

- Questions liées à LoRa et réseau. Si besoin de créer des objets virtuelles sur la plateforme FiWare

Notes prises durant l'entretient : 

- Penser au niveau de batterie
- Penser aux "Quality of data" du côté application finale
- L'échange de clés n'est pas encore fixé
- Taille des clés échangées de type AES-128
- Lorsque qu'un device effectue un join, deux clées sont déjà échangées

# 18.09.2017

### Keil license 

http://www2.keil.com/stmicroelectronics-stm32/mdk
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

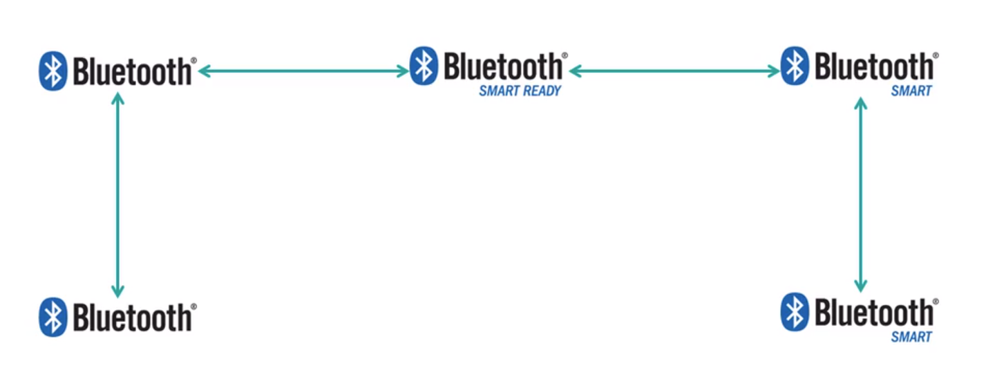
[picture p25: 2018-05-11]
doc/report_latex/Figures/protocols/Bluetooth/bluetooth_interoperabilty.PNG

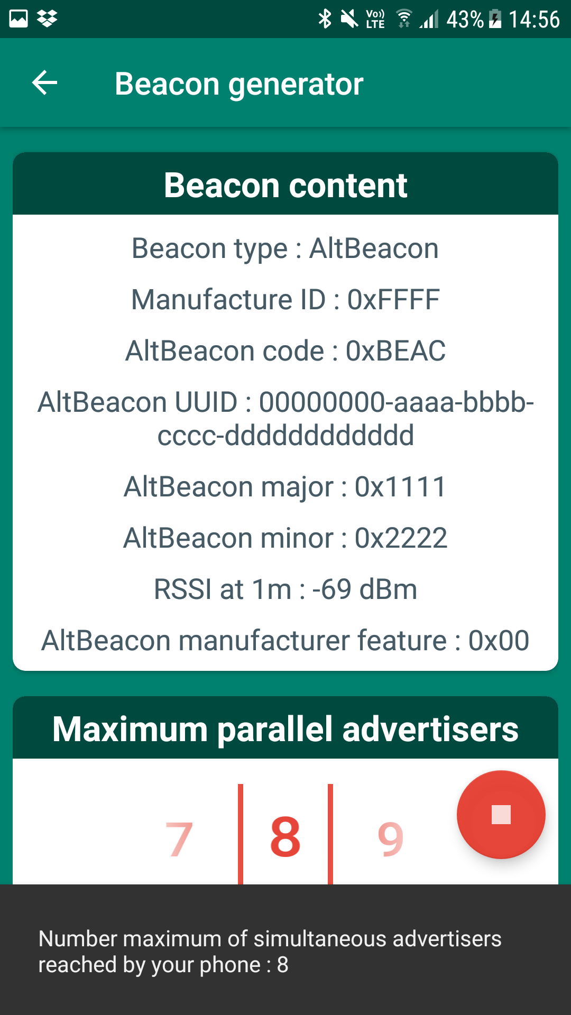
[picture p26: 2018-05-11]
doc/report_latex/Figures/Appendixes/Android/edit/beacon_gen_adv_started.png

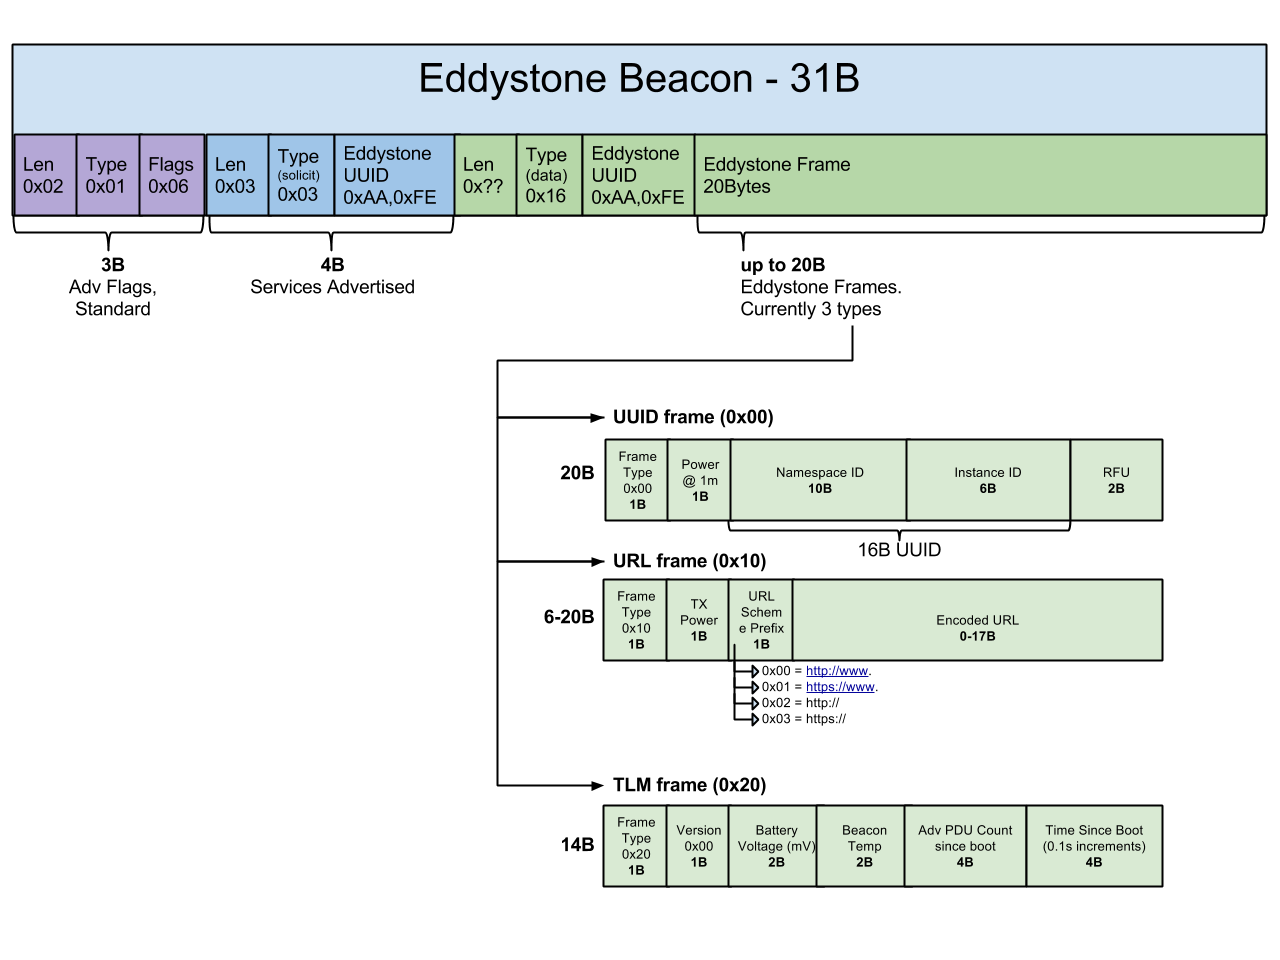
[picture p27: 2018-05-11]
doc/report_latex/Figures/protocols/Bluetooth/eddystone-spec-exploded-view.png

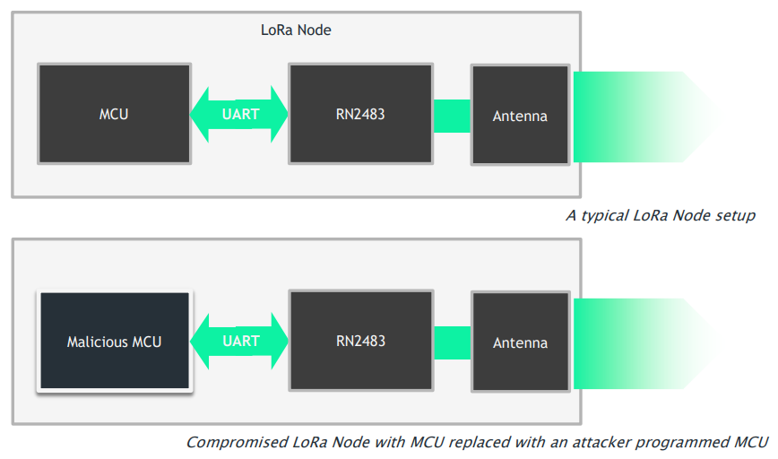
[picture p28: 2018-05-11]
doc/report_latex/Figures/Security/LoRaWAN/hardware_attack.png

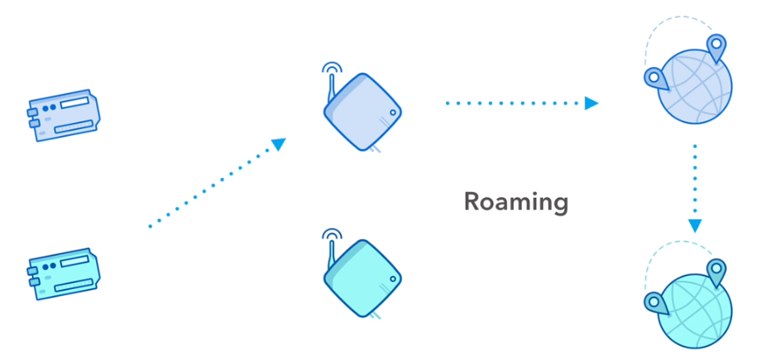
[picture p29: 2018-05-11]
doc/report_latex/Figures/protocols/LoRaWAN/lorawan_roaming.png

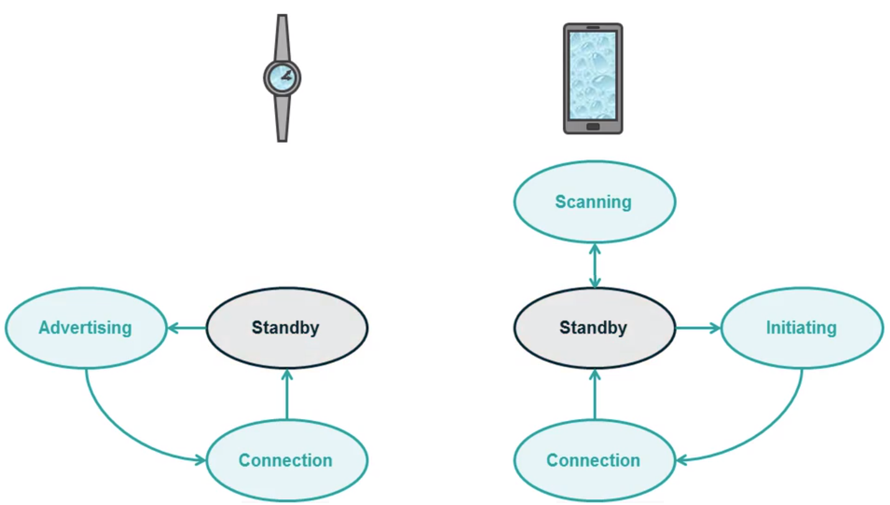
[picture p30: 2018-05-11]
doc/report_latex/Figures/protocols/Bluetooth/states_while_connecting.PNG

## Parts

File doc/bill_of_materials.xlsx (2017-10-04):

Comment | Description | Designator | Footprint | LibRef | Quantity | Supplier 1 | Supplier Part Number 1 | Quantity
653-B3U-1000P |  | B1, B2, B3, B4, B5, B6 | B3U-1000P | PUSH_BUTTON | 6 | Mouser | 653-B3U-1000P (https://octopart-clicks.com/click/altium?sku=653-B3U-1000P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) | 30
USBLC6-2SC6 | Very low capacitance ESD protection, 3.5 pF, -40 to 125 degC, 6-Pin SOT23, RoHS, Tape and Reel | D1 | STM-SOT23-6L_V | CMP-2000-05378-1 | 1 | Mouser | 511-USBLC6-2SC6 (https://octopart-clicks.com/click/altium?sku=511-USBLC6-2SC6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) | 5
S1A | General-Purpose Rectifier, Vrrm = 50V | D2, D3 | DO-214AC | CMP-001-0034-A.1 | 2 | Mouser | 750-CDBA340L-HF | 10
LTST-C190KRKT | LED Uni-Color Red, 62.5 mW, 5 V, -30 to 85 degC, 2-Pin SMD, RoHS, Tape and Reel | DS1, DS5 | LTST-C191KRKT_V | CMP-00027-A.1 | 2 | Mouser | 859-LTST-C190KRKT (https://octopart-clicks.com/click/altium?sku=859-LTST-C190KRKT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) | 20
LTST-C190KGKT | LED Uni-Color Green, 75 mW, 5 V, -30 to 85 degC, 2-Pin SMD, RoHS, Tape and Reel | DS2, DS6, DS9, DS10 | LITE-ON-LTST-C190GKT-2_V | CMP-00026-A.1 | 4 | Mouser | 859-LTST-C190KGKT (https://octopart-clicks.com/click/altium?sku=859-LTST-C190KGKT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) | 40
LTST-C190TBKT | Single Color Chip LED, 2.8 to 3.8 V, 28 to 180 mcd, -20 to 80 degC, 2-Pin SMD, RoHS, Tape and Reel | DS3, DS7 | LTST-C190TBKT-2_V | CMP-00021-A.1 | 2 | Mouser | 859-LTST-C190TBKT (https://octopart-clicks.com/click/altium?sku=859-LTST-C190TBKT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) | 20
LTST-C190KSKT | LED Uni-Color Yellow, 75 mW, 30 mA, -30 to 85 degC, 2-Pin SMD, RoHS, Tape and Reel | DS4, DS8 | LTST-C190KSKT_V | CMP-00025-A.1 | 2 | Mouser | 859-LTST-C190KSKT (https://octopart-clicks.com/click/altium?sku=859-LTST-C190KSKT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) | 20
ANT-868-CHP-T | 1/4-wave Monopole Ultra-Compact Chip Antenna, CHP Series, 868MHz, Tape and Reel | E1 | ANT-868-916-CHP | CMP-00015-A.1 | 1 | FARNELL | 712-ANT-868-CHP-T (https://octopart-clicks.com/click/altium?sku=712-ANT-868-CHP-T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) | 5
2450AT45A100E | Antennas 2.45GHz ANTENNA HIGH GAIN (VERT) | E2 | Antenne 2.4ghz Ceramique | CMP-001-0103-A.2 | 1 | Mouser | 609-2450AT45A100E | 5
U.FL-R-SMT-1 | Hirose U.FL SMT connector | J1, J2, J3 | U.FL-R-SMT-1 | CMP-001-0013-A.3 | 3 | Mouser | 798-U.FL-R-SMT-110 (https://octopart-clicks.com/click/altium?sku=798-U.FL-R-SMT-110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) | 15
10118194 |  | J4 | 10118194-0001LF | CMP-001-0075-A.1 | 1 | Mouser | 649-10118194-0001LF (https://octopart-clicks.com/click/altium?sku=649-10118194-0001LF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) | 5
0 | Ferrite Beads 1608 | L1 | INDC1608X08 | CMP-001-0101-A.4 | 1 | Mouser | 81-LQW18AN9N1C80D (https://octopart-clicks.com/click/altium?sku=81-LQW18AN9N1C80D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) | 5
5.1n | Ferrite Beads 1608 | L4 | INDC1608X08 | CMP-001-0101-A.4 | 1 | Mouser | 994-0603HP-5N1XGLU (https://octopart-clicks.com/click/altium?sku=994-0603HP-5N1XGLU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) | 5
2.2 u | Multilayer Inductor, 2.2 uH, ±20%, 300 mOhm, 50MHz, 0805(2012) | L7 | TDK-IND0805-125_V | CMP-0266-00001-1 | 1 | Mouser | 810-MLZ2012N2R2LT000 (https://octopart-clicks.com/click/altium?sku=810-MLZ2012N2R2LT000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) | 5
20021121-00010C4LF | Minitek127® : 1.27x1.27MM BTB, HEADER UNSHROUDED, SMT, 10 POSITIONS | P2 | PCBComponent | CMP-001-0019-A.2 | 1 | Mouser | 649-202112100010C4LF (https://octopart-clicks.com/click/altium?manufacturer=Amphenol%20FCI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) | 5
BNO055 | Intelligent 9-Axis Absolute Orientation Sensor, 1.7 V to 3.6 V, -40 to 85 degC, 28-Pin LGA, RoHS, Tape and Reel | U2 | BOSC-LGA-28_N | CMP-00007-A.1 | 1 | Mouser | 262-BNO055 (https://octopart-clicks.com/click/altium?sku=262-BNO055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) | 5
CX2520DB32000D0GEJZ1 | Crystal, 32 MHz, 8 pF, -10 to 70 degC, Surface Mount 2.5 x 2.0 mm | X1 | AVX-CX2520DB32000D0GEJZ1-4_V | CMP-0449-00001-2 | 1 | Mouser | 581-CX2520DB32DGEJZ1 (https://octopart-clicks.com/click/altium?sku=581-CX2520DB32DGEJZ1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) | 5
MKW41Z | 2.4 GHz Bluetooth Low Energy ver. 4.2 compliant, Up to 48 MHz ARM® Cortex-M0+ core, On-chip 512/256 KB Flash memory, On-chip 128/64 KB SRAM | U5 | QFN50P700X700X80_HS-49M | CMP-001-0100-A.1 | 1 | Mouser | 841-MKW41Z512VHT4 (https://octopart-clicks.com/click/altium?sku=841-MKW41Z512VHT4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) | 5
BQ29700 |  | U6 | SON50P150X75-6M | CMP-001-0114-A.2 | 1 | Mouser | 595-BQ29700DSET (https://octopart-clicks.com/click/altium?sku=595-BQ29700DSET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) | 5
bq24210 | 800-mA, Single-Input, Single-Cell Li-Ion Battery Solar Charger | U7 | WSON50P200X300X80-11N | CMP-001-0111-A.1 | 1 | Mouser | 595-BQ24210DQCT (https://octopart-clicks.com/click/altium?sku=595-BQ24210DQCT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) | 5
TPS62291DRVT | Buck Step Down Regulator with 2.3 to 6 V Input and 3.3 V Output, -40 to 85 degC, 6-Pin SON (DRV), Green (RoHS & no Sb/Br) | U8 | DRV0006A_V | CMP-00017-A.1 | 1 | Mouser | 595-TPS62291DRVT (https://octopart-clicks.com/click/altium?sku=595-TPS62291DRVT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) | 5
ABS07-32.768KHz-T | Crystal, 32.768 kHz, 12.5 pF, -40 to 85 degC, SMD Low Profile 3.2 x 1.5 x 0.9 mm, Tape and Reel | X2 | ABRA-ABS07-2_V | CMP-0447-00001-2 | 1 | Mouser | 815-ABS07-32.768KHZT (https://octopart-clicks.com/click/altium?sku=815-ABS07-32.768KHZT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) | 5
Header 2H | Header, 2-Pin, Right Angle | P5, P6 | HDR1X2H | Header 2H | 2 | Mouser | 538-22-05-3021 | 10
5015 | Circuit Board Hardware - PCB MINI SMT TEST POINT | TP1, TP2, TP3, TP4, TP5, TP6, TP7, TP8, TP9, TP10, TP11, TP12, TP13, TP14, TP15, TP16, TP17, TP18, TP19, TP20, TP21, TP22 | 5015 | CMP-001-0108-A.3 | 22 | Mouser | 534-5015 | 110
BME680 | Combined himidity, pressure, temp and gas sensor | U1 | LGA-8-30x30x09 | CMP-001-0107-A.4 | 1 | Mouser | 262-BME680 | 5
0.7p | MLCC Capacitor 1608 | C35 | CAPC1608X08 | CMP-001-0010-A.3 | 1 | Mouser | 77-VJ0603D0R7VXPAJ (https://octopart-clicks.com/click/altium?sku=77-VJ0603D0R7VXPAJ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) | 10
10p | MLCC Capacitor 1608 | C46 | CAPC1608X08 | CMP-001-0010-A.3 | 1 | Mouser | 77-VJ0603D100FXPAJ (https://octopart-clicks.com/click/altium?sku=77-VJ0603D100FXPAJ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) | 10
1u | MLCC Capacitor 1608 | C1, C40, C41, C42, C43 | CAPC1608X08 | CMP-001-0010-A.3 | 5 | Mouser | 710-885012106010 | 100
120n | MLCC Capacitor 1608 | C8 | CAPC1608X08 | CMP-001-0010-A.3 | 1 | Mouser | 81-GRM188R71A124JA1J | 20
10u | MLCC Capacitor 2012 | C44, C45 | CAPC2012X14 | CMP-001-0011-A.3 | 2 | Mouser | 81-GRM219C80G106KE9D | 25
6.8n | MLCC Capacitor 1608 | C9 | CAPC1608X08 | CMP-001-0010-A.3 | 1 | Mouser | 710-885012206064 | 10
1u | MLCC Capacitor 1608 | C11, C18, C26 | CAPC1608X08N | CMP-001-0010-A.1 | 3 | Mouser | 710-885012106010 | 200
10u | MLCC Capacitor 1608 | C13, C16, C17, C25, C29 | CAPC1608X08N | CMP-001-0010-A.1 | 5 | Mouser | 81-GRM188C80G106KE7J | 100
8p | MLCC Capacitor 1608 | C24, C30, C31 | CAPC1608X08 | CMP-001-0010-A.3 | 3 | Mouser | 810-CGA3E2C0G1H080D | 30
12.5p | MLCC Capacitor 1608 | C33, C34 | CAPC1608X08 | CMP-001-0010-A.3 | 2 | Mouser | 581-0603YA120KAT2A | 20
150 | 1608 resistor | R1, R3, R6, R7, R8, R10 | RESC1608X06 | CMP-001-0005-A.4 | 6 | Mouser | ERA-3AEB151V | 200
15 | 1608 resistor | R4, R9 | RESC1608X06 | CMP-001-0005-A.4 | 2 | Mouser | 594-MCT06030C1509FP5 | 50
100k | 1608 resistor | R21, R28 | RESC1608X06 | CMP-001-0005-A.4 | 2 | Mouser | 754-RR0816P-104D | 200
330 | 1608 resistor | R29 | RESC1608X06 | CMP-001-0005-A.4 | 1 | Mouser | 594-MCT06030C3300FP5 | 200
2k | 1608 resistor | R30, R33, R34 | RESC1608X06 | CMP-001-0005-A.4 | 3 | Mouser | 279-CPF0603F2K0C1 | 30
10M | 1608 resistor | R31, R32 | RESC1608X06 | CMP-001-0005-A.4 | 2 | Mouser | 594-MCT06030C1005FP5 | 20
780 | 1608 resistor | R35, R36, R37, R38 | RESC1608X06 | CMP-001-0005-A.4 | 4 | Mouser | 660-RN731JTTD7770D25 | 20
PMOD 6x2 | Header, 6-Pin, Dual row | P3, P4 | PMOD SMD Header 6x2 | CMP-001-0115-A.1 | 2 |  |  | 10
CMWX1ZZABZ-078 | RF Modules Type ABZ LoRa Module MCU - STM32L082 | U4 | CMWX1ZZABZ-078 | CMP-001-0102-A.1 | 1 | Mouser | 81-CMWX1ZZABZ-078 (https://octopart-clicks.com/click/altium?sku=81-CMWX1ZZABZ-078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) | 5

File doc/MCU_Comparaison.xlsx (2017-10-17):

Fabricant | Model | CPU | BLE 4.2 | BLE 5.0 | IEEE 802.15.4 | Sub 1GHz | Receive Current | Transmit Current (@ 2.4Ghz, @ 0dBm) | Flash/ SRAM | Disponibility | Price
NXP | KW41Z | Cortex-M0+ | Yes | No | Yes | No | 6.8 mA | 6.1 mA | 512 kB / 128 kB | Yes | 6.34 CHF
NXP | QN908x | Cortex-M4F | Yes | Yes | No | No | 3.4 mA | 3.4 mA | 512 kB / 128 kB | Yes | 5.87 CHF
Texas Instrument | CC2650 | Cortex-M3 | Yes | No | Yes | No | 6.2 mA | 6.8 mA | 128 kB / 128 kB | Yes | 6.34 CHF
Texas Instrument | CC2640R2F | Cortex-M3 | Yes | Yes | No | No | 6.1 mA | 7.0 mA | 128 kB / 20 kB | Yes | 6.34 CHF
Nordic Semiconductors | NRF52832 | Cortex-M4F | Yes | Yes | No | No | 5.4 mA | 5.3 mA | 512 kB / 64 kB | Yes | 5.51 CHF
Nordic Semiconductors | NRF52840 | Cortex-M4F | Yes | Yes | Yes | No | N/A | N/A | 1 MB / 256 kB | No | N/A
Silicon Labs | EFR32MG12P433F1024GL125 | Cortex-M4F | Yes | Yes | Yes | Yes | 9.3 mA | 9.5 mA | 1 MB / 256 kB | Yes | 13.51 CHF

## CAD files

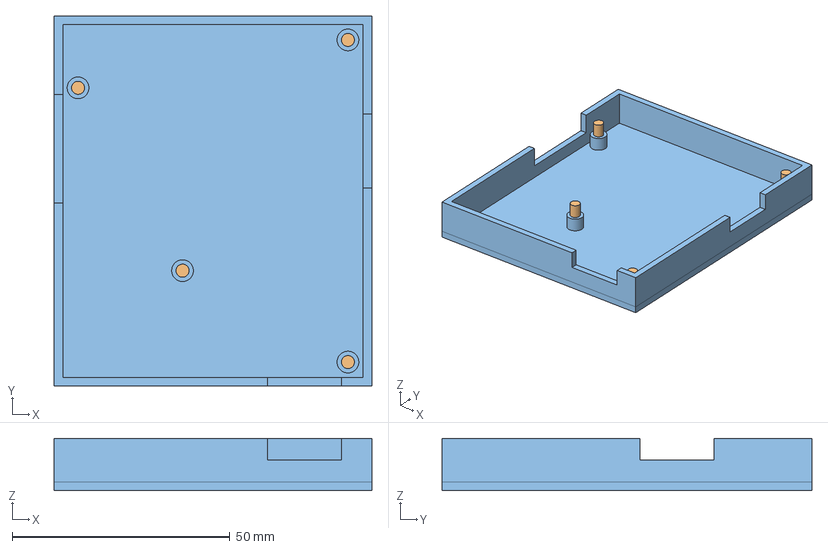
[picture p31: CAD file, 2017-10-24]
hardware/SmartCantonDevBoxCase/SmartCantonDevBoxCase2.FCStd
73.0 x 85.0 x 12.0 mm

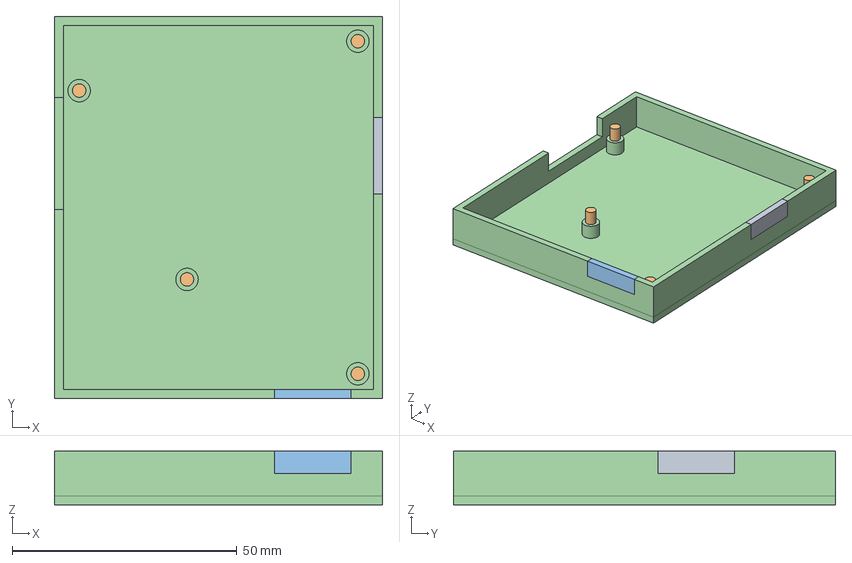
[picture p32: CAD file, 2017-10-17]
hardware/SmartCantonDevBoxCase/SmartCantonDevBoxCase.FCStd
73.0 x 85.0 x 12.0 mm

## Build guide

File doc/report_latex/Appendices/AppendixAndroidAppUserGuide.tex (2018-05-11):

% Appendix Template

\appendixpagenumbering % Restart numbering for each appendix

\chapter{Android SmartCanton Manager: User's Guide} % Main appendix title
\label{AppendixAndroidAppUserGuide} 

% ---------------------------------------------------------------------- %
\section{Login Activity}
% ---------------------------------------------------------------------- %
\begin{figure}[ht!]
    \centering
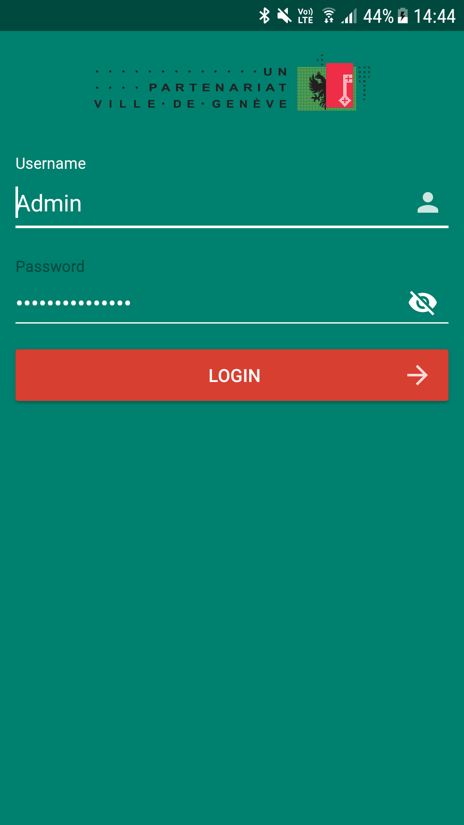
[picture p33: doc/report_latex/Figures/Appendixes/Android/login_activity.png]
    
    \caption{SmartCanton Manager login activity}
    \label{fig_apdx-login_activity}
\end{figure}

When the application is launched, the user is required to log in using his credentials from the AppKey Server, as shown by the \cref{fig_apdx-login_activity}. 

% ---------------------------------------------------------------------- %
\FloatBarrier
\section{Bluetooth Activity : Scanner BLE Fragment}
% ---------------------------------------------------------------------- %
\begin{figure}[ht!]
    \centering
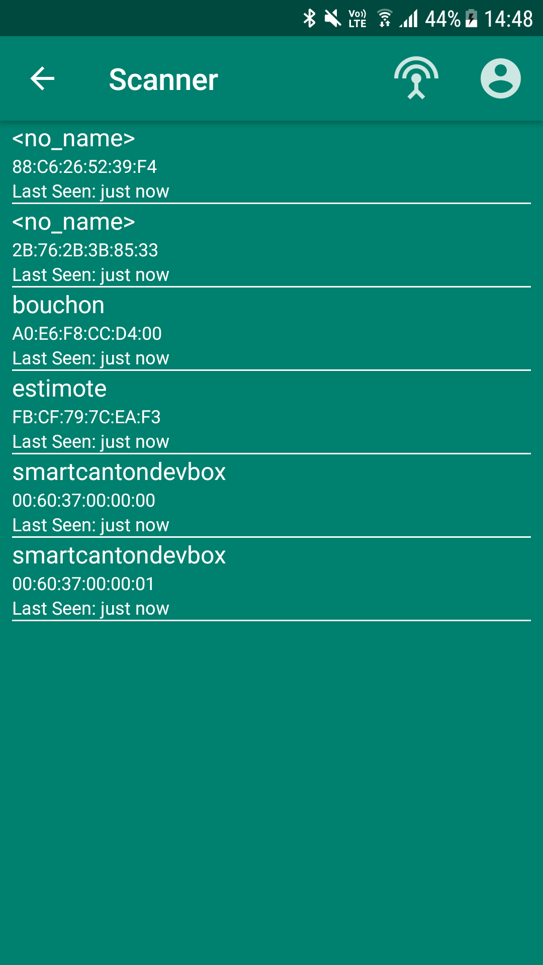
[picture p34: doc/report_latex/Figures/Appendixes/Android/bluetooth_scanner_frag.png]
    
    \caption{SmartCanton Manager scanner fragment}
    \label{fig_apdx-bluetooth_scanner_frag}
\end{figure}

Once the user logged, all devices broadcasting ble packets nearby will be displayed in a list, as shown by the \cref{fig_apdx-bluetooth_scanner_frag}. The list can take a bit to be updated, just wait a moment. If the list still not display itself, just activate the \textit{airplane mode} on the phone and restart the SmartCanton Manager app.

% ---------------------------------------------------------------------- %
\FloatBarrier
\section{Bluetooth Activity : Device Management Fragment}
% ---------------------------------------------------------------------- %
\begin{figure}[ht!]
    \centering
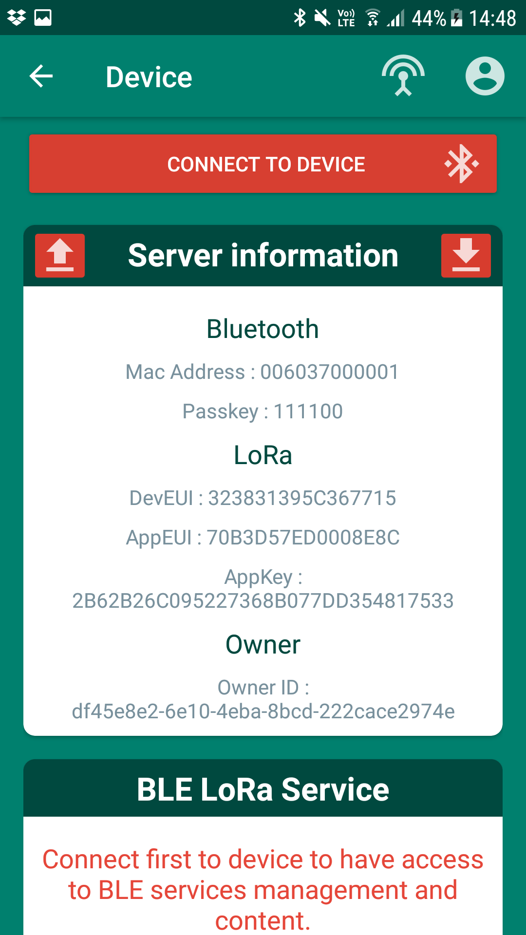
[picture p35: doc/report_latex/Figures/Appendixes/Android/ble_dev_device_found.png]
    
    \caption{SmartCanton Manager device found on the server}
    \label{fig_apdx-ble_dev_device_found}
\end{figure}

When a Bluetooth device is selected on the BLE Scanner list, the fragment illustrated by the \cref{fig_apdx-ble_dev_device_found} is shown. If the device is found on the server, his information are displayed inside the \texttt{Server information} card. Those data can be updated by pressing the arrow on the right of the card.

\begin{figure}[ht!]
    \centering
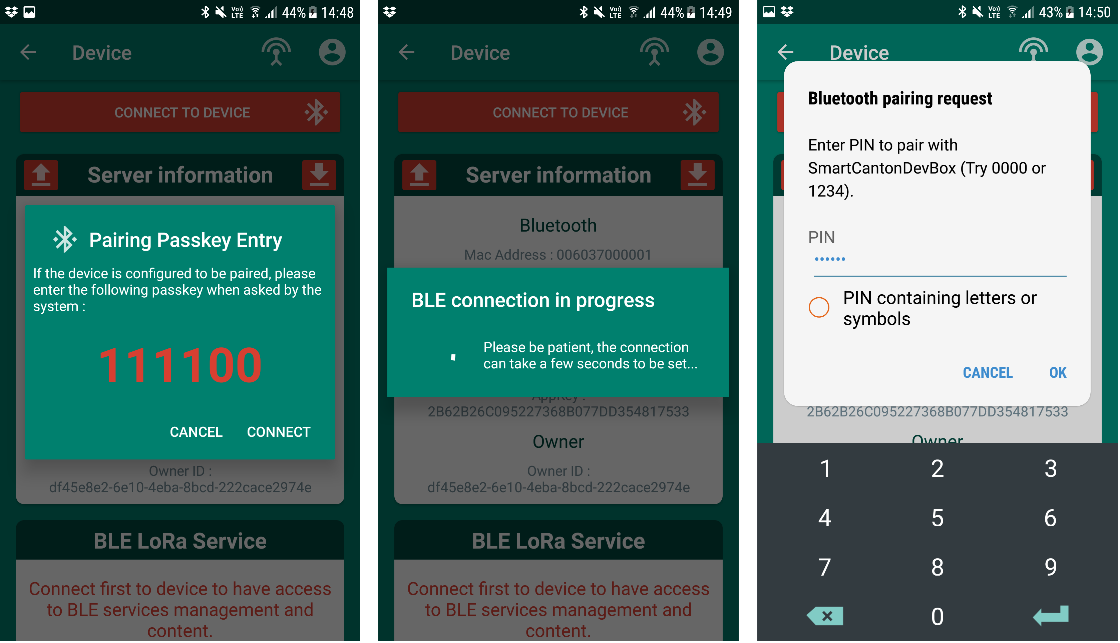
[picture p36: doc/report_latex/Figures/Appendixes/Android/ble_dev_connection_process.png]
    
    \caption{SmartCanton Manager connection progress}
    \label{fig_apdx-ble_dev_connection_process}
\end{figure}

To connect to the device using Bluetooth Low Energy, the red button named \texttt{CONNECT TO DEVICE} on the top of the fragment needs to be pressed. The \cref{fig_apdx-ble_dev_connected_startup} shows the sequence of the connection. First a dialog inform the user that a BLE Passkey is present in the device and that the user need to remember it. Then the application will try to connect to the device. Finally, Android will ask the user to pair and bond with the device using the BLE Passkey previously displayed.

\begin{figure}[ht!]
    \centering
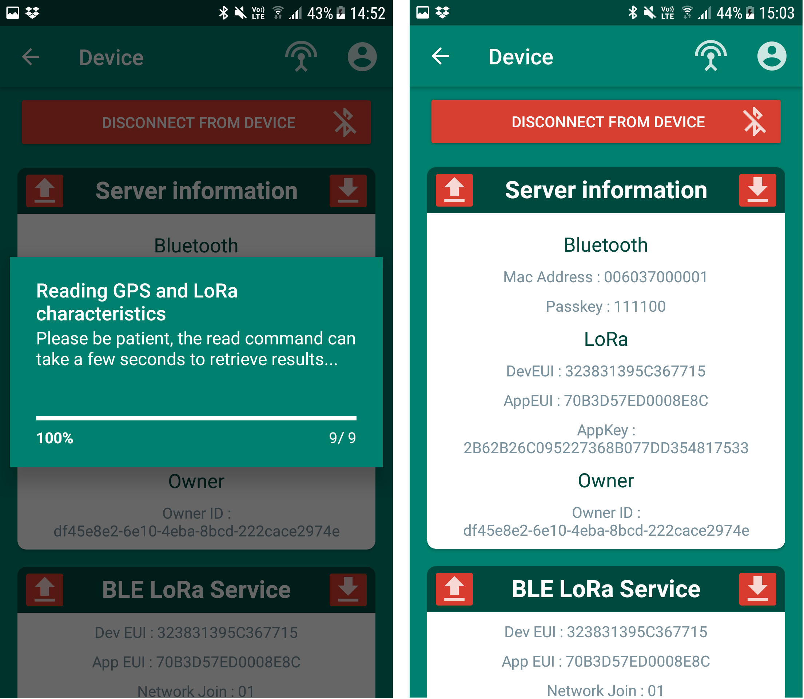
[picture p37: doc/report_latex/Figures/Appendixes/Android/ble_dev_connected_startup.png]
    
    \caption{SmartCanton Manager device connected and characteristics read}
    \label{fig_apdx-ble_dev_connected_startup}
\end{figure}

Once the device is connected, the characteristics from the LoRa Service and the GPS of the DevBox are read and displayed in their respective cards, as shown on the \cref{fig_apdx-ble_dev_connected_startup}. The user can access to the multiples Bluetooth services available on the device. The user can disconnect from the device by leaving the current fragment (back button) or by pressing the \texttt{DISCONNECT FROM DEVICE} button on the top of the page.

\begin{figure}[ht!]
    \centering
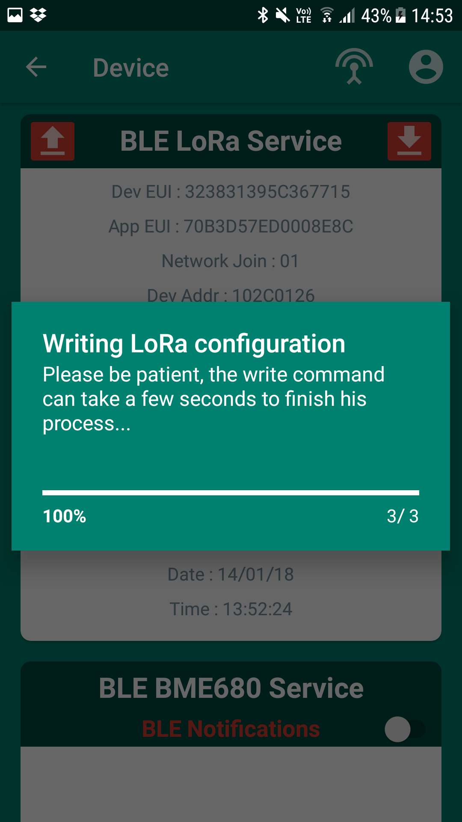
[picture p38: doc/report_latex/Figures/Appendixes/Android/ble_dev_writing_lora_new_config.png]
    
    \caption{SmartCanton Manager update LoRaWAN config from server configuration}
    \label{fig_apdx-ble_dev_writing_lora_new_config}
\end{figure}

When the red arrow on the left of the \texttt{BLE LoRaWAN Service} is pressed, the device will be configured with the data read from the Server and diplayed in the \texttt{Server information} card. While the LoRaWAN service is been updated, a progress dialog is shown like in the \cref{fig_apdx-ble_dev_writing_lora_new_config}.

\begin{figure}[ht!]
    \centering
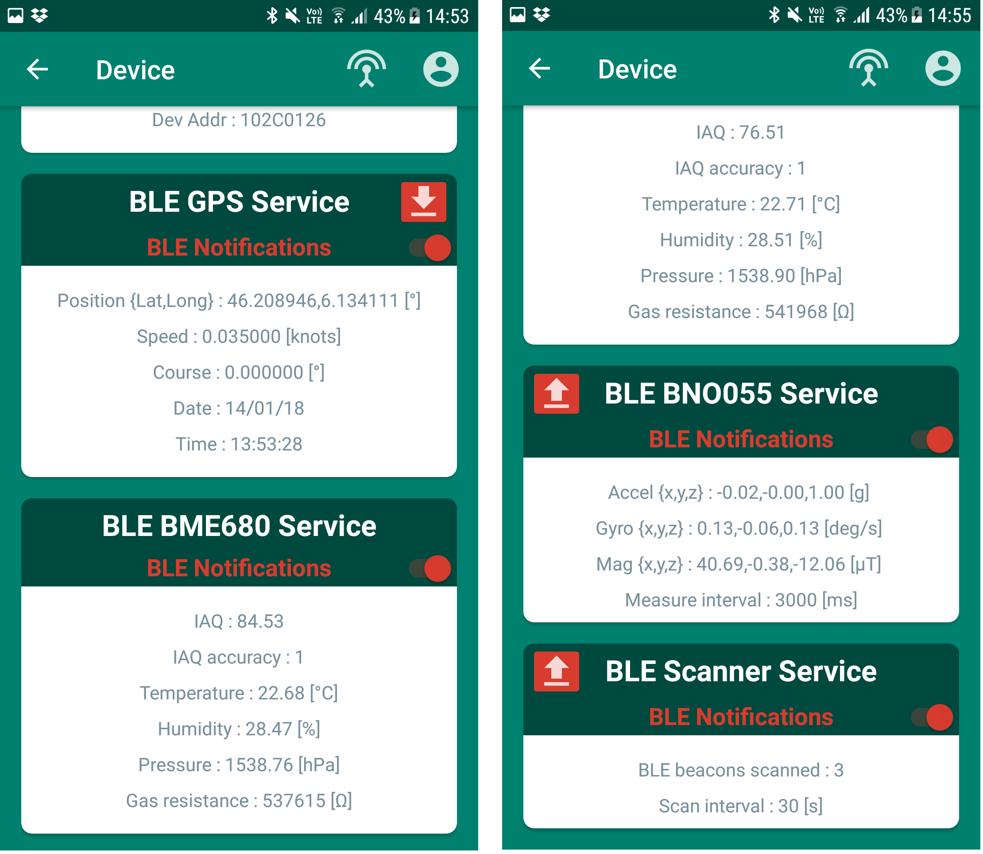
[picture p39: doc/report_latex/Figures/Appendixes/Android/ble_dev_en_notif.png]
    
    \caption{SmartCanton Manager enable sensors notifications}
    \label{fig_apdx-ble_dev_en_notif}
\end{figure}

The user can toggle the notifications button for each sensor, as shown by the \cref{fig_apdx-ble_dev_en_notif}. Everytime a new data is read from the sensors, the application will display it.

\begin{figure}[ht!]
    \centering
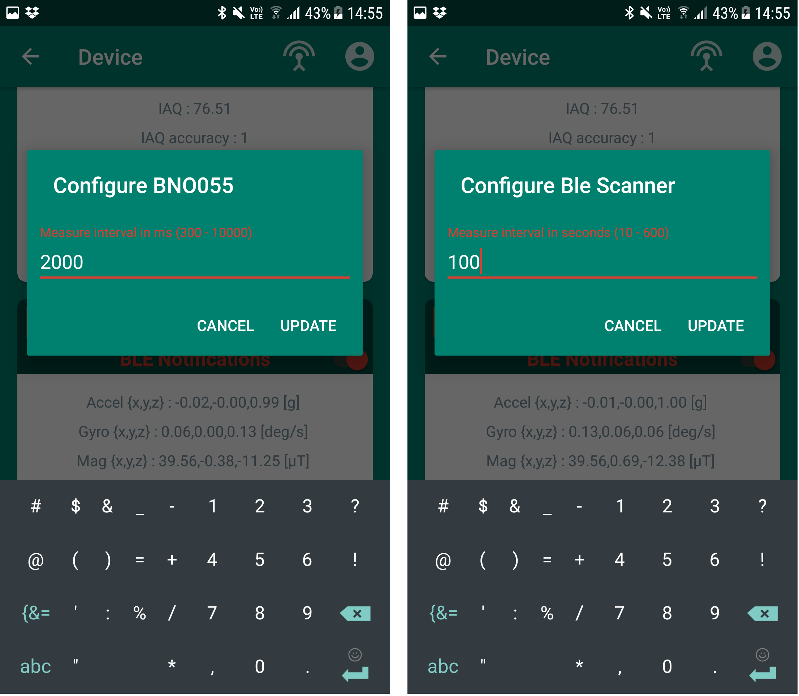
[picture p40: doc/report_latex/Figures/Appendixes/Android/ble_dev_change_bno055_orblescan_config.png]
    
    \caption{SmartCanton Manager edit bno055 or ble scanner interval}
    \label{fig_apdx-ble_dev_change_bno055_orblescan_config}
\end{figure}
The user can configure the interval beetween each notifications from the BNO055 or the BLE Scanner, as shown by the \cref{fig_apdx-ble_dev_change_bno055_orblescan_config}.

% ---------------------------------------------------------------------- %
\FloatBarrier
\section{Profile Activity}
% ---------------------------------------------------------------------- %
\begin{figure}[ht!]
    \centering
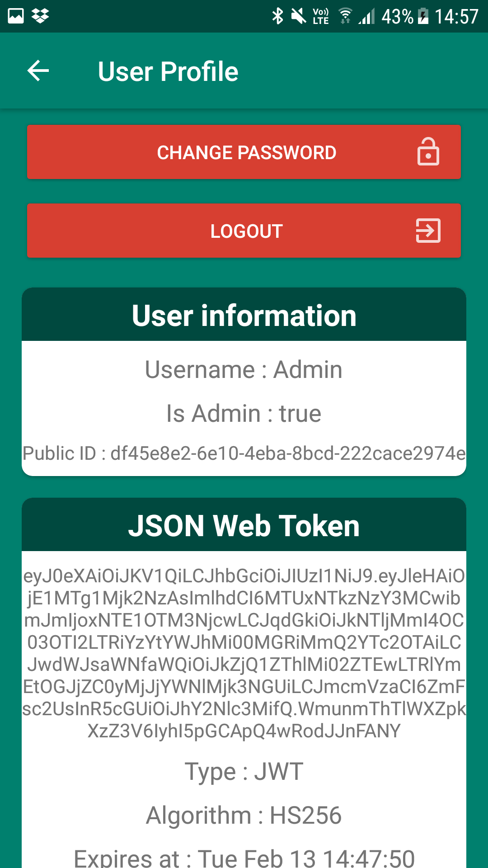
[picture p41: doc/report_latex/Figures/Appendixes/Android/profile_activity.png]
    
    \caption{SmartCanton Manager profile activity}
    \label{fig_apdx-profile_activity}
\end{figure}

The user can access his profile by clicking on the user icon on the Action Bar. The profile activity, as it can be seen on the \cref{fig_apdx-profile_activity}, contain all information stored on the server for the current logged user. The user can logout from the current session by pressing the \texttt{LOGOUT} button.\\

% ---------------------------------------------------------------------- %
\FloatBarrier
\section{Beacon Generator Activity}
% ---------------------------------------------------------------------- %
\begin{figure}[ht!]
    \centering
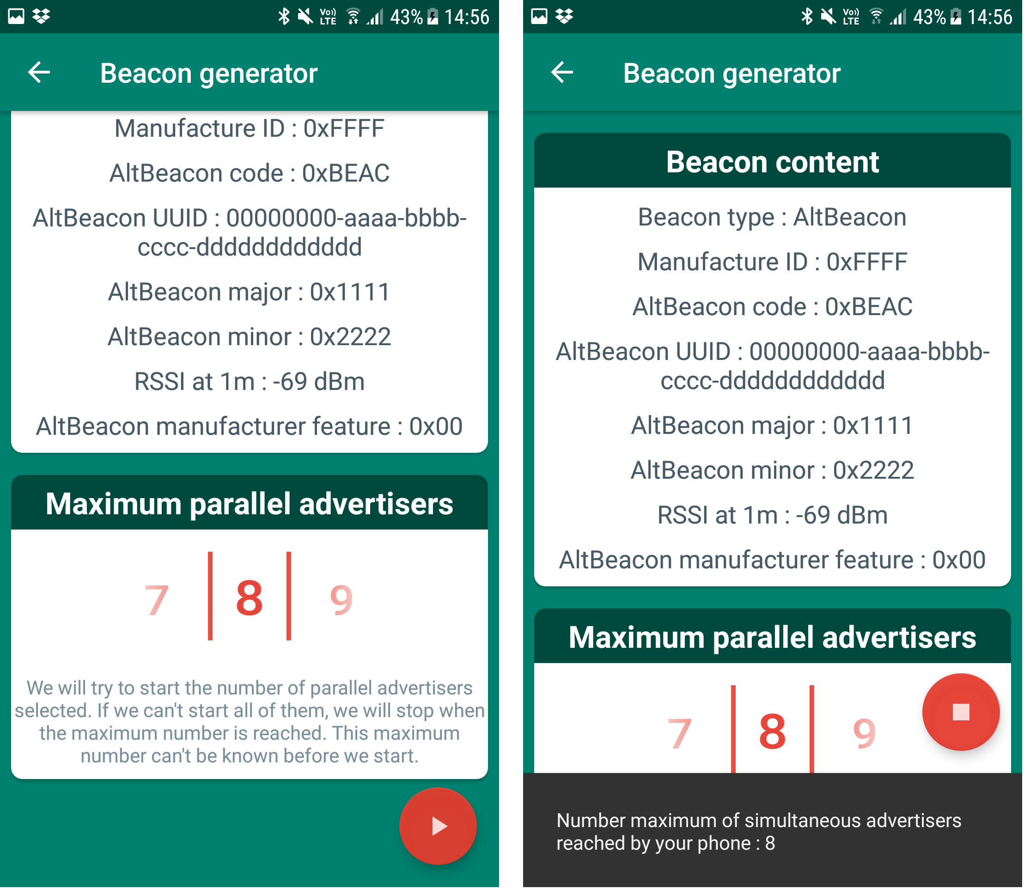
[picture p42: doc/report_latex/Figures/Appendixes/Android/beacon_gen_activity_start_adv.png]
    
    \caption{SmartCanton Manager beacon generator activity}
    \label{fig_apdx-beacon_gen_activity_start_adv}
\end{figure}
\FloatBarrier

A beacon generator has been integrated inside the Android application. His purpose is to simulate nearby devices that can be scanned by a DevBox. The \cref{fig_apdx-beacon_gen_activity_start_adv} show the activity layout and how the app react when the \textit{play} button is pressed.

The user can select the number of devices that will be simulated by the application. However, each device has a number of maximum advertiser that can run at the same time. If the user select a number of devices greater than the maximum number available, the maximum number will be displayed to the user, as shown by the \cref{fig_apdx-beacon_gen_activity_start_adv}.

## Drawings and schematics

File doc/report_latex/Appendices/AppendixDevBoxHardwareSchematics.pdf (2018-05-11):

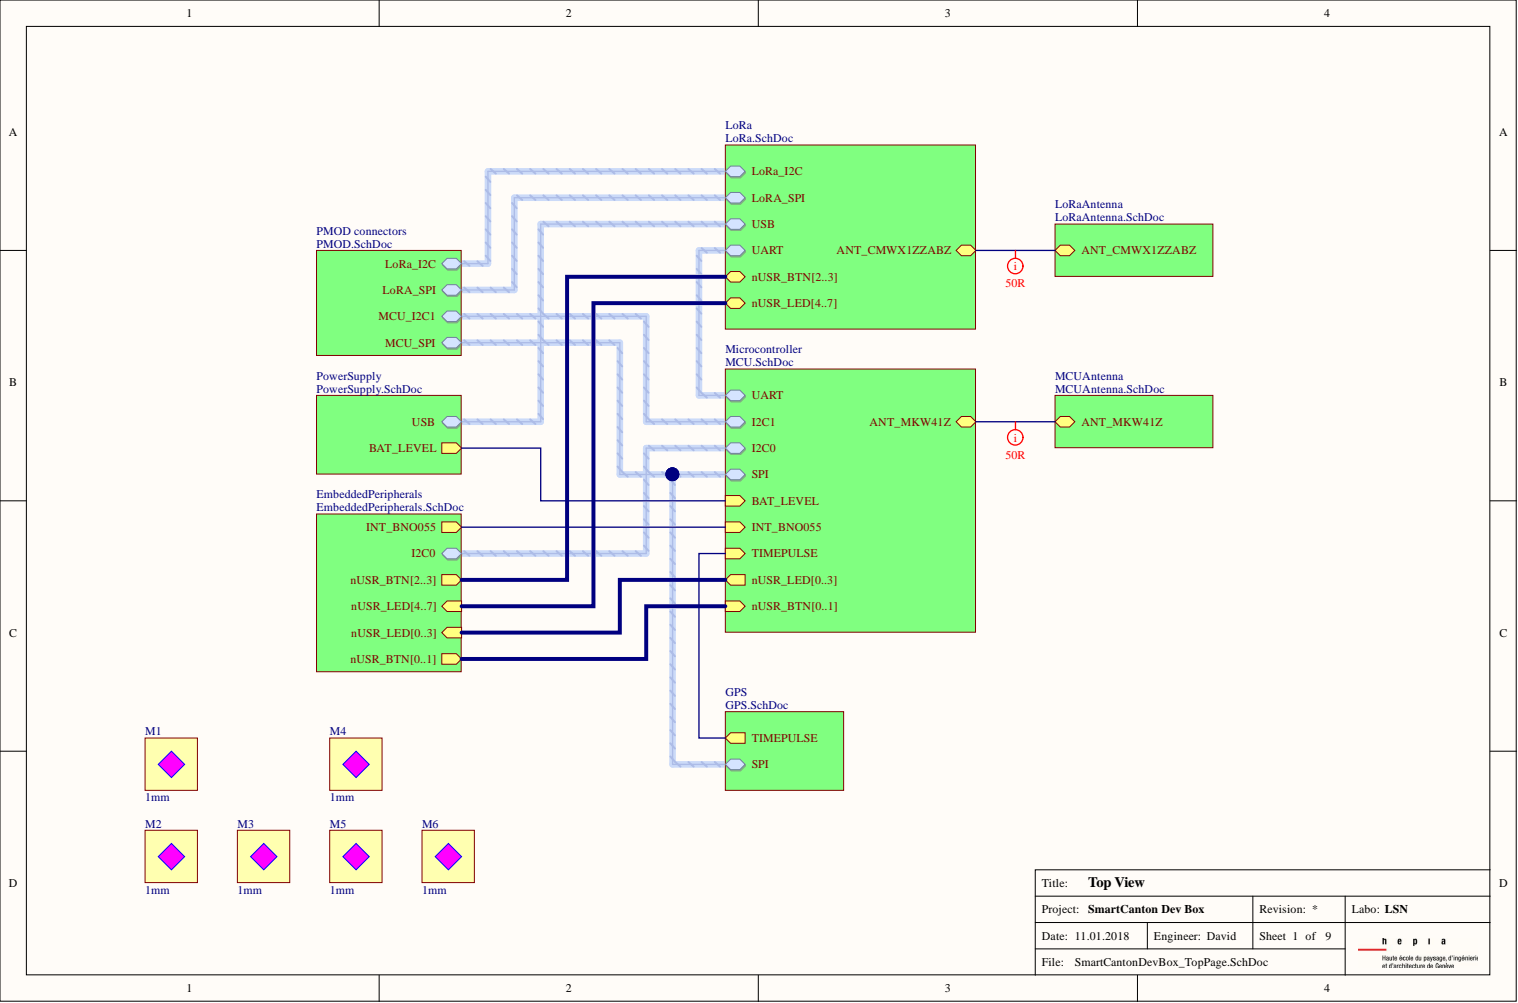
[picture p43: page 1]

Project: SmartCanton Dev Box | Revision: * | Labo: LSN

Date: 11.01.2018 | Engineer: David | Sheet 1 of 9

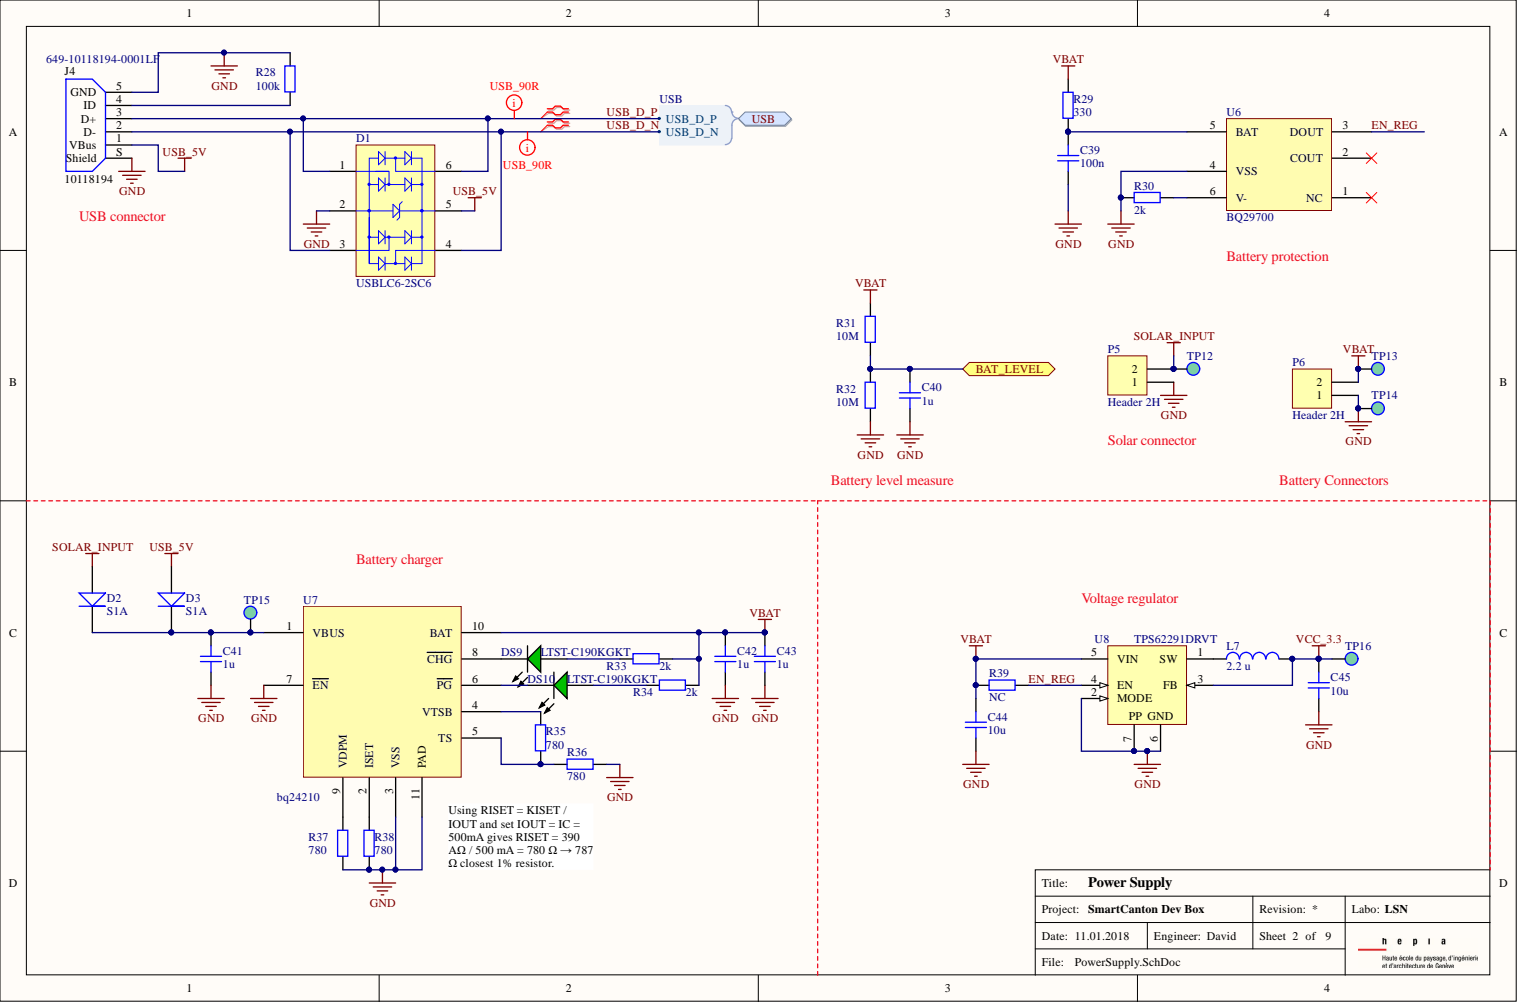
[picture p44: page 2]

Using RISET = KISET /
IOUT and set IOUT = IC =
500mA gives RISET = 390
Ω closest 1% resistor.

Power Supply Title:

Project: SmartCanton Dev Box | Revision: * | Labo: LSN

Engineer: David

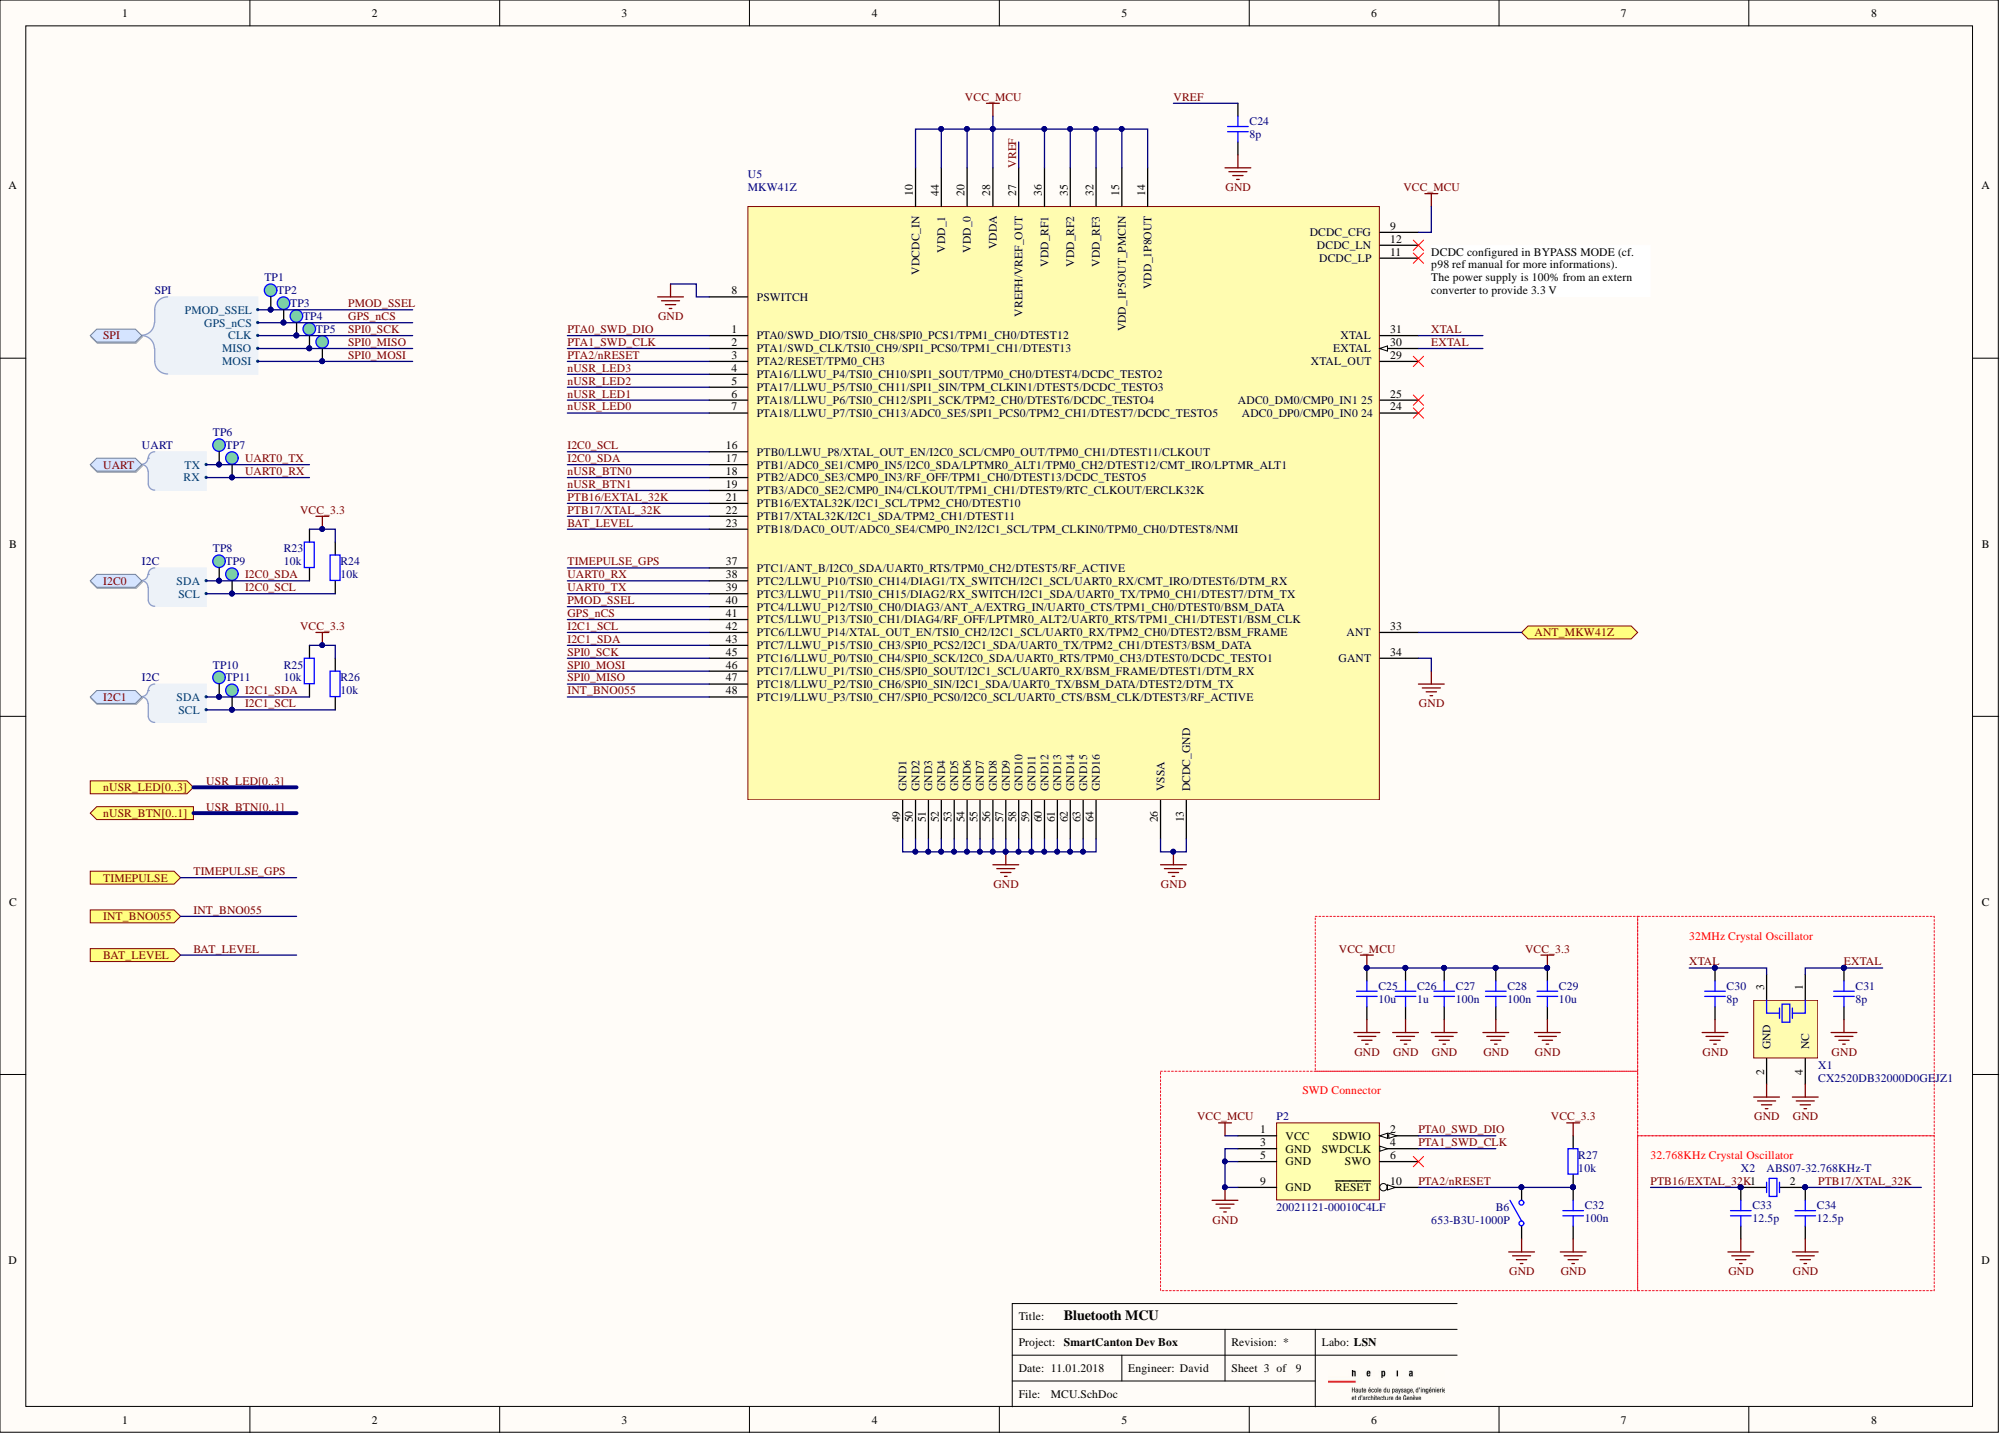
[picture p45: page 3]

VCC_MCU VCC_ 3.3 G D | 3 2MHz Cry s tal O sci l lat o r X TA L E X TA L

Project : Sm artC anton Dev Bo x | Rev i s i o n : * | Lab o : LSN

1.0 1.2 | E n g i neer: Dav i d | Sheet o f

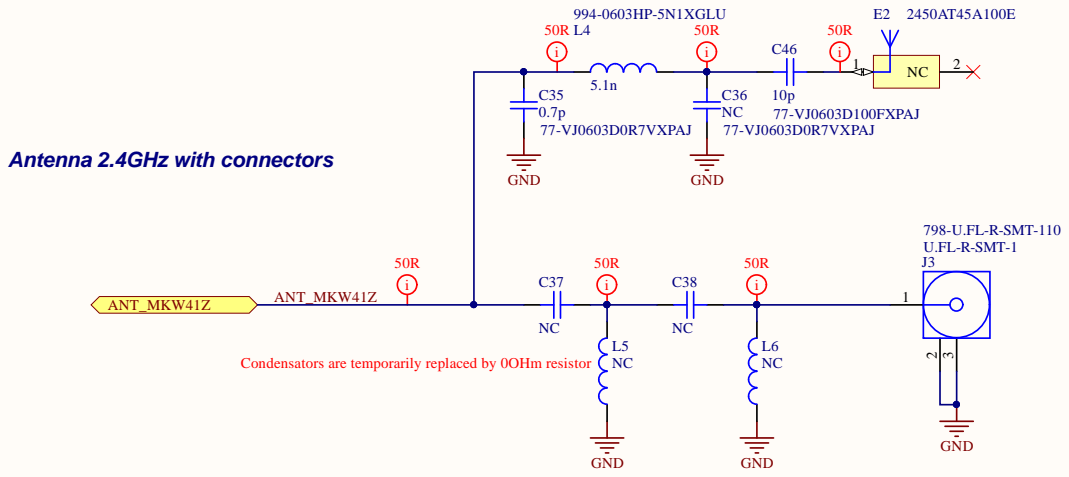
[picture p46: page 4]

Condensators are temporarily replaced by 0OHm resistor

Project: SmartCanton Dev Box | Revision: * | Labo: LSN

Engineer: David

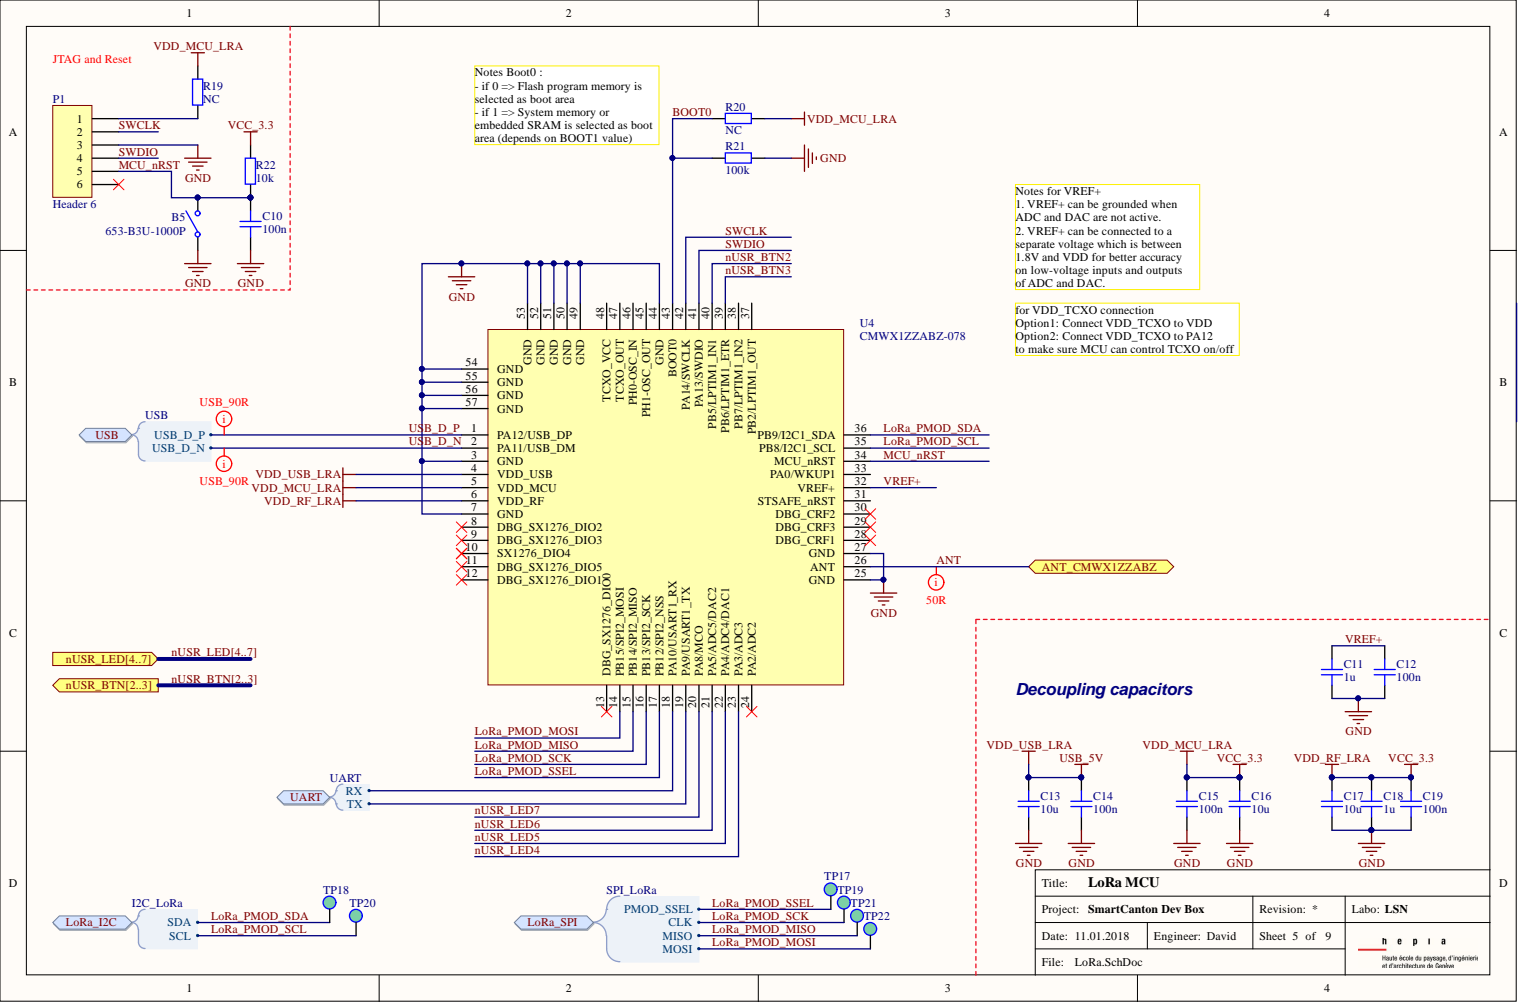
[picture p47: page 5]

Notes Boot0 :
- if 0 => Flash program memory is
selected as boot area
- if 1 => System memory or
embedded SRAM is selected as boot
area (depends on BOOT1 value)

Notes for VREF+
1. VREF+ can be grounded when
ADC and DAC are not active.
2. VREF+ can be connected to a
separate voltage which is between
1.8V and VDD for better accuracy
on low-voltage inputs and outputs
of ADC and DAC.

SWDIO
nUSR_BTN2

GND 50 GND 51 GND 52 GND 53

for VDD_TCXO connection
Option1: Connect VDD_TCXO to VDD
Option2: Connect VDD_TCXO to PA12
to make sure MCU can control TCXO on/off

VDD_USB 4

VDD_RF 6

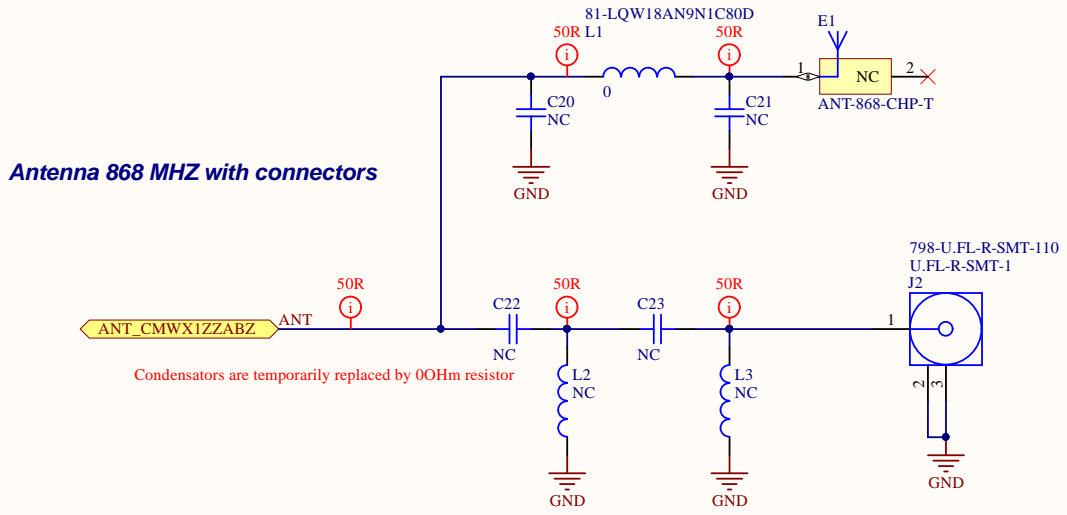
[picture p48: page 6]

Antenna 868 MHZ with connectors

Condensators are temporarily replaced by 0OHm resistor

Project: SmartCanton Dev Box | Revision: * | Labo: LSN

Engineer: David

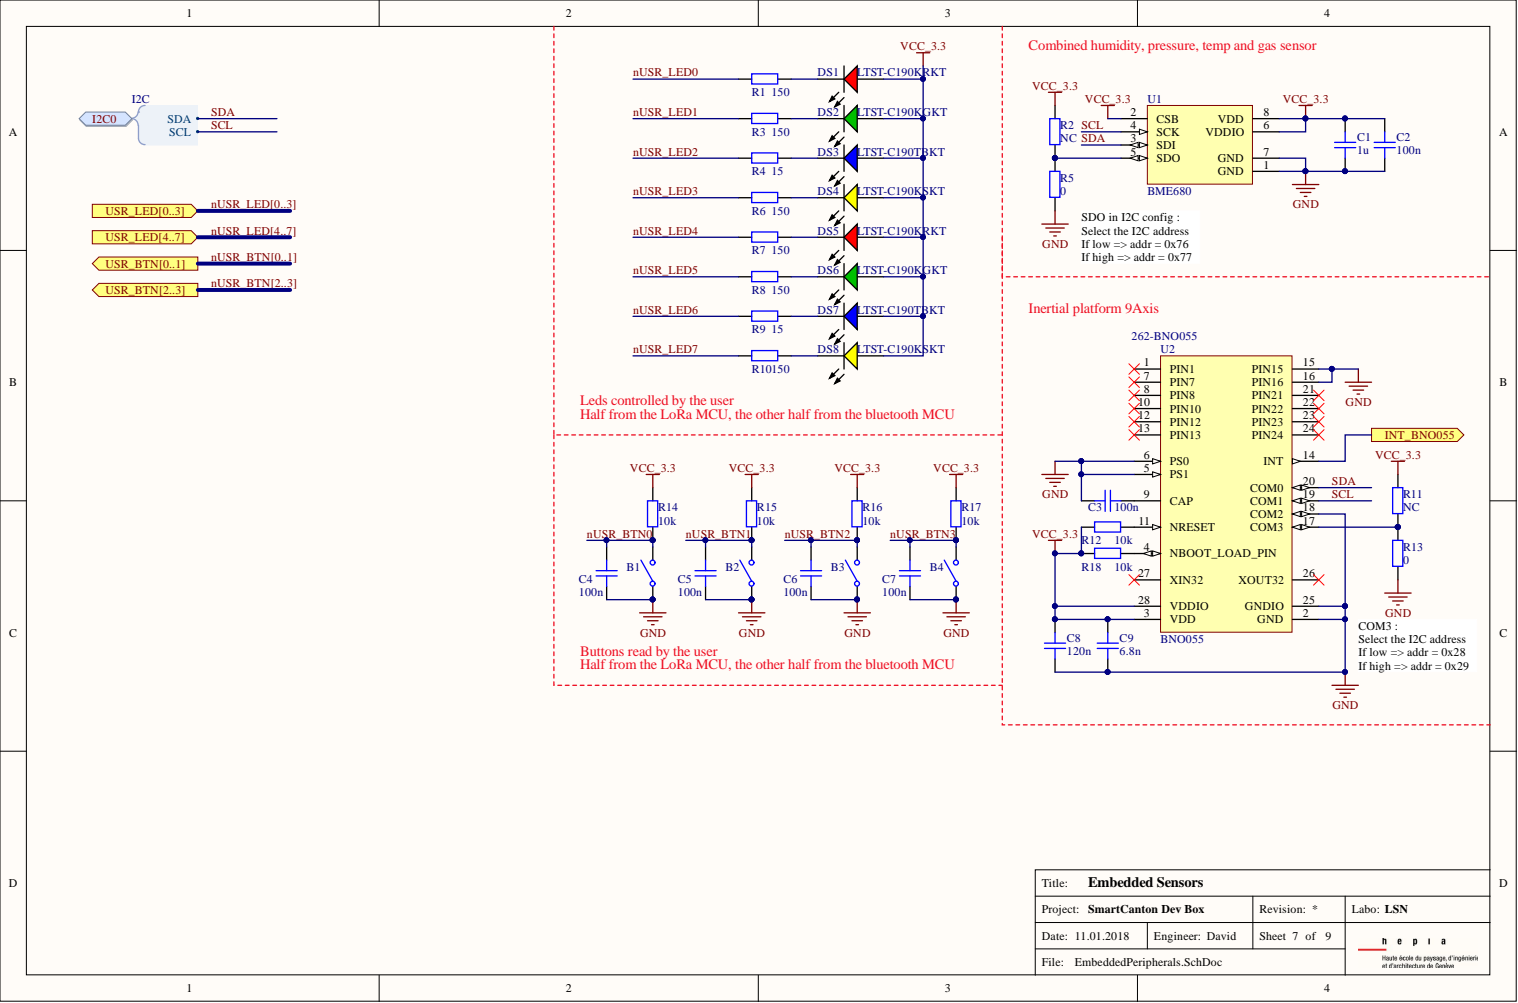
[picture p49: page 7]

3.3 R1 2 1 0 k | 4 | 18 COM1 19 GND 2 7 COM2 2 6

2 8 | | 2 5

Project : Sm artC anton Dev Bo x | Rev i s i o n : * | Lab o : LSN

1.0 1.2 | E n g i neer: Dav i d | Sheet o f

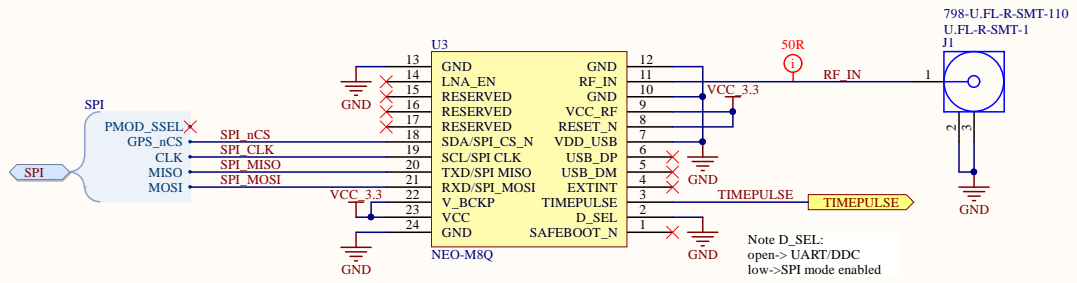
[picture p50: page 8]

1 4 | 11 GND 12 0 RF_IN

VCC_

Project : Sm artC anton Dev Bo x | Rev i s i o n : * | Lab o : LSN

1.0 1.2 | E n g i neer: Dav i d | Sheet o f

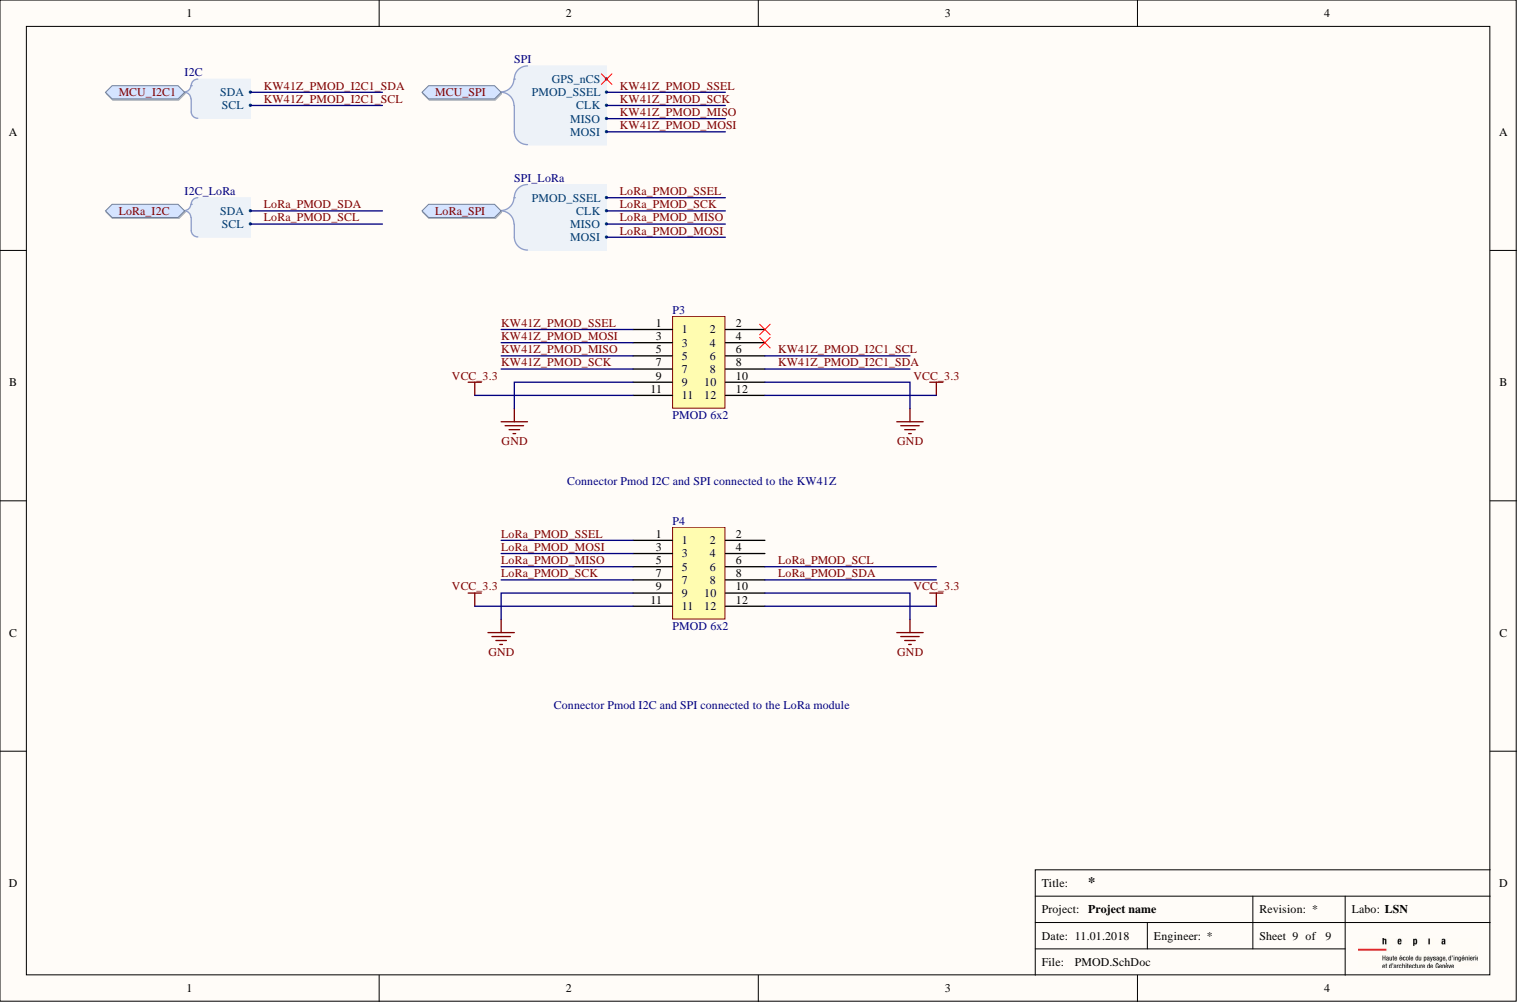
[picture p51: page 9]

Connector Pmod I2C and SPI connected to the KW41Z

Connector Pmod I2C and SPI connected to the LoRa module

Project: Project name | Revision: * | Labo: LSN

Engineer: *

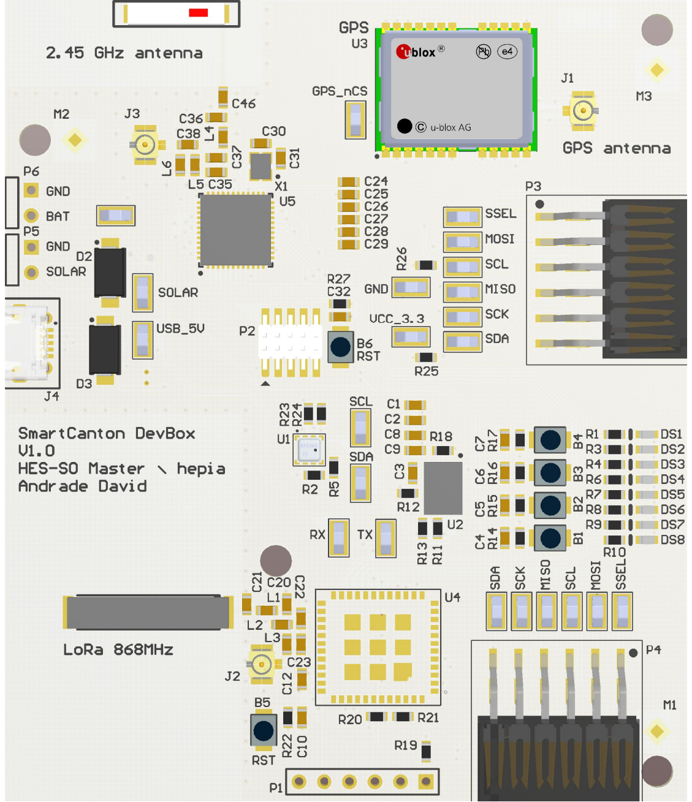
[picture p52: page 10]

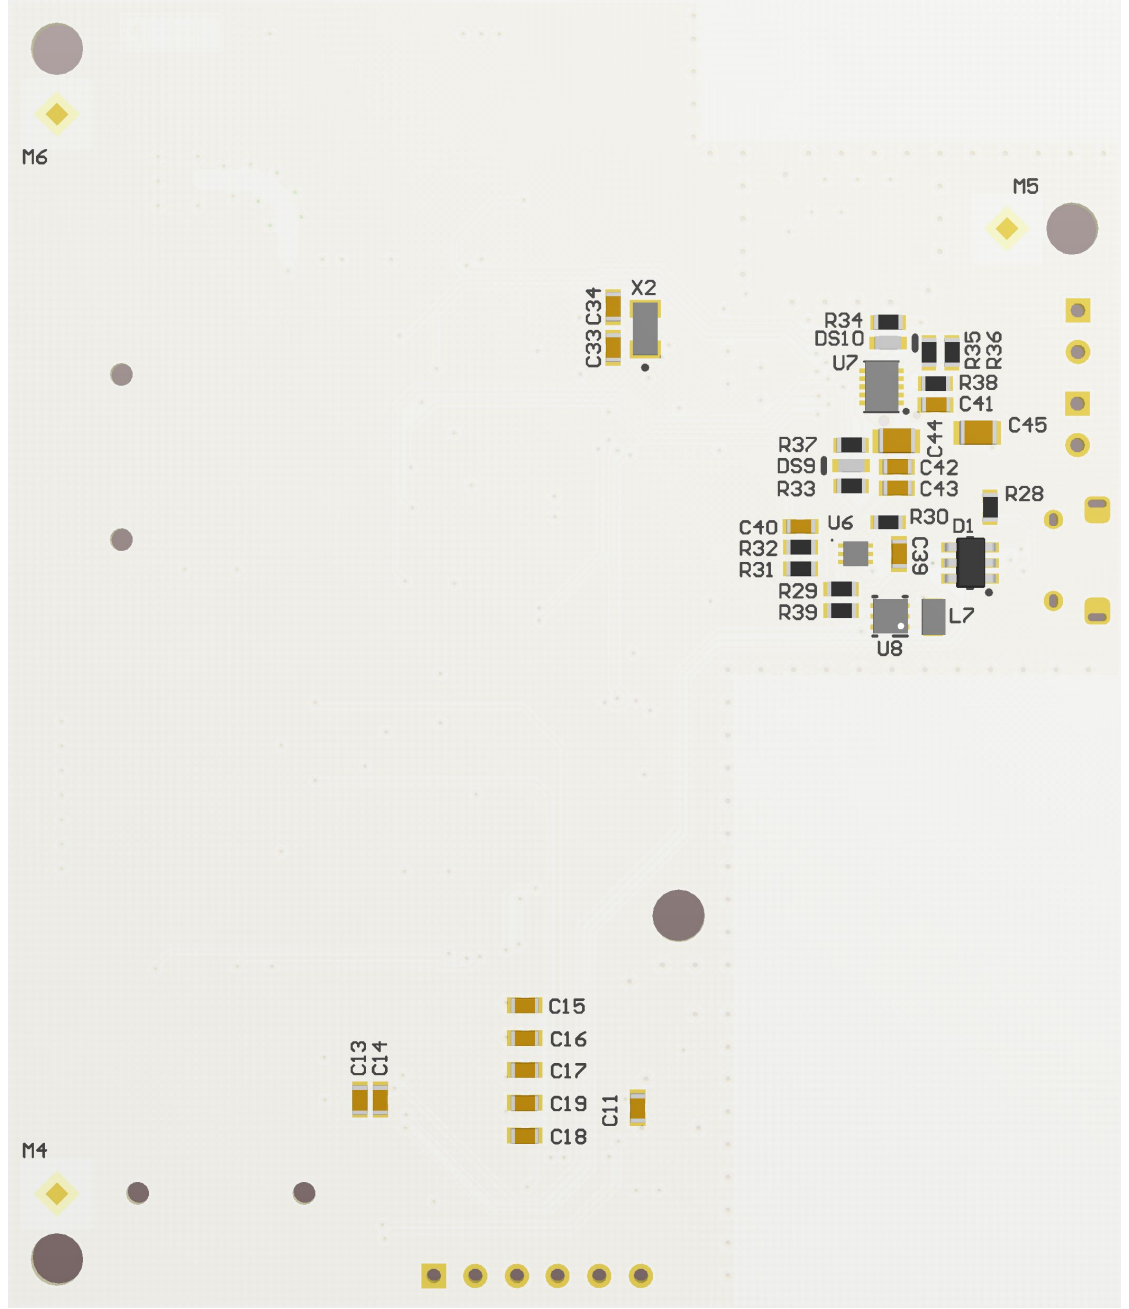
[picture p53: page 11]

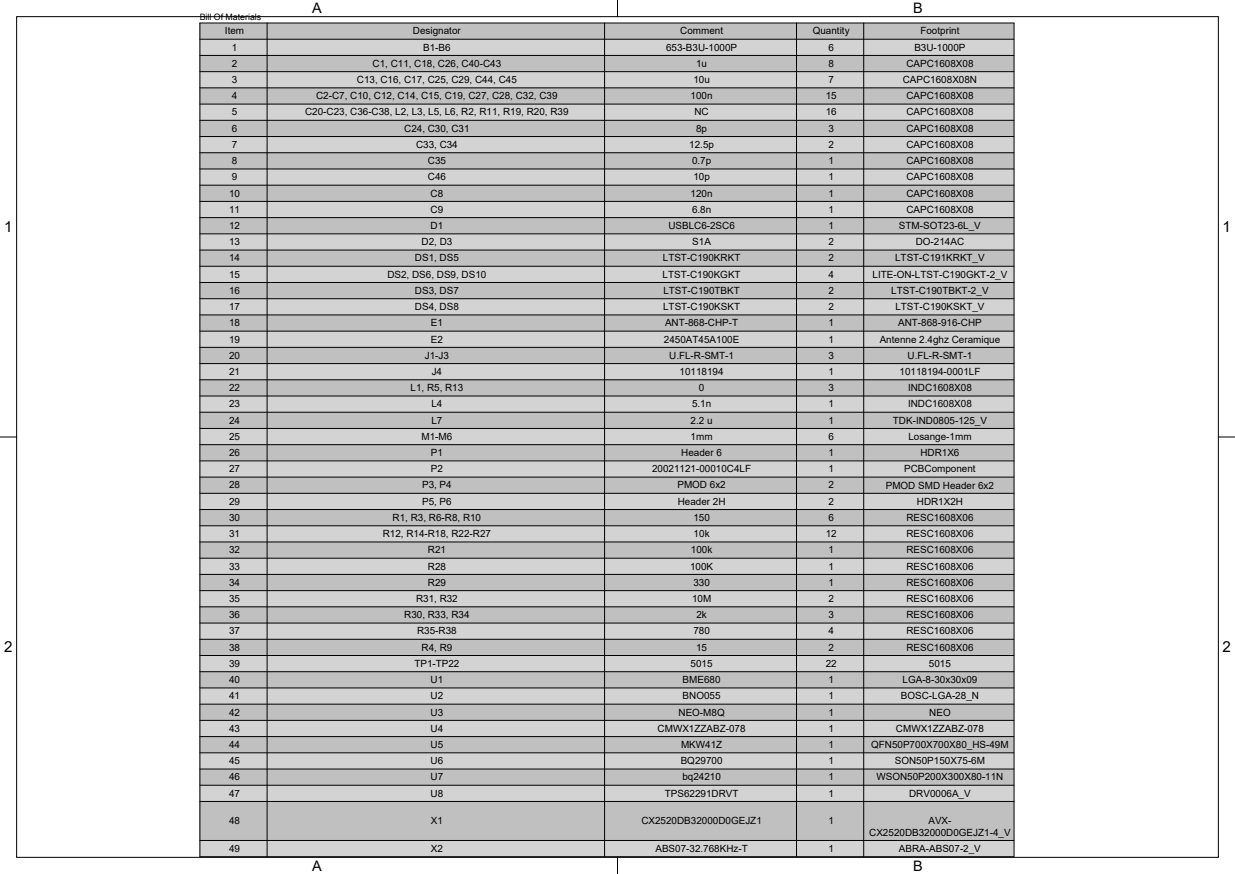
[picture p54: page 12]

Item123456789 | C13, C16, C17, C25, C29, C44, C45 | 10u | | CAPC1608X08N

Designator | Comment | | Footprint
B1-B6 | 653-B3U-1000P | Quantity 687 | B3U-1000P

C1, C11, C18, C26, C40-C43 | 1u | | CAPC1608X08

C2-C7, C10, C12, C14, C15, C19, C27, C28, C32, C39 | 100n | 15 | CAPC1608X08
C20-C23, C36-C38, L2, L3, L5, L6, R2, R11, R19, R20, R39 | NC | | CAPC1608X08

C24, C30, C31 | 8p | | CAPC1608X08
C33, C34 | 12.5p | | CAPC1608X08
C35 | 0.7p | | CAPC1608X08
C46 | 10p | | CAPC1608X08

10 | C8 | 120n | | CAPC1608X08
11 | C9 | 6.8n | | CAPC1608X08
12 | D1 | USBLC6-2SC6 | | STM-SOT23-6L_V

14 | DS1, DS5 | LTST-C190KRKT | | LTST-C191KRKT_V
15 | DS2, DS6, DS9, DS10 | LTST-C190KGKT | | LITE-ON-LTST-C190GKT-2_V
16 | DS3, DS7 | LTST-C190TBKT | | LTST-C190TBKT-2_V
17 | DS4, DS8 | LTST-C190KSKT | | LTST-C190KSKT_V
18 | E1 | ANT-868-CHP-T | | ANT-868-916-CHP
19 | E2 | 2450AT45A100E | | Antenne 2.4ghz Ceramique
20 | J1-J3 | U.FL-R-SMT-1 | | U.FL-R-SMT-1
21 | J4 | 10118194 0 | | 10118194-0001LF
22 | L1, R5, R13 | | | INDC1608X08
23 | L4 | 5.1n | | INDC1608X08
24 | L7 | 2.2 u | | TDK-IND0805-125_V
25 | M1-M6 | 1mm | | Losange-1mm
26 | P1 | Header 6 | | HDR1X6
27 | P2 | 20021121-00010C4LF | | PCBComponent
28 | P3, P4 | PMOD 6x2 | | PMOD SMD Header 6x2
29 | P5, P6 | Header 2H | | HDR1X2H
30 | R1, R3, R6-R8, R10 | 150 | | RESC1608X06
31 | R12, R14-R18, R22-R27 | 10k | | RESC1608X06
33 | R28 | 100K | 121112342 | RESC1608X06
32 | R21 | 100k | | RESC1608X06

34 | R29 | 330 | | RESC1608X06
35 | R31, R32 | 10M | | RESC1608X06
36 | R30, R33, R34 | 2k | | RESC1608X06
37 | R35-R38 | 780 | | RESC1608X06
38 | R4, R9 | 15 | | RESC1608X06
39 | TP1-TP22 | 5015 | | 5015
43 | U4 | CMWX1ZZABZ-078 | 221111111111 | CMWX1ZZABZ-078
40 | U1 | BME680 | | LGA-8-30x30x09
41 | U2 | BNO055 | | BOSC-LGA-28_N
42 | U3 | NEO-M8Q | | NEO

44 | U5 | MKW41Z | | QFN50P700X700X80_HS-49M
45 | U6 | BQ29700 | | SON50P150X75-6M
46 | U7 | bq24210 | | WSON50P200X300X80-11N
47 | U8 | TPS62291DRVT | | DRV0006A_V

X1 | CX2520DB32000D0GEJZ1 | | AVX-CX2520DB32000D0GEJZ1-4_V

X2 | ABS07-32.768KHz-T | | ABRA-ABS07-2_V


View from Top side (Scale 2.5)


View from Bottom side (Scale 2.5)

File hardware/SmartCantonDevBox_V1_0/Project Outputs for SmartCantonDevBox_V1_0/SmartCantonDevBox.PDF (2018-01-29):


Project: SmartCanton Dev Box | Revision: * | Labo: LSN

Date: 11.01.2018 | Engineer: David | Sheet 1 of 9


Using RISET = KISET /
IOUT and set IOUT = IC =
500mA gives RISET = 390
Ω closest 1% resistor.

Power Supply Title:

Project: SmartCanton Dev Box | Revision: * | Labo: LSN

Engineer: David


VCC_MCU VCC_ 3.3 G D | 3 2MHz Cry s tal O sci l lat o r X TA L E X TA L

Project : Sm artC anton Dev Bo x | Rev i s i o n : * | Lab o : LSN

1.0 1.2 | E n g i neer: Dav i d | Sheet o f


Condensators are temporarily replaced by 0OHm resistor

Project: SmartCanton Dev Box | Revision: * | Labo: LSN

Engineer: David


Notes Boot0 :
- if 0 => Flash program memory is
selected as boot area
- if 1 => System memory or
embedded SRAM is selected as boot
area (depends on BOOT1 value)

Notes for VREF+
1. VREF+ can be grounded when
ADC and DAC are not active.
2. VREF+ can be connected to a
separate voltage which is between
1.8V and VDD for better accuracy
on low-voltage inputs and outputs
of ADC and DAC.

SWDIO
nUSR_BTN2

GND 50 GND 51 GND 52 GND 53

for VDD_TCXO connection
Option1: Connect VDD_TCXO to VDD
Option2: Connect VDD_TCXO to PA12
to make sure MCU can control TCXO on/off

VDD_USB 4

VDD_RF 6


Antenna 868 MHZ with connectors

Condensators are temporarily replaced by 0OHm resistor

Project: SmartCanton Dev Box | Revision: * | Labo: LSN

Engineer: David


3.3 R1 2 1 0 k | 4 | 18 COM1 19 GND 2 7 COM2 2 6

2 8 | | 2 5

Project : Sm artC anton Dev Bo x | Rev i s i o n : * | Lab o : LSN

1.0 1.2 | E n g i neer: Dav i d | Sheet o f


1 4 | 11 GND 12 0 RF_IN

VCC_

Project : Sm artC anton Dev Bo x | Rev i s i o n : * | Lab o : LSN

1.0 1.2 | E n g i neer: Dav i d | Sheet o f


Connector Pmod I2C and SPI connected to the KW41Z

Connector Pmod I2C and SPI connected to the LoRa module

Project: Project name | Revision: * | Labo: LSN

Engineer: *




Item123456789 | C13, C16, C17, C25, C29, C44, C45 | 10u | | CAPC1608X08N

Designator | Comment | | Footprint
B1-B6 | 653-B3U-1000P | Quantity 687 | B3U-1000P

C1, C11, C18, C26, C40-C43 | 1u | | CAPC1608X08

C2-C7, C10, C12, C14, C15, C19, C27, C28, C32, C39 | 100n | 15 | CAPC1608X08
C20-C23, C36-C38, L2, L3, L5, L6, R2, R11, R19, R20, R39 | NC | | CAPC1608X08

C24, C30, C31 | 8p | | CAPC1608X08
C33, C34 | 12.5p | | CAPC1608X08
C35 | 0.7p | | CAPC1608X08
C46 | 10p | | CAPC1608X08

10 | C8 | 120n | | CAPC1608X08
11 | C9 | 6.8n | | CAPC1608X08
12 | D1 | USBLC6-2SC6 | | STM-SOT23-6L_V

14 | DS1, DS5 | LTST-C190KRKT | | LTST-C191KRKT_V
15 | DS2, DS6, DS9, DS10 | LTST-C190KGKT | | LITE-ON-LTST-C190GKT-2_V
16 | DS3, DS7 | LTST-C190TBKT | | LTST-C190TBKT-2_V
17 | DS4, DS8 | LTST-C190KSKT | | LTST-C190KSKT_V
18 | E1 | ANT-868-CHP-T | | ANT-868-916-CHP
19 | E2 | 2450AT45A100E | | Antenne 2.4ghz Ceramique
20 | J1-J3 | U.FL-R-SMT-1 | | U.FL-R-SMT-1
21 | J4 | 10118194 0 | | 10118194-0001LF
22 | L1, R5, R13 | | | INDC1608X08
23 | L4 | 5.1n | | INDC1608X08
24 | L7 | 2.2 u | | TDK-IND0805-125_V
25 | M1-M6 | 1mm | | Losange-1mm
26 | P1 | Header 6 | | HDR1X6
27 | P2 | 20021121-00010C4LF | | PCBComponent
28 | P3, P4 | PMOD 6x2 | | PMOD SMD Header 6x2
29 | P5, P6 | Header 2H | | HDR1X2H
30 | R1, R3, R6-R8, R10 | 150 | | RESC1608X06
31 | R12, R14-R18, R22-R27 | 10k | | RESC1608X06
33 | R28 | 100K | 121112342 | RESC1608X06
32 | R21 | 100k | | RESC1608X06

34 | R29 | 330 | | RESC1608X06
35 | R31, R32 | 10M | | RESC1608X06
36 | R30, R33, R34 | 2k | | RESC1608X06
37 | R35-R38 | 780 | | RESC1608X06
38 | R4, R9 | 15 | | RESC1608X06
39 | TP1-TP22 | 5015 | | 5015
43 | U4 | CMWX1ZZABZ-078 | 221111111111 | CMWX1ZZABZ-078
40 | U1 | BME680 | | LGA-8-30x30x09
41 | U2 | BNO055 | | BOSC-LGA-28_N
42 | U3 | NEO-M8Q | | NEO

44 | U5 | MKW41Z | | QFN50P700X700X80_HS-49M
45 | U6 | BQ29700 | | SON50P150X75-6M
46 | U7 | bq24210 | | WSON50P200X300X80-11N
47 | U8 | TPS62291DRVT | | DRV0006A_V

X1 | CX2520DB32000D0GEJZ1 | | AVX-CX2520DB32000D0GEJZ1-4_V

X2 | ABS07-32.768KHz-T | | ABRA-ABS07-2_V


View from Top side (Scale 2.5)


View from Bottom side (Scale 2.5)



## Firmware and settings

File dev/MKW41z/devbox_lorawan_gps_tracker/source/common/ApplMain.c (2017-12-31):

/*!
* Copyright (c) 2014, Freescale Semiconductor, Inc.
* Copyright 2016-2017 NXP
*
* \file
* This is a source file for the main application.
*
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
* o Neither the name of Freescale Semiconductor, Inc. nor the names of its
*   contributors may be used to endorse or promote products derived from this
*   software without specific prior written permission.
*
* THIS SOFTWARE IS PROVIDED BY THE COPYRIGHT HOLDERS AND CONTRIBUTORS "AS IS" AND
* ANY EXPRESS OR IMPLIED WARRANTIES, INCLUDING, BUT NOT LIMITED TO, THE IMPLIED
* WARRANTIES OF MERCHANTABILITY AND FITNESS FOR A PARTICULAR PURPOSE ARE
* DISCLAIMED. IN NO EVENT SHALL THE COPYRIGHT HOLDER OR CONTRIBUTORS BE LIABLE FOR
* ANY DIRECT, INDIRECT, INCIDENTAL, SPECIAL, EXEMPLARY, OR CONSEQUENTIAL DAMAGES
* (INCLUDING, BUT NOT LIMITED TO, PROCUREMENT OF SUBSTITUTE GOODS OR SERVICES;
* LOSS OF USE, DATA, OR PROFITS; OR BUSINESS INTERRUPTION) HOWEVER CAUSED AND ON
* ANY THEORY OF LIABILITY, WHETHER IN CONTRACT, STRICT LIABILITY, OR TORT
* (INCLUDING NEGLIGENCE OR OTHERWISE) ARISING IN ANY WAY OUT OF THE USE OF THIS
* SOFTWARE, EVEN IF ADVISED OF THE POSSIBILITY OF SUCH DAMAGE.
*/

/************************************************************************************
*************************************************************************************
* Include
*************************************************************************************
************************************************************************************/
/* Drv */
#include "LED.h"
#include "Keyboard.h"

/* Fwk */
#include "fsl_os_abstraction.h"
#include "MemManager.h"
#include "TimersManager.h"
#include "RNG_Interface.h"
#include "Messaging.h"
#include "Flash_Adapter.h"
#include "SecLib.h"
#include "Panic.h"

#if gFsciIncluded_c    
#include "FsciInterface.h"
#include "FsciCommands.h"
#endif

/* KSDK */
#include "board.h"

/* Bluetooth Low Energy */
#include "gatt_interface.h"
#include "gatt_server_interface.h"
#include "gatt_client_interface.h"
#include "gap_interface.h"
#include "ble_init.h"
#include "ble_config.h"
#include "l2ca_cb_interface.h"

#ifdef cPWR_UsePowerDownMode
#if (cPWR_UsePowerDownMode)
#include "PWR_Interface.h"
#endif
#endif

#ifdef FSL_RTOS_FREE_RTOS
#include "FreeRTOSConfig.h"
#endif

#include "ApplMain.h"

#include "pin_mux.h"
#include "dev_box_app_task.h"
#include "lorawan_controller_task.h"
#include "bno055_task.h"
#include "bme680_task.h"
#include "gps_task.h"


#if gAppUseNvm_d
/* include NVM interface */
#include "NVM_Interface.h"
#endif
/************************************************************************************
*************************************************************************************
* Private macros
*************************************************************************************
************************************************************************************/

/* NVM Dataset identifiers */
#if gAppUseNvm_d
#define nvmId_BondingHeaderId_c          0x4011
#define nvmId_BondingDataDynamicId_c     0x4012
#define nvmId_BondingDataStaticId_c      0x4013
#define nvmId_BondingDataDeviceInfoId_c  0x4014
#define nvmId_BondingDataDescriptorId_c  0x4015
#endif

/* Application Events */
#define gAppEvtMsgFromHostStack_c       (1 << 0)
#define gAppEvtAppCallback_c            (1 << 1)

#ifdef FSL_RTOS_FREE_RTOS
    #if (configUSE_IDLE_HOOK)
        #define mAppIdleHook_c 1
    #endif
#endif

#ifndef mAppIdleHook_c
#define mAppIdleHook_c 0
#endif

/************************************************************************************
*************************************************************************************
* Private type definitions
*************************************************************************************
************************************************************************************/
/* Host to Application Messages Types */
typedef enum {
    gAppGapGenericMsg_c = 0,
    gAppGapConnectionMsg_c,
    gAppGapAdvertisementMsg_c,
    gAppGapScanMsg_c,
    gAppGattServerMsg_c,
    gAppGattClientProcedureMsg_c,
    gAppGattClientNotificationMsg_c,
    gAppGattClientIndicationMsg_c,
    gAppL2caLeDataMsg_c,
    gAppL2caLeControlMsg_c,
}appHostMsgType_tag;

typedef uint8_t appHostMsgType_t;

/* Host to Application Connection Message */
typedef struct connectionMsg_tag{
    deviceId_t              deviceId;
    gapConnectionEvent_t    connEvent;
}connectionMsg_t;

/* Host to Application GATT Server Message */
typedef struct gattServerMsg_tag{
    deviceId_t          deviceId;
    gattServerEvent_t   serverEvent;
}gattServerMsg_t;

/* Host to Application GATT Client Procedure Message */
typedef struct gattClientProcMsg_tag{
    deviceId_t              deviceId;
    gattProcedureType_t     procedureType;
    gattProcedureResult_t   procedureResult;
    bleResult_t             error;
}gattClientProcMsg_t;

/* Host to Application GATT Client Notification/Indication Message */
typedef struct gattClientNotifIndMsg_tag{
    uint8_t*    aValue;
    uint16_t    characteristicValueHandle;
    uint16_t    valueLength;
    deviceId_t  deviceId;
}gattClientNotifIndMsg_t;

/* L2ca to Application Data Message */
typedef struct l2caLeCbDataMsg_tag{
    deviceId_t  deviceId;
    uint16_t    lePsm;
    uint16_t    packetLength;
    uint8_t     aPacket[0];
}l2caLeCbDataMsg_t;

/* L2ca to Application Control Message */
typedef struct l2caLeCbControlMsg_tag{
    l2capControlMessageType_t   messageType;
    uint16_t                    padding;
    uint8_t                     aMessage[0];
}l2caLeCbControlMsg_t;

typedef struct appMsgFromHost_tag{
    appHostMsgType_t    msgType;
    union {
        gapGenericEvent_t       genericMsg;
        gapAdvertisingEvent_t   advMsg;
        connectionMsg_t         connMsg;
        gapScanningEvent_t      scanMsg;
        gattServerMsg_t         gattServerMsg;
        gattClientProcMsg_t     gattClientProcMsg;
        gattClientNotifIndMsg_t gattClientNotifIndMsg;
        l2caLeCbDataMsg_t       l2caLeCbDataMsg;
        l2caLeCbControlMsg_t    l2caLeCbControlMsg;
    } msgData;
}appMsgFromHost_t;

typedef struct appMsgCallback_tag{
    appCallbackHandler_t   handler;
    appCallbackParam_t     param;
}appMsgCallback_t;
/************************************************************************************
*************************************************************************************
* Private prototypes
*************************************************************************************
************************************************************************************/
#if (cPWR_UsePowerDownMode || gAppUseNvm_d)
#if (mAppIdleHook_c)
    #define AppIdle_TaskInit()
    #define App_Idle_Task()
#else
    static osaStatus_t AppIdle_TaskInit(void);
    static void App_Idle_Task(osaTaskParam_t argument);
#endif
#endif

#if gKeyBoardSupported_d && (gKBD_KeysCount_c > 0)   
static void App_KeyboardCallBack(uint8_t events);
#endif

static void App_Thread (uint32_t param);
static void App_HandleHostMessageInput(appMsgFromHost_t* pMsg);
static void App_GenericCallback (gapGenericEvent_t* pGenericEvent);
static void App_ConnectionCallback (deviceId_t peerDeviceId, gapConnectionEvent_t* pConnectionEvent);
static void App_AdvertisingCallback (gapAdvertisingEvent_t* pAdvertisingEvent);
static void App_ScanningCallback (gapScanningEvent_t* pAdvertisingEvent);
static void App_GattServerCallback (deviceId_t peerDeviceId, gattServerEvent_t* pServerEvent);
static void App_GattClientProcedureCallback
(
    deviceId_t              deviceId,
    gattProcedureType_t     procedureType,
    gattProcedureResult_t   procedureResult,
    bleResult_t             error
);
static void App_GattClientNotificationCallback
(
    deviceId_t      deviceId,
    uint16_t        characteristicValueHandle,
    uint8_t*        aValue,
    uint16_t        valueLength
);
static void App_GattClientIndicationCallback
(
    deviceId_t      deviceId,
    uint16_t        characteristicValueHandle,
    uint8_t*        aValue,
    uint16_t        valueLength
);

static void App_L2caLeDataCallback
(
    deviceId_t deviceId,
    uint16_t   lePsm,
    uint8_t* pPacket,
    uint16_t packetLength
);

static void App_L2caLeControlCallback
(
    l2capControlMessageType_t  messageType,
    void* pMessage
);

#if !gUseHciTransportDownward_d
static void BLE_SignalFromISRCallback(void);
#endif

/*! *********************************************************************************
*************************************************************************************
* Public prototypes
*************************************************************************************
********************************************************************************** */
extern void BleApp_Init(void);
extern void BleApp_HandleKeys(key_event_t events);

#if gUseHciTransportUpward_d
#define BleApp_GenericCallback(param)
#else
extern void BleApp_GenericCallback (gapGenericEvent_t* pGenericEvent);
#endif

#if !gUseHciTransportDownward_d
extern void (*pfBLE_SignalFromISR)(void);
#endif /* gUseHciTransportDownward_d */

/************************************************************************************
*************************************************************************************
* Private memory declarations
*************************************************************************************
************************************************************************************/
#if (cPWR_UsePowerDownMode || gAppUseNvm_d)
#if (!mAppIdleHook_c)
OSA_TASK_DEFINE( App_Idle_Task, gAppIdleTaskPriority_c, 1, gAppIdleTaskStackSize_c, FALSE );
osaTaskId_t gAppIdleTaskId = 0;
#endif
#endif  /* cPWR_UsePowerDownMode */

#if gAppUseNvm_d
static bleBondIdentityHeaderBlob_t*  aBondingHeader[gMaxBondedDevices_c];
static bleBondDataDynamicBlob_t*     aBondingDataDynamic[gMaxBondedDevices_c];
static bleBondDataStaticBlob_t*      aBondingDataStatic[gMaxBondedDevices_c];
static bleBondDataDeviceInfoBlob_t*  aBondingDataDeviceInfo[gMaxBondedDevices_c];
static bleBondDataDescriptorBlob_t* aBondingDataDescriptor[gMaxBondedDevices_c * gcGapMaximumSavedCccds_c];

NVM_RegisterDataSet(aBondingHeader, gMaxBondedDevices_c, gBleBondIdentityHeaderSize_c, nvmId_BondingHeaderId_c, gNVM_NotMirroredInRamAutoRestore_c);
NVM_RegisterDataSet(aBondingDataDynamic, gMaxBondedDevices_c, gBleBondDataDynamicSize_c, nvmId_BondingDataDynamicId_c, gNVM_NotMirroredInRamAutoRestore_c);
NVM_RegisterDataSet(aBondingDataStatic, gMaxBondedDevices_c, gBleBondDataStaticSize_c, nvmId_BondingDataStaticId_c, gNVM_NotMirroredInRamAutoRestore_c);
NVM_RegisterDataSet(aBondingDataDeviceInfo, gMaxBondedDevices_c, gBleBondDataDeviceInfoSize_c, nvmId_BondingDataDeviceInfoId_c, gNVM_NotMirroredInRamAutoRestore_c);
NVM_RegisterDataSet(aBondingDataDescriptor, gMaxBondedDevices_c * gcGapMaximumSavedCccds_c, gBleBondDataDescriptorSize_c, nvmId_BondingDataDescriptorId_c, gNVM_NotMirroredInRamAutoRestore_c);
#else
static bleBondDataBlob_t          maBondDataBlobs[gMaxBondedDevices_c] = {{{{0}}}};
#endif

static osaEventId_t  mAppEvent;

/* Application input queues */
static anchor_t mHostAppInputQueue;
static anchor_t mAppCbInputQueue;

static uint8_t platformInitialized = 0;

static gapGenericCallback_t pfGenericCallback = NULL;
static gapAdvertisingCallback_t pfAdvCallback = NULL;
static gapScanningCallback_t pfScanCallback = NULL;
static gapConnectionCallback_t  pfConnCallback = NULL;
static gattServerCallback_t pfGattServerCallback = NULL;
static gattClientProcedureCallback_t pfGattClientProcCallback = NULL;
static gattClientNotificationCallback_t pfGattClientNotifCallback = NULL;
static gattClientNotificationCallback_t pfGattClientIndCallback = NULL;
static l2caLeCbDataCallback_t           pfL2caLeCbDataCallback = NULL;
static l2caLeCbControlCallback_t        pfL2caLeCbControlCallback = NULL;

/************************************************************************************
*************************************************************************************
* Public memory declarations
*************************************************************************************
************************************************************************************/
#if gRNG_HWSupport_d == gRNG_NoHWSupport_d
extern uint32_t mRandomNumber;
#endif
extern const uint8_t gUseRtos_c;

/************************************************************************************
*************************************************************************************
* Public functions
*************************************************************************************
************************************************************************************/

/*! *********************************************************************************
* \brief  This is the first task created by the OS. This task will initialize 
*         the system
*
* \param[in]  param
*
********************************************************************************** */
void main_task(uint32_t param)
{  
    if (!platformInitialized)
    {
        uint8_t pseudoRNGSeed[20] = {0};
		
        platformInitialized = 1;
        
        hardware_init();
        
        BOARD_InitPins();

        /* Framework init */
        MEM_Init();
        TMR_Init();       
        LED_Init();
        SecLib_Init();
        
        RNG_Init();   
        RNG_GetRandomNo((uint32_t*)(&(pseudoRNGSeed[0])));
        RNG_GetRandomNo((uint32_t*)(&(pseudoRNGSeed[4])));
        RNG_GetRandomNo((uint32_t*)(&(pseudoRNGSeed[8])));
        RNG_GetRandomNo((uint32_t*)(&(pseudoRNGSeed[12])));
        RNG_GetRandomNo((uint32_t*)(&(pseudoRNGSeed[16])));
        RNG_SetPseudoRandomNoSeed(pseudoRNGSeed);
        
#if gKeyBoardSupported_d && (gKBD_KeysCount_c > 0)        
        KBD_Init(App_KeyboardCallBack);
#endif

#if gAppUseNvm_d        
        /* Initialize NV module */
        NvModuleInit();
#endif
        
#if !gUseHciTransportDownward_d
        pfBLE_SignalFromISR = BLE_SignalFromISRCallback;        
#endif /* !gUseHciTransportDownward_d */
        
#if (cPWR_UsePowerDownMode || gAppUseNvm_d)
#if (!mAppIdleHook_c)
        AppIdle_TaskInit();
#endif
#endif
#if (cPWR_UsePowerDownMode)
        PWR_Init();
        PWR_DisallowDeviceToSleep();
#else    
        Led1Off();
        Led2Off();
        Led3Off();
        Led4Off();
#endif    
       
        /* Initialize peripheral drivers specific to the application */
        BleApp_Init();

        /* Initialize Serial Task */
        SerialManager_Init();

        /**
         * Erase all NVM memory
         * To be used only when the CCCD are modified to restore a clean state for each device stored
         */
//        for (uint8_t var = 0; var < gMaxBondedDevices_c; var++) {
//        	App_NvmErase(var);
//		}

        /* Initialize Lorawan Controller Task */
		if (osaStatus_Success != LorawanController_TaskInit())
		{
		   panic(0,0,0,0);
		   return;
		}

		if (osaStatus_Success != DevBoxApp_TaskInit())
		{
		   panic(0,0,0,0);
		   return;
		}

        /**
		 * Init I2C used by BNO055 and BME680. Both Tasks using these peripherals needs
		 * an handle to the same I2C.
		 */
		BOARD_InitI2CEmbeddedSensors();

		if (osaStatus_Success != Bno055_TaskInit(BOARD_GetI2CEmbeddedSensorsHandle()))
		{
		   panic(0,0,0,0);
		   return;
		}

		if (osaStatus_Success != Bme680_TaskInit(BOARD_GetI2CEmbeddedSensorsHandle()))
		{
		   panic(0,0,0,0);
		   return;
		}

		if (osaStatus_Success != Gps_TaskInit())
		{
		   panic(0,0,0,0);
		   return;
		}

        /* Create application event */
        mAppEvent = OSA_EventCreate(TRUE);
        if( NULL == mAppEvent )
        {
            panic(0,0,0,0);
            return;
        }

        /* Prepare application input queue.*/
        MSG_InitQueue(&mHostAppInputQueue);

        /* Prepare callback input queue.*/
        MSG_InitQueue(&mAppCbInputQueue);

        /* BLE Host Stack Init */
        if (Ble_Initialize(App_GenericCallback) != gBleSuccess_c)
        {
            panic(0,0,0,0);
            return;
        }
    }
    
    /* Call application task */
    App_Thread( param );
}

/*! *********************************************************************************
* \brief  This function represents the Application task. 
*         This task reuses the stack alocated for the MainThread.
*         This function is called to process all events for the task. Events 
*         include timers, messages and any other user defined events.
* \param[in]  argument
*
********************************************************************************** */
void App_Thread (uint32_t param)
{
    osaEventFlags_t event;
    
    while(1)
    { 
        OSA_EventWait(mAppEvent, osaEventFlagsAll_c, FALSE, osaWaitForever_c , &event);
        
        /* Dequeue the host to app message */
        if (event & gAppEvtMsgFromHostStack_c)
        {
            /* Pointer for storing the messages from host. */
            appMsgFromHost_t *pMsgIn = NULL;  
            
            /* Check for existing messages in queue */
            while(MSG_Pending(&mHostAppInputQueue))
            {
                pMsgIn = MSG_DeQueue(&mHostAppInputQueue);
            
                if (pMsgIn)
                {
                    /* Process it */
                    App_HandleHostMessageInput(pMsgIn);
                    
                    /* Messages must always be freed. */
                    MSG_Free(pMsgIn);
                    pMsgIn = NULL;
                }
            }
        }
        
        /* Dequeue the callback message */
        if (event & gAppEvtAppCallback_c)
        {
            /* Pointer for storing the callback messages. */
            appMsgCallback_t *pMsgIn = NULL;  
            
            /* Check for existing messages in queue */
            while(MSG_Pending(&mAppCbInputQueue))
            {
                pMsgIn = MSG_DeQueue(&mAppCbInputQueue);
            
                if (pMsgIn)
                {
                    /* Execute callback handler */
                    if (pMsgIn->handler)
                    {
                        pMsgIn->handler (pMsgIn->param);
                    }
                    
                    /* Messages must always be freed. */
                    MSG_Free(pMsgIn);
                    pMsgIn = NULL;
                }
            }
        }

        /* For BareMetal break the while(1) after 1 run */
        if( gUseRtos_c == 0 )
        {
            break;
        }
    }
}

#if (cPWR_UsePowerDownMode)

static void App_Idle(void)
{
    PWRLib_WakeupReason_t wakeupReason;
    
    if( PWR_CheckIfDeviceCanGoToSleep() )
    {
        /* Enter Low Power */
        wakeupReason = PWR_EnterLowPower();

#if gFSCI_IncludeLpmCommands_c
        /* Send Wake Up indication to FSCI */
        FSCI_SendWakeUpIndication();
#endif

#if gKBD_KeysCount_c > 0      
        /* Woke up on Keyboard Press */
        if(wakeupReason.Bits.FromKeyBoard)
        {
            KBD_SwitchPressedOnWakeUp();
            PWR_DisallowDeviceToSleep();
        }
#endif   
    }
    else
    {
        /* Enter MCU Sleep */
        PWR_EnterSleep(); 
    }
}

#endif /* cPWR_UsePowerDownMode */

#if (mAppIdleHook_c)

void vApplicationIdleHook(void)
{
#if (gAppUseNvm_d)
    NvIdle();
#endif
#if (cPWR_UsePowerDownMode)
    App_Idle();  
#endif  
}

#else /* mAppIdleHook_c */

#if (cPWR_UsePowerDownMode || gAppUseNvm_d)
static void App_Idle_Task(osaTaskParam_t argument)
{
    while(1)
    {   
#if gAppUseNvm_d
        NvIdle();
#endif
        
#if (cPWR_UsePowerDownMode)
        App_Idle();
#endif
 
        /* For BareMetal break the while(1) after 1 run */
        if (gUseRtos_c == 0)
        {
            break;
        }
    }
}

static osaStatus_t AppIdle_TaskInit(void)
{	     
    if(gAppIdleTaskId)
    {      
        return osaStatus_Error;
    }
   
    /* Task creation */
    gAppIdleTaskId = OSA_TaskCreate(OSA_TASK(App_Idle_Task), NULL);
    
    if( NULL == gAppIdleTaskId )
    {
        panic(0,0,0,0);
        return osaStatus_Error;
    }

    return osaStatus_Success;
}
#endif /* cPWR_UsePowerDownMode */

#endif /* mAppIdleHook_c */

bleResult_t App_Connect(
    gapConnectionRequestParameters_t*   pParameters,
    gapConnectionCallback_t             connCallback
)
{
    pfConnCallback = connCallback;
    
    return Gap_Connect(pParameters, App_ConnectionCallback);
}

bleResult_t App_StartAdvertising(
    gapAdvertisingCallback_t    advertisingCallback,
    gapConnectionCallback_t     connectionCallback
)
{
    pfAdvCallback = advertisingCallback;
    pfConnCallback = connectionCallback;
    
    return Gap_StartAdvertising(App_AdvertisingCallback, App_ConnectionCallback);
}

bleResult_t App_StartScanning(
    gapScanningParameters_t*    pScanningParameters,
    gapScanningCallback_t       scanningCallback,
    bool_t                      enableFilterDuplicates
)
{
    pfScanCallback = scanningCallback;
    
    return Gap_StartScanning(pScanningParameters, App_ScanningCallback,  enableFilterDuplicates);
}

bleResult_t App_RegisterGattServerCallback(gattServerCallback_t  serverCallback)
{
    pfGattServerCallback = serverCallback;
    
    return GattServer_RegisterCallback(App_GattServerCallback);
}

bleResult_t App_RegisterGattClientProcedureCallback(gattClientProcedureCallback_t  callback)
{
    pfGattClientProcCallback = callback;

    return GattClient_RegisterProcedureCallback(App_GattClientProcedureCallback);
}

bleResult_t App_RegisterGattClientNotificationCallback(gattClientNotificationCallback_t  callback)
{
    pfGattClientNotifCallback = callback;

    return GattClient_RegisterNotificationCallback(App_GattClientNotificationCallback);
}

bleResult_t App_RegisterGattClientIndicationCallback(gattClientIndicationCallback_t  callback)
{
    pfGattClientIndCallback = callback;

    return GattClient_RegisterIndicationCallback(App_GattClientIndicationCallback);
}
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

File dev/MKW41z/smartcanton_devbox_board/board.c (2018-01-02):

/**
 * @file    board.c
 * @author  Da Silva Andrade David
 * @version V1.0
 * @date    02-01-2018
 * @brief	Functions and definitions hard on the SmartCanton DevBox board.
 */

/************************************************************************************
 *************************************************************************************
 * Include
 *************************************************************************************
 ************************************************************************************/
#include "EmbeddedTypes.h"
#include "fsl_device_registers.h"
#include "fsl_common.h"
#include "fsl_clock.h"
#include "fsl_smc.h"
#include "fsl_debug_console.h"
#include "fsl_pmc.h"
#include "fsl_port.h"
#include "fsl_adc16.h"
#include "board.h"
#include "pin_mux.h"
#include "GPIO_Adapter.h"
#include "RNG_Interface.h"
#include "Flash_Adapter.h"
#include "clock_config.h"

#if cPWR_UsePowerDownMode
#include "PWR_Interface.h"
#endif

#if gDCDC_Enabled_d
#include "DCDC.h"
#endif

#include "FunctionLib.h"
#include "Keyboard.h"

/*******************************************************************************
 * Definitions
 ******************************************************************************/
/*! @brief Clock configuration structure. */
typedef struct _clock_config
{
	mcg_config_t mcgConfig; /*!< MCG configuration.      */
	sim_clock_config_t simConfig; /*!< SIM configuration.      */
	osc_config_t oscConfig; /*!< OSC configuration.      */
	uint32_t coreClock; /*!< core clock frequency.   */
} clock_config_t;

typedef struct gpioPinId_tag
{
	gpioPort_t gpioPort;
	uint8_t gpioPin;
} gpioPinId_t;

/************************************************************************************
 *************************************************************************************
 * Private type definitions and macros
 *************************************************************************************
 ************************************************************************************/
#define ADCDAC_LDO_OVERRIDE           (1)
#define ADC16_INSTANCE                (0)   /* ADC instance */
#define ADC16_CHN_GROUP               (0)   /* ADC group configuration selection */

#define ADC16_BATLVL_DCDC_CHN         (23) /* Battery intern channel */
#define ADC16_BATLVL_CHN              (4) /* External battery */
#define ADC16_BL_LOWER_LIMIT          (0) /* min percentage of battery charge */
#define ADC16_BL_UPPER_LIMIT          (100) /* max percentage of battery charge */
#define ADC16_BL_DYNAMIC_RANGE        (ADC16_BL_UPPER_LIMIT - ADC16_BL_LOWER_LIMIT) /* Range = [ADC16_HB_LOWER_LIMIT .. ADC16_HB_LOWER_LIMIT + ADC16_HB_DYNAMIC_RANGE] */

#define ADC16_TEMP_SENSOR_CHN         (26) /* ADC channel of the Temperature Sensor */
#define ADC16_BANDGAP_CHN             (27) /* ADC channel of BANDGAP Voltage reference */

#define MIN_VOLT_BUCK                 (180)
#define MAX_VOLT_BUCK                 (310)
#define MIN_VOLT_LI_ION_BAT           (330)
#define MAX_VOLT_LI_ION_BAT           (400)
#define VREF_REG           			  (330)
#define FULL_BAT                      (100)
#define EMPTY_BAT                     (0)

#define ADCR_VDD                      (4095U)     /* Maximum value when use 12b resolution */
#define V_BG                          (1000U)     /* BANDGAP voltage in mV (trim to 1.0V) */
#define V_TEMP25                      (716U)      /* Typical converted value at 25 oC in mV */
#define M                             (1620U)     /* Typical slope:uV/oC */
#define STANDARD_TEMP                 (25)
#define mNoOfPinsDisabledInLowPower_c (19)

/************************************************************************************
 *************************************************************************************
 * Private memory declarations
 *************************************************************************************
 ************************************************************************************/
uint32_t offsetVdd = 0;
static uint32_t adcValue = 0; /* ADC value */
static adc16_config_t adcUserConfig; /* structure for user config */

#if gDCDC_Enabled_d == 1
const dcdcConfig_t mDcdcDefaultConfig =
{
#if APP_DCDC_MODE == gDCDC_Mode_Buck_c
	.vbatMin = 1800,
	.vbatMax = 4200,
#elif APP_DCDC_MODE == gDCDC_Mode_Boost_c
	.vbatMin = 900,
	.vbatMax = 1800,
#endif  
	.dcdcMode = APP_DCDC_MODE,
	.vBatMonitorIntervalMs = APP_DCDC_VBAT_MONITOR_INTERVAL,
	.pfDCDCAppCallback = NULL, /* .pfDCDCAppCallback = DCDCCallback, */
	.dcdcMcuVOutputTargetVal = gDCDC_McuV_OutputTargetVal_1_500_c,
	.dcdc1P8OutputTargetVal = gDCDC_1P8OutputTargetVal_1_800_c
};
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

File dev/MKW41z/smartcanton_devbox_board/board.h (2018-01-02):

/**
 * @file    board.h
 * @author  Da Silva Andrade David
 * @version V1.0
 * @date    02-01-2018
 * @brief	Functions and definitions hard on the SmartCanton DevBox board.
 */

#ifndef _BOARD_H_
#define _BOARD_H_

#include "fsl_gpio.h"
#include "fsl_i2c_freertos.h"
#include "fsl_dspi_freertos.h"

/*******************************************************************************
 * Definitions
 ******************************************************************************/

/* The board name */
#define MANUFACTURER_NAME               "NXP"
#define BOARD_NAME                      "SmartCantonDevBox"

#define BOARD_XTAL0_CLK_HZ    32000000U
#define BOARD_XTAL32K_CLK_HZ  32768U

#define CORE_CLOCK_FREQ 20970000U

/* Connectivity */
#ifndef APP_SERIAL_INTERFACE_TYPE
#define APP_SERIAL_INTERFACE_TYPE (gSerialMgrLpuart_c)
#endif

#ifndef APP_SERIAL_INTERFACE_INSTANCE
#define APP_SERIAL_INTERFACE_INSTANCE (0)
#endif

#ifndef APP_SERIAL_INTERFACE_SPEED
#define APP_SERIAL_INTERFACE_SPEED (115200)
#endif

/* EEPROM type used */
#ifndef gEepromType_d
#define gEepromType_d gEepromDevice_AT45DB041E_c
#endif

/* DCDC driver default mode */
#ifndef APP_DCDC_MODE
#define APP_DCDC_MODE    (gDCDC_Mode_Buck_c)
#endif

/* Vbat monitor Interval in Ms */
#ifndef APP_DCDC_VBAT_MONITOR_INTERVAL
#define APP_DCDC_VBAT_MONITOR_INTERVAL    (50000)
#endif

/* 1<<x to enable PINx as wakup source in LLWU */
#define BOARD_LLWU_PIN_ENABLE_BITMAP ( 1<<12 | 1<<13 )

/*! @brief TSI electrodes count */
#ifndef gKBD_TsiElectdCount_c
#define gKBD_TsiElectdCount_c 0U
#endif
/*! @brief TSI electrodes mapping: 1<<x to mark KBD pin as TSI */
#define gKBD_SwTypeMapping_d ( 1<<0 | 1<<3 )
/*! @brief TSI electrodes pins */
#define gKBD_TsiElecList_d {4U, 7U}

/* The PWM channels used for RGB LED */
#ifndef BOARD_USE_PWM_FOR_RGB_LED
#define BOARD_USE_PWM_FOR_RGB_LED       1
#endif

#ifndef gStackTimerInstance_c
#define gStackTimerInstance_c           1
#endif
#ifndef gRedLedPwmTimerInstance_c
#define gRedLedPwmTimerInstance_c       0
#endif
#ifndef gGreenLedPwmTimerInstance_c
#define gGreenLedPwmTimerInstance_c     2
#endif
#ifndef gBlueLedPwmTimerInstance_c
#define gBlueLedPwmTimerInstance_c      2
#endif

#ifndef gRedLedPwmTimerChannel_c
#define gRedLedPwmTimerChannel_c        2
#endif
#ifndef gGreenLedPwmTimerChannel_c
#define gGreenLedPwmTimerChannel_c      1
#endif
#ifndef gBlueLedPwmTimerChannel_c
#define gBlueLedPwmTimerChannel_c       0
#endif
/* Index into the ledPins[] array */
#ifndef gRedLedIdx_c
#define gRedLedIdx_c                    1
#endif
#ifndef gGreenLedIdx_c
#define gGreenLedIdx_c                  2
#endif
#ifndef gBlueLedIdx_c
#define gBlueLedIdx_c                   3
#endif

#define BOARD_BNO055_INT_PIN			19U
#define BOARD_BNO055_INT_GPIO			GPIOC
#define BOARD_BNO055_INT_GPIO_PORT		gpioPort_C_c
#define BOARD_BNO055_INT_PORT			PORTC

#define BOARD_GPS_TIMEPULSE_PIN			1U
#define BOARD_GPS_TIMEPULSE_GPIO		GPIOC
#define BOARD_GPS_TIMEPULSE_GPIO_PORT	gpioPort_C_c
#define BOARD_GPS_TIMEPULSE_PORT		PORTC

#define BOARD_GPS_nCS_PIN				5U
#define BOARD_GPS_nCS_GPIO				GPIOC
#define BOARD_GPS_nCS_PORT				PORTC

#define BOARD_I2C_EMBEDDED_SENSORS_BASEADDR I2C0
#define BOARD_I2C_EMBEDDED_SENSORS_CLK_SRC I2C0_CLK_SRC
#define BOARD_I2C_EMBEDDED_SENSORS_CLK_FREQ CLOCK_GetFreq(I2C0_CLK_SRC)
#define BOARD_I2C_EMBEDDED_SENSORS_BAUDRATE 400000U

#define gADC16_ReferenceVoltageSource_d kADC16_ReferenceVoltageSourceValt

#if defined(__cplusplus)
extern "C"
{
#endif /* __cplusplus */

/************************************************************************************
 *************************************************************************************
 * Public prototypes
 *************************************************************************************
 ************************************************************************************/

void hardware_init(void);

/* Function to initialize ADC on board configuration. */
void BOARD_InitAdc(void);

/**
 * @brief Initialize the I2C used by all sensors on the board.
 * The configuration is the following:
 * masterConfig.baudRate_Bps = 100000U;
 * masterConfig.enableStopHold = false;
 * masterConfig.glitchFilterWidth = 0U;
 * masterConfig.enableMaster = true;
 *
 */
status_t BOARD_InitI2CEmbeddedSensors(void);

/**
 * @brief Get the current i2c handler for all the sensors on the board.
 * The handler is thread safe.
 * 
 * @return i2c_rtos_handle_t* I2C handler to be used to read/write
 */
i2c_rtos_handle_t* BOARD_GetI2CEmbeddedSensorsHandle(void);

/**
 * @brief Initialize the DCDC if used.  
 */
void BOARD_DCDCInit(void);

/* Function to read battery level on board configuration. */

/**
 * @brief Get the battery level if we are in DCDC mode
 * connected on the channel ADC16_BATLVL_CHN
 * 
 * @param void 
 * @return uint8_t Battery pourcentage
 */
uint8_t BOARD_GetBatteryLevelDCDC(void);
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

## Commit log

2017-07-05 [Hardware] DevBox Altium Project
    [GPS.SchDoc, LoRa.SchDoc, MCU.SchDoc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]
2017-07-05 [Hardware] Altium project configuration files
    [SmartCantonDevBox_V1_0.PrjPCB]
2017-08-07 Hardware comparaison file
    [hardware_comparaison.xlsx]
2017-08-07 [Hardware] Altium project with almost all main components
    Components implemented :
    - LoRa Module
    - Bluetooth Module
    - GPS
    - LEDs and buttons
    - Environnemental sensor
    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
    [EmbeddedPeripherals.SchDoc, GPS.SchDoc, LoRa.SchDoc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]
2017-09-09 [Hardware] Schematic version 1 ready
    The layout has been started, but no routing has been done yet, only components placement.
    [EmbeddedPeripherals.SchDoc, GPS.SchDoc, LoRa.SchDoc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]
2017-09-10 [Hardware] Board size set and components placed almost in final place
    [SmartCantonDevBox.PcbDoc]
2017-10-04 [PCB] Final version sent to production
    [EmbeddedPeripherals.SchDoc, GPS.SchDoc, LoRa.SchDoc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]
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2017-10-04 Gant planning
    [Planning_Gantt.xlsx]
2017-10-04 [PCB] Bill of materials Mouser
    [bill_of_materials.xlsx]
2017-10-04 [Doc] Wireless MCU comparaison
    [MCU_Comparaison.xlsx]
2017-10-04 [LoRa] Example TheThingsNetwork with STM32 dev kit
    [B-L072Z-LRWAN1.cfg]
2017-10-04 [LoRa] Configuration LoRa with The Things Network
    [B-L072Z-LRWAN1.cfg]
2017-10-17 [Doc] MCU comparaison update
    [MCU_Comparaison.xlsx]
2017-10-17 [Doc] Matrix Pin out excel
    [frdm-kw41z_reva3_pinout_mbed.xlsx]
2017-10-17 Case to contain the PCB
    [SmartCantonDevBoxCase.FCStd]
2017-10-17 [Doc] Notes updates with last PCB errors
2017-10-20 [Doc] Gantt Planning last version with use cases
    [Planning_Gantt.xlsx]
2017-10-24 [LoRa] Adding new project name AT_Slave and removing usseless files
    This project as been heavily modified to use the UART1 on pin PA9 and PA10 instead of the LPUART1
    The files mainly modified were vcom.c and vcom.h
    [B-L072Z-LRWAN1.cfg]
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2017-10-24 [Doc] Comparaison not used anymore
    [hardware_comparaison.xlsx]
2017-10-24 [Doc] Gantt Planning update
    [Planning_Gantt.xlsx]
2017-10-24 [Case] Update PCB case design
    [SmartCantonDevBoxCase2.FCStd]
2017-10-24 Remove ignored files
    [PowerSupply.SchDoc, SmartCantonDevBox.PcbDoc, SmartCantonDevBox_V1_0.PrjPCB]
2017-10-24 [KW41z] Heart sensor project as base to start development
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2017-10-25 [Doc] Documentation explaining how to link the board folder
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2017-10-26 [KW41z] Disable PowerDown mode to enable the LEDs to flash at the start
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2017-10-27 [KW41z] Pin mux updated with respect to the initial pin mux functions
2017-10-27 [KW41z] Project working with the buttons on the DevBox
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2017-10-31 [KW41z Doc] MCUXpresso and Kinetis SDK documentation
    [MCUXpresso Supported Devices Table (LPC54102 June 2017).xlsx]
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2017-11-07 [KW41z] Fixing ATCommander library to accept STM32 AT commands
    Also, fixing the fact that a response with 1 byte could not be read with the library.
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2017-11-08 [KW41z] Bluetooth Developer Studio default project
    [com.hepia.characteristic.lora_app_eui.xml, com.hepia.characteristic.lora_app_key.xml, com.hepia.descriptor.lora_app_eui_new_descriptor.xml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]
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2017-11-11 [BLE] Update BLE profil with new LoRa parameters
    [com.hepia.characteristic.lora_app_eui.xml, com.hepia.characteristic.lora_app_key.xml, com.hepia.descriptor.lora_app_key_new_descriptor.xml]
2017-11-14 [KW41z] BLE LoRa now support more characteristics
    NWK session key
    App session key
    Dev Addr
    Confirm Packet Mode
    [com.hepia.characteristic.lora_app_session_key.xml, com.hepia.descriptor.lora_app_session_key_descriptor.xml]
2017-11-15 [KW41z] BLE modifying service and chars UUID
    [com.hepia.characteristic.lora_app_eui.xml, com.hepia.characteristic.lora_app_key.xml, com.hepia.characteristic.lora_app_session_key.xml]
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2017-11-24 [KW41z] GPS service with strings instead of floats
    [com.hepia.descriptor.lora_app_key_new_descriptor.xml, com.hepia.descriptor.lora_app_session_key_descriptor.xml]
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2017-11-29 [KW41z] BM680 using RTOS I2C for communication and has his own task
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2017-12-11 [Serv] Serveur now support device management
    [GET] /device get list of all devices owned
    [GET] /device/<eui> get specific device informations
    [POST] /device/<eui> Post new device to database
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2017-12-23 [KW41z] BME680 fix time overflow
    [bme680_bsec_support.c]
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2017-12-24 [KW41z] Fixing bug with data temperature not sent on the LoRa packet
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2017-12-26 [KW41z] Fix gyro function acsquisistion
2017-12-27 [KW41z] Remove the possibility to notified Raw humidity and temperature
    It's because we can only have 16 characterics as notifications
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2017-12-27 [KW41z] Remove the NVM reset at the startup
    [ApplMain.c]
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2017-12-27 [Android] Read the measure delay from the device and add units to values
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2017-12-28 [KW41z] Fix negative value from battery level compute
    [board.c]
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2017-12-29 [KW41z] Fixing LEDs IDs to be correct with the board silkscreen
    [gpio_pins.c]
2017-12-30 [KW41z] The Led 2 can now be controller using the Cayenne Dashboard
2017-12-30 [KW41z] Adding the full BLE stack support to be able to scan devices
2017-12-31 [Android] Advertisers started as a thread to prevent UI problems
2018-01-02 [KW41z] Fixing the LoRaWAN controller multiple frames bug
2018-01-02 [KW41z] Thread safe write fix on BLE device count
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2018-01-29 [Doc] Ble service documentation
    [ble_services_documentation.xlsx]
2018-01-29 [PCB] Now each sheet has his number
    [EmbeddedPeripherals.SchDoc, GPS.SchDoc, LoRa.SchDoc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]
2018-01-29 [BDS] Bluetooth Studio Project moved to his own sub directory
    [com.hepia.characteristic.lora_app_eui.xml, com.hepia.characteristic.lora_app_key.xml, com.hepia.characteristic.lora_app_session_key.xml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]
2018-02-09 [Doc] Panning updated
    [Planning_Gantt.xlsx]
2018-05-11 Removing planning
    [Planning_Gantt.xlsx]
